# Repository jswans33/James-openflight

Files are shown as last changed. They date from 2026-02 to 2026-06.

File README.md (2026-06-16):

<p align="center">

  DIY Golf Launch Monitor using the OPS243-A Doppler Radar.
</p>

<p align="center">
  <a href="https://buymeacoffee.com/colemangolfs">
    
  </a>
</p>

> [!WARNING]
> **This project is in active development.** Features may be incomplete, unstable, or change without notice. Contributions and bug reports are welcome!

## Overview

OpenFlight is an open-source golf launch monitor that uses Doppler radar to measure ball speed, club speed, launch angle, spin rate, and carry distance.

### What It Measures

- **Ball Speed**: 35-200 mph range with ±0.5% accuracy (OPS243-A)
- **Club Speed**: Detected from pre-impact readings (OPS243-A)
- **Smash Factor**: Ball speed / club speed ratio
- **Launch Angle**: Vertical launch measured by K-LD7 angle radar
- **Club Path**: Horizontal aim direction measured by second K-LD7
- **Spin Rate**: Via rolling buffer I/Q analysis (the hardest radar measurement — see [Limitations](#limitations))
- **Carry Distance**: Computed from ball speed, launch angle, and spin

### Hardware at a Glance

| Component | What it does | ~Cost |
|---|---|---|
| OPS243-A Radar | Ball speed, club speed, spin | $249 |
| Raspberry Pi 5 | Runs everything | $60 |
| 7" Touchscreen | Shows shot data | $46 |
| SparkFun SEN-14262 | Impact sound trigger for shot capture | $18 |
| K-LD7 (×2) + FTDI adapters | Launch angle + club path | $140 |
| Power supply + accessories | | $27 |
| **Total** | | **~$540** |

> The K-LD7 angle radars are optional. Without them you still get ball speed, club speed, smash factor, spin rate, and estimated carry. See the [full parts list](docs/PARTS.md) for details and links.

## Getting Started

### 1. Get the parts

See the **[Parts List](docs/PARTS.md)** for everything you need with purchase links.

### 2. Wire it up

Follow the **[Sound Trigger Wiring Guide](docs/sound-trigger-wiring.md)** to connect the SEN-14262 to the OPS243-A. The K-LD7 modules connect via USB — no wiring needed.

### 3. Set up the Pi

Flash Raspberry Pi OS (64-bit), plug in the radars, then run the interactive setup:

```bash
git clone https://github.com/jewbetcha/openflight.git
cd openflight
./scripts/setup/setup.sh
```

The script installs everything and walks you through the one-time hardware
configuration (radar flash setup, K-LD7 device naming, auto-start) with
prompts — no manual config editing needed. It's safe to re-run any time.
See the **[Raspberry Pi Setup Guide](docs/raspberry-pi-setup.md)** for
details and troubleshooting.

### 4. Hit balls

```bash
# Default: rolling buffer mode with sound trigger
scripts/start-kiosk.sh

# With K-LD7 launch-angle geometry defaults
scripts/start-kiosk.sh --kld7-geometry

# Development mode (no hardware)
scripts/start-kiosk.sh --mock
```

Then open http://localhost:8080 or use the touchscreen.

### 5. Sync to the cloud (optional)

OpenFlight can push your sessions to the **FlightWeb** cloud so you can review
shots from any device. It's opt-in, and **raw radar data never leaves your
Pi** — only shot results and session metadata are uploaded (verify with
`openflight-cloud push --dry-run`).

`setup.sh` offers to enable this and link your Pi. To do it by hand:

```bash
openflight-cloud link       # pair this Pi (enter a short code in your browser)
openflight-cloud status     # linked? queued? parked?
```

Once linked, sessions sync automatically (on session end and via a ~10-minute
timer that heals wifi outages). See the **[Cloud Sync Guide](docs/cloud-sync.md)**
for details.

### TV Display Mode

OpenFlight also serves a fullscreen-friendly browser display for tablets, TV browsers, or a Chrome tab cast to Chromecast.

1. Start OpenFlight as usual with `scripts/start-kiosk.sh`.
2. Find the OpenFlight host IP address on your LAN.
3. Open `http://<openflight-host-ip>:8080/display` from another laptop, tablet, or TV browser.
4. For Chromecast, open the display page in Chrome and use Chrome's built-in **Cast** feature to cast the tab.

This is browser/tab casting only. OpenFlight does not include native Cast SDK support yet.

## How It Works

### System Architecture

```
┌─────────────┐  USB/Serial  ┌─────────────┐  Callback   ┌─────────────┐  WebSocket  ┌─────────────┐
│  OPS243-A   │ ───────────▶ │   Rolling   │ ──────────▶ │   Flask     │ ──────────▶ │   React     │
│   Radar     │  I/Q buffer  │   Buffer    │  on_shot()  │   Server    │   "shot"    │     UI      │
└─────────────┘              │   Monitor   │             └─────────────┘             └─────────────┘
                             └─────────────┘
                                                               ▲
┌─────────────┐  USB/Serial                                    │
│ K-LD7 (×2)  │ ──────────────────── angle data ──────────────┘
│ Angle Radar │
└─────────────┘
```

1. **Sound trigger fires** — SEN-14262 detects club impact, triggers OPS243-A HOST_INT
2. **OPS243-A dumps buffer** — Rolling buffer I/Q data is captured and analyzed for ball speed, club speed, and spin
3. **K-LD7 correlates** — The server uses the OPS243-A impact timestamp to find the matching ball burst in the K-LD7 ring buffer, extracting launch angle and club path
4. **Carry computed** — Ball speed + spin + launch angle → carry distance
5. **UI updates** — Shot data emitted via WebSocket to the React frontend

### Doppler Radar Basics

The OPS243-A transmits a 24 GHz signal. When it bounces off a moving object (the golf ball), the frequency shifts proportionally to the object's speed — this is the Doppler effect. At 24.125 GHz, each 1 mph of speed creates a ~71.7 Hz Doppler shift.

### Positioning

Place the radar **3-5 feet behind the tee**, pointing at the hitting area:

```
                Ball Flight Direction
                ======================>

[Tee]  ←--- 3-5 ft ---→  [OPS243-A]  [K-LD7 vertical]  [K-LD7 horizontal]
```

The K-LD7 modules are positioned near the OPS243-A, one mounted vertically (launch angle) and one horizontally (club path / aim direction).

## Configuration

### Radar Settings for Golf

| Setting | Value | Why |
| --- | --- | --- |
| Mode | Rolling buffer | Raw I/Q capture for spin + precise speeds |
| Sample Rate | 30 ksps | Supports up to ~208 mph ball speed |
| Capture | 4096 I/Q samples | ~136 ms around impact |
| Trigger | Sound (SEN-14262) | ~10 µs hardware latency via HOST_INT |
| Min Ball Speed | 35 mph | Filter club waggle and slow movements |
| DC Mask | ~15 mph exclusion zone | Reject body movement and environmental noise |

These are applied automatically — the one-time flash configuration is handled
by the setup script.

### Python API

```python
from openflight.rolling_buffer import RollingBufferMonitor

monitor = RollingBufferMonitor()   # auto-detects the OPS243-A
monitor.connect()
monitor.start()

print("Swing when ready...")
shot = monitor.wait_for_shot(timeout=60)
if shot:
    print(f"Ball Speed: {shot.ball_speed_mph:.1f} mph")
    print(f"Est. Carry: {shot.estimated_carry_yards:.0f} yards")

monitor.stop()
monitor.disconnect()
```

## Limitations

- **Cosine error**: If ball doesn't travel directly toward/away from radar, measured speed will be slightly lower than actual
- **Spin detection**: The hardest radar measurement, especially indoors — the usable signal window ends when the ball hits the net, and short windows can't resolve low spin (commercial radar units have the same constraint and fall back to estimated spin indoors). Low driver-band readings (≤~3100 RPM) are reported at reduced confidence. When spin isn't measured, carry falls back to club-typical spin values. Improving this is an active focus.
- **K-LD7 speed aliasing**: The K-LD7 max speed is 62 mph, so it's used only for angle/distance, not speed

### Ball Markings

Reflective markings (aluminum stickers, painted dots) noticeably improve K-LD7 launch-angle extraction — the stronger return gives multi-frame tracking, higher SNR, and more confident angles. However, a specular patch produces a pulsed, non-sinusoidal amplitude modulation that the spin detector can't interpret as seam modulation, so measured spin degrades (typically locks to the top of the valid frequency band with low confidence). Low-confidence spin automatically falls back to club-typical values in the ballistics model, so the net effect of marking a ball is better angles with no worse carry estimates. A thin painted stripe (rather than a patch) is a reasonable middle ground if you want both — it rotates through the beam more like a seam.

## Hardware Diagnostic

To verify every component of your build in one shot:

```bash
uv run python scripts/hardware-test/diagnose.py
```

The diagnostic walks through 6 checks:
1. OPS243 connectivity
2. OPS243 rolling buffer mode persistence
3. OPS243 software trigger
4. K-LD7 vertical (launch angle)
5. K-LD7 horizontal (aim direction, optional)
6. Sound trigger end-to-end (interactive — prompts you to clap near the sensor)

Missing optional hardware (like the horizontal K-LD7) is reported as a skip rather than a failure. Pass `--require-all` to fail on skips, or `--no-interactive` to skip the sound-trigger prompt in unattended runs.

## Project Structure

```
openflight/
├── src/openflight/
│   ├── ops243.py              # OPS243-A radar driver
│   ├── launch_monitor.py      # Shot detection & club/ball separation
│   ├── server.py              # Flask server, K-LD7 correlation, carry
│   ├── session_logger.py      # JSONL session logging
│   ├── kld7/                  # K-LD7 angle radar
│   │   ├── radc.py            # FFT, phase interferometry, angle extraction
│   │   ├── tracker.py         # Ring buffer, shot correlation
│   │   ├── geometry.py        # Launch-angle trajectory fitting
│   │   └── types.py           # Data types
│   └── rolling_buffer/        # Spin rate detection
│       ├── monitor.py         # Rolling buffer monitor
│       ├── processor.py       # I/Q processing for spin
│       ├── trigger.py         # Trigger strategies
│       └── types.py           # Data types
├── ui/                        # React frontend
├── scripts/                   # Utility & setup scripts
├── docs/                      # Documentation
└── pyproject.toml
```

## Contributing

Contributions welcome! See [CONTRIBUTING.md](CONTRIBUTING.md) for guidelines.

Areas of interest:

- **Better spin detection**: A dechirped Doppler-sideband estimator is in development (`scripts/analysis/replay_spin_dechirp.py`) — help validating it against launch-monitor truth data is especially welcome
- **K-LD7 signal processing**: Improve ball detection from sparse radar frames
- **Mobile app**: Bluetooth connection to phone

### Running Tests

```bash
uv run pytest tests/ -v
```

## Documentation

- **[Parts List](docs/PARTS.md)** — What to buy
- **[Sound Trigger Wiring](docs/sound-trigger-wiring.md)** — How to wire the sound trigger
- **[Raspberry Pi Setup](docs/raspberry-pi-setup.md)** — Full setup guide
- **[Cloud Sync](docs/cloud-sync.md)** — Push filtered sessions to FlightWeb
- **[Rolling Buffer & Spin Detection](docs/rolling_buffer_spin_detection.md)** — Spin measurement details
- **[Dechirped-Sideband Spin Replay](docs/spin-dechirp-replay.md)** — Next-gen spin estimator test bench
- **[K-LD7 Ball Detection Theory](docs/kld7-ball-detection-theory.md)** — How angle detection works
- **[K-LD7 Session Review](docs/kld7-session-review.md)** — Offline review workflow for session JSONL files
- **[Observability & Log Shipping](docs/observability.md)** — Ship logs to Grafana Cloud
- **[Contributing Guide](CONTRIBUTING.md)** — How to contribute
- **[Changelog](docs/CHANGELOG.md)** — Version history

## License

GNU Affero General Public License v3.0 or later (AGPL-3.0-or-later) - see LICENSE file.

## Acknowledgments

- [OmniPreSense](https://omnipresense.com/) for the OPS243-A radar and documentation
- The golf hacker community for inspiration

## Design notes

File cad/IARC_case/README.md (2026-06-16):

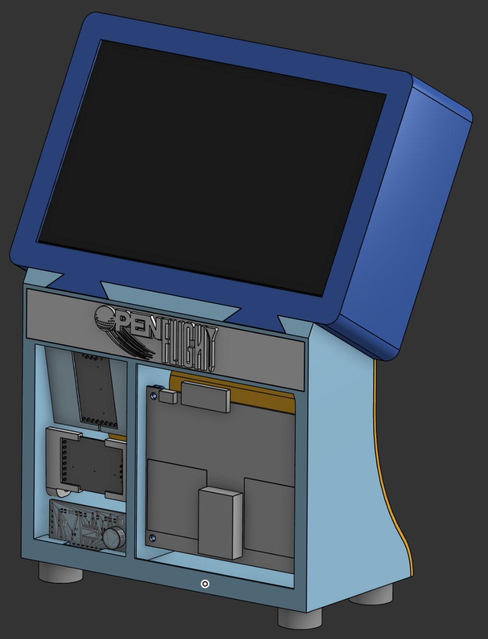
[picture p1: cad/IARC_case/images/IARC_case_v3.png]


- M5 Bolts needed: 10
- M2.5 Bolts needed: 12

Instructions for OpenFlight IARC v3 Case Build
  
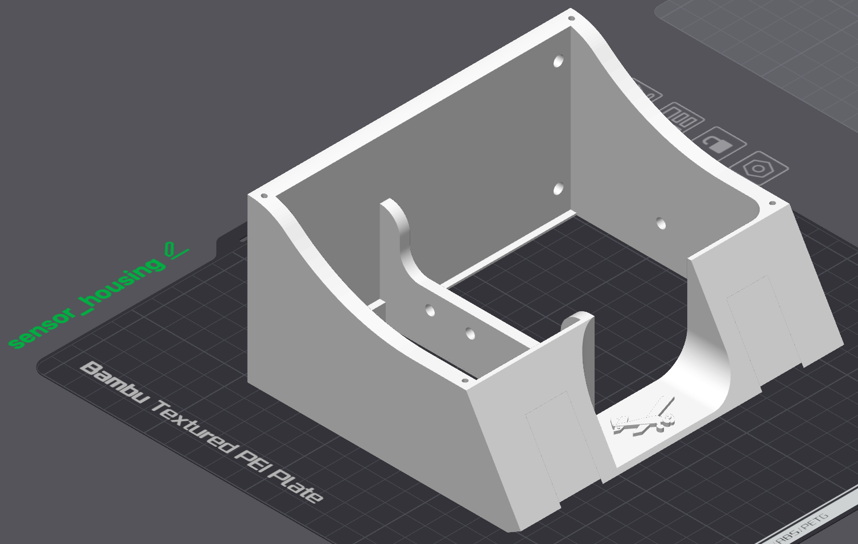
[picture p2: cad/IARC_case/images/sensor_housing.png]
1. Print out `sensor_housing.stl` 
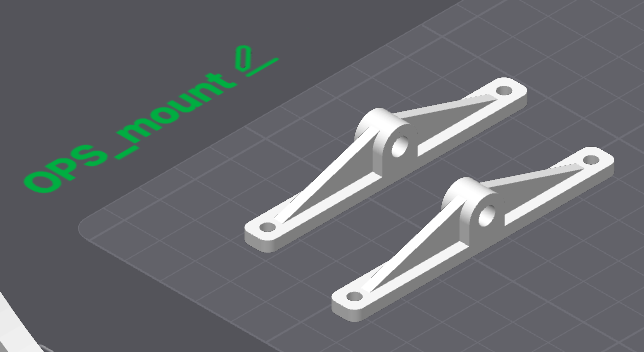
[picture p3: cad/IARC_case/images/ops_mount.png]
2. Print out (2x) `OPS_mount.stl` 
3. Secure the OPS sensor to each `OPS_mount.stl` part with screws (I don't know which ones)
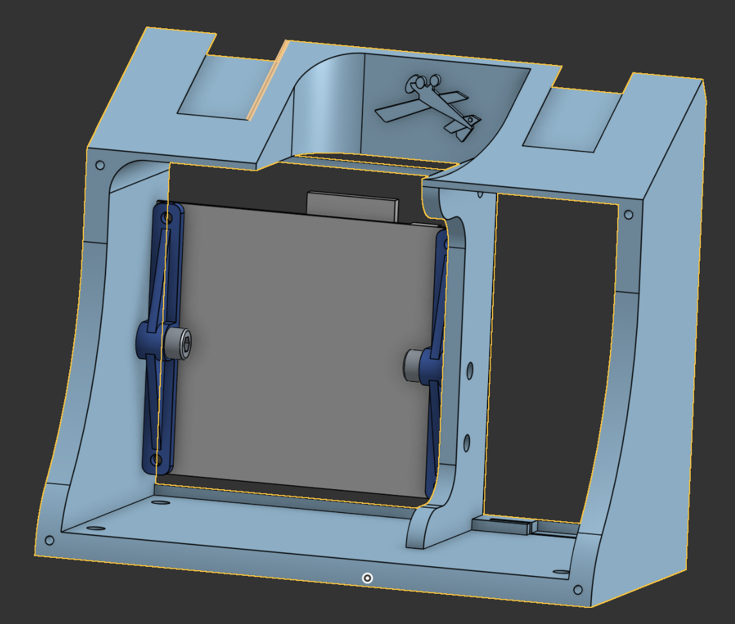
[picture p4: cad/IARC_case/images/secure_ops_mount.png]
4. Secure the `OPS_mount.stl` parts to the `sensor_housing.stl` part with (2x) M5 bolt 
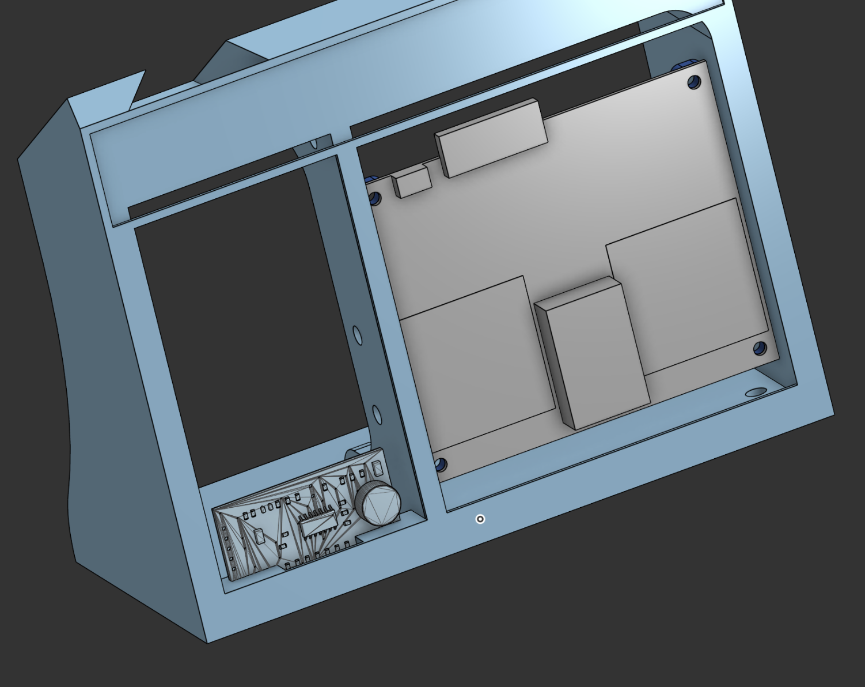
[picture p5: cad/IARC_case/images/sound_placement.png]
5. Fit the sound sensor into the little slot on the left side of the `sensor_housing.stl` part. 
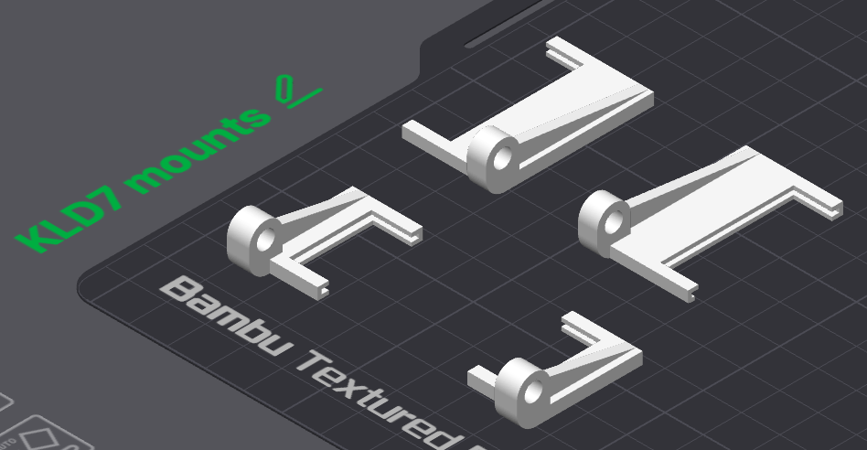
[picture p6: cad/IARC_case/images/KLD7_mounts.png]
6. Print out (1x) `KLD7_h_mount_L_v2.stl` and (1x) `KLD7_h_mount_R_v2.stl` 
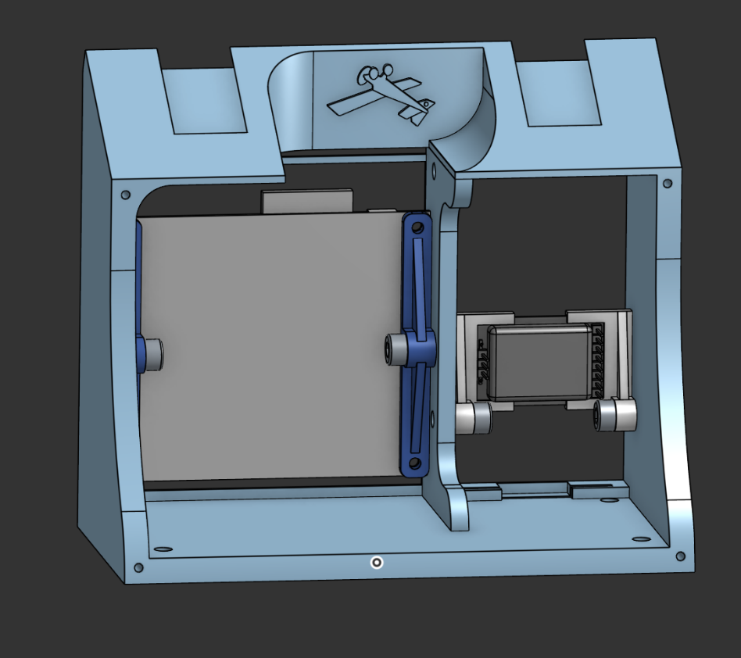
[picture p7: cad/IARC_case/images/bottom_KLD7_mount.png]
7. Slot a KLD7 sensor between the mount parts, and secure them to the `sensor_housing.stl` part with (2x) M5 bolt 
8. Print out (1x) `KLD7_v_mount_L_v2.stl` and (1x) `KLD7_v_mount_R_v2.stl` 
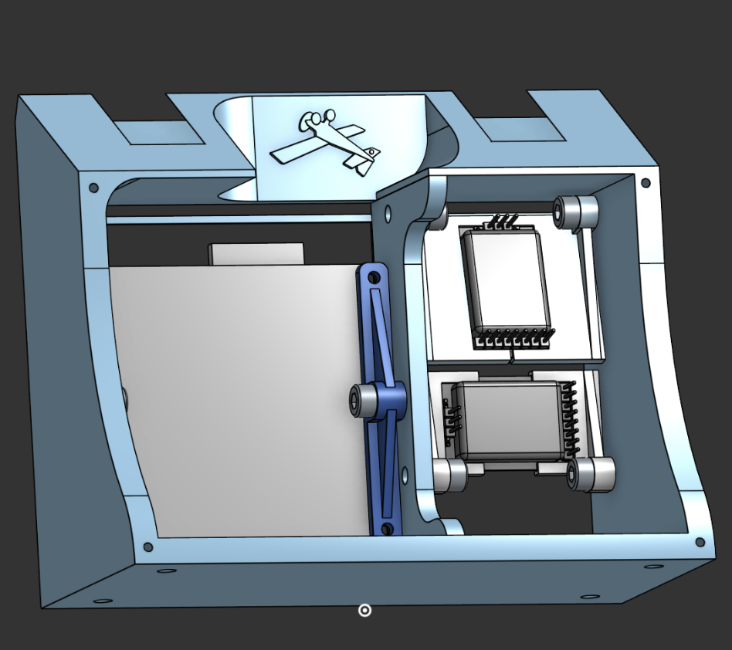
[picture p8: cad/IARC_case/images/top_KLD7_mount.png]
6. Slot a KLD7 sensor between the mount parts, and secure them to the `sensor_housing.stl` part with (2x) M5 bolt 
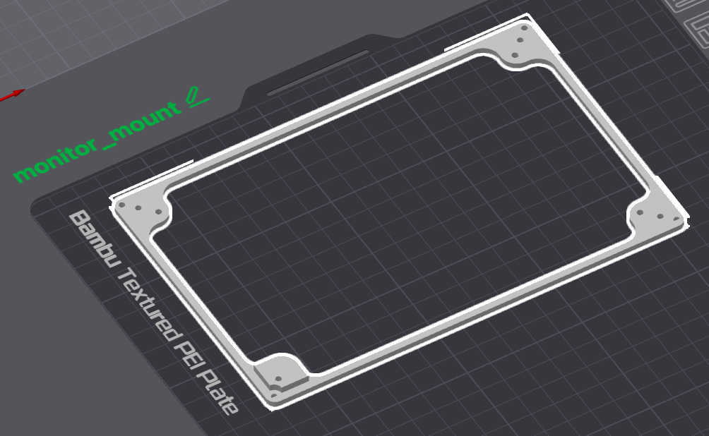
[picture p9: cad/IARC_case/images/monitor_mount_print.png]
7. Print out the `monitor_mount.stl` part. 
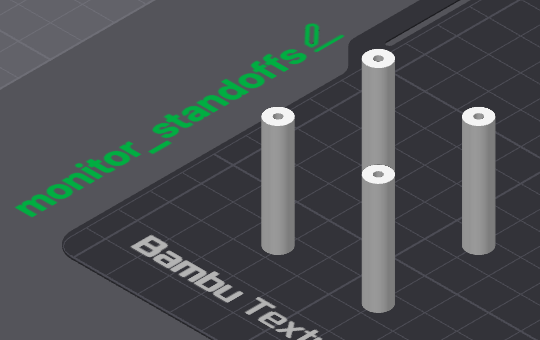
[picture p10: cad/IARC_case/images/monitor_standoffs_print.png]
8. Print out (4x) `monitor_standoffs.stl`'s. 
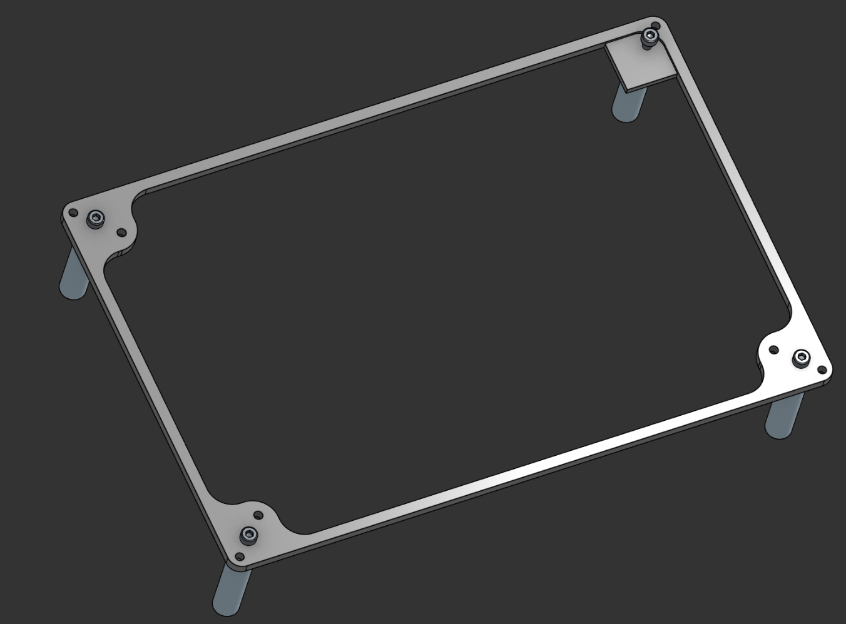
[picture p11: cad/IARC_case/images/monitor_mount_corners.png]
9. Secure each `monitor_standoff.stl` part to the corners of the `monitor_mount.stl` part with (1x) M2.5 bolt. 
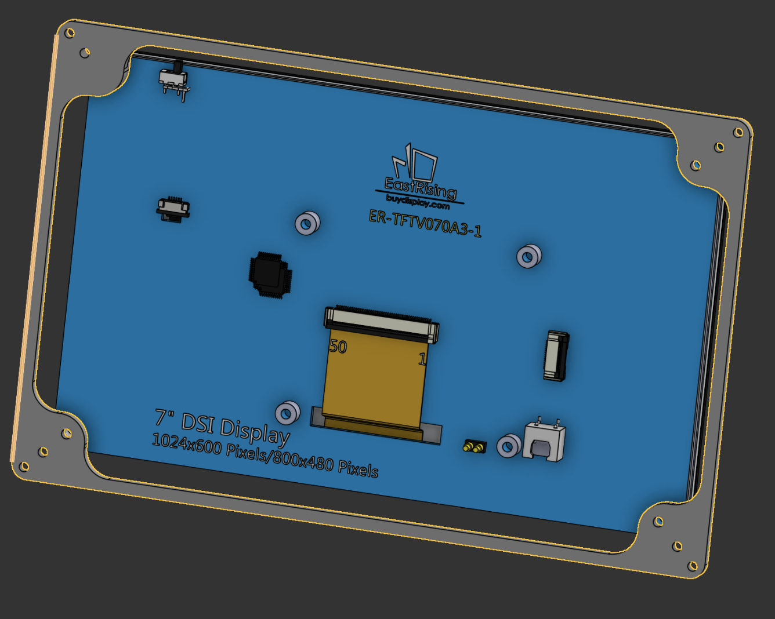
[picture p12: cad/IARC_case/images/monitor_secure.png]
10. Secure the monitor to the `monitor_mount.stl` part. 
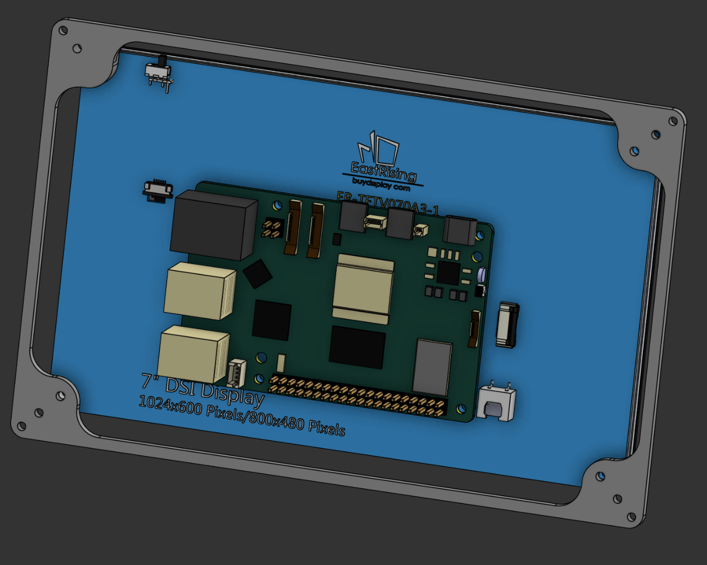
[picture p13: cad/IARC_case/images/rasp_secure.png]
11. Secure the raspberry Pi to the monitor. 
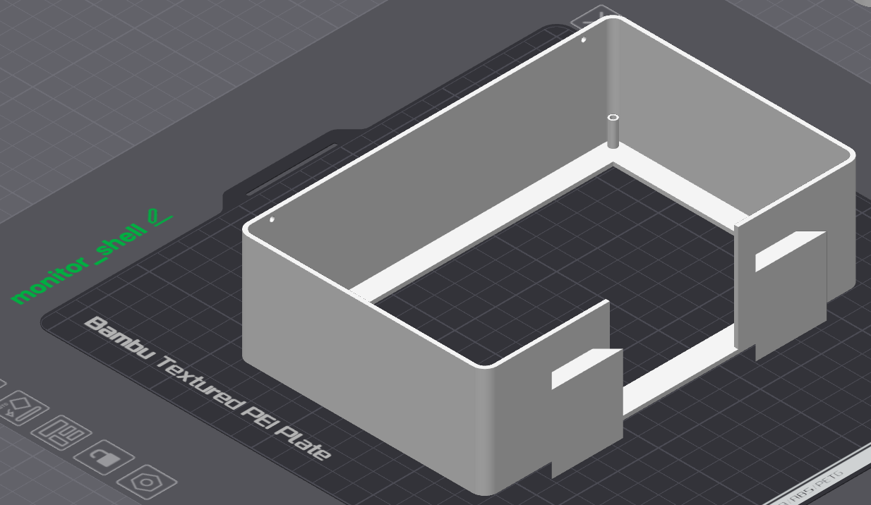
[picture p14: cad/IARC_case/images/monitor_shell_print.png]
12. Print out the `monitor_shell.stl` part. 
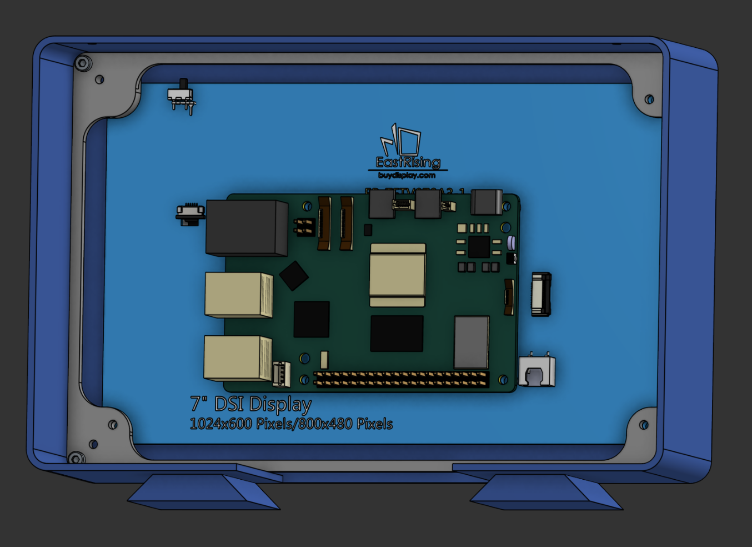
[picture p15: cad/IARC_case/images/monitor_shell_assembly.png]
13. Secure the monitor assembly inside the `monitor_shell.stl` part with (4x) M2.5 bolts at the corners. 
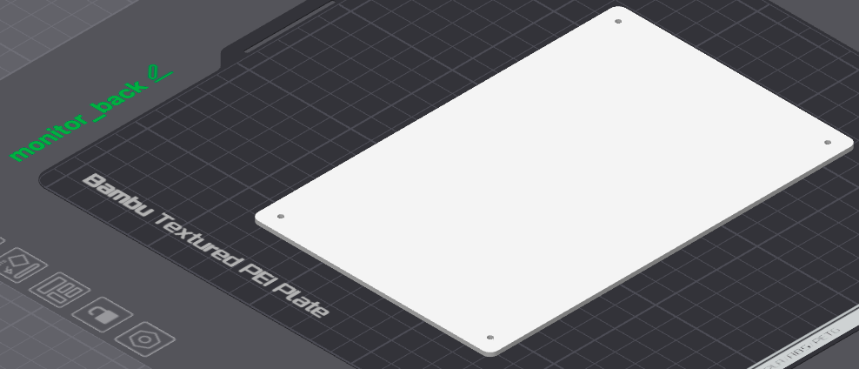
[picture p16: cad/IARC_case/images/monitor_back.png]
14. Print out the `monitor_back.stl` part. 
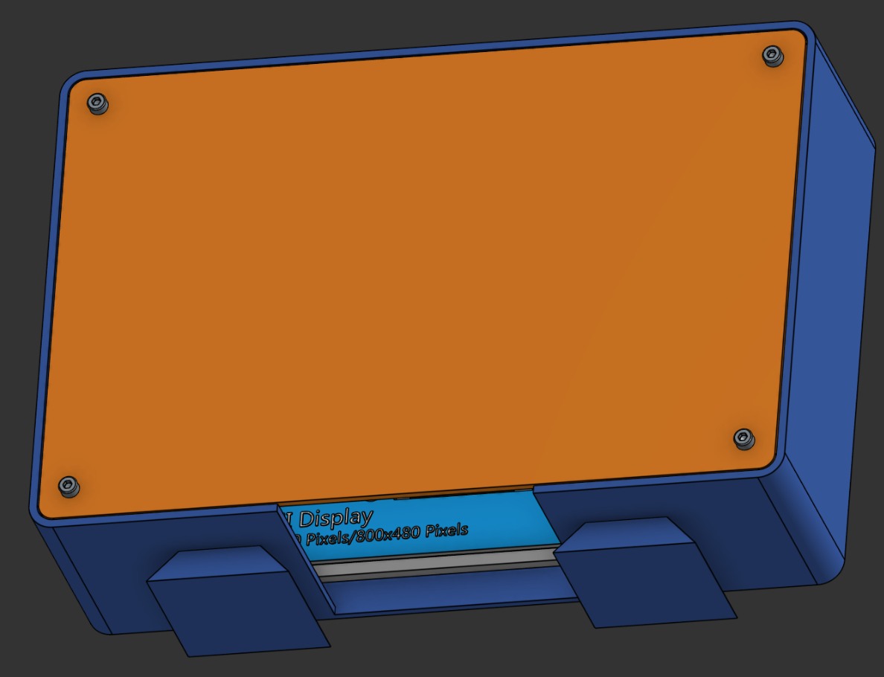
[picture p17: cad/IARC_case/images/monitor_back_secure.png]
15. Secure the `monitor_back.stl` part to the `monitor_standoffs.stl` parts with (4x) M2.5 bolts. 
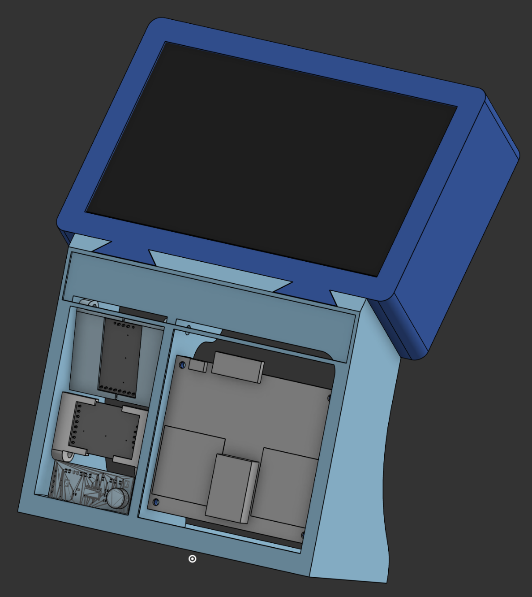
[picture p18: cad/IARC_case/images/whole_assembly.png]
16. Slide the whole assembly into the sensor housing assembly, using the dovetails to align everything together. 
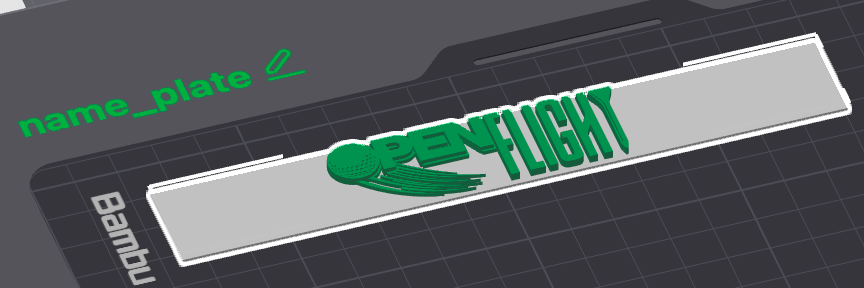
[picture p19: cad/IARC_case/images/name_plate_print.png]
17. Print out the `name_plate.stl` file. 
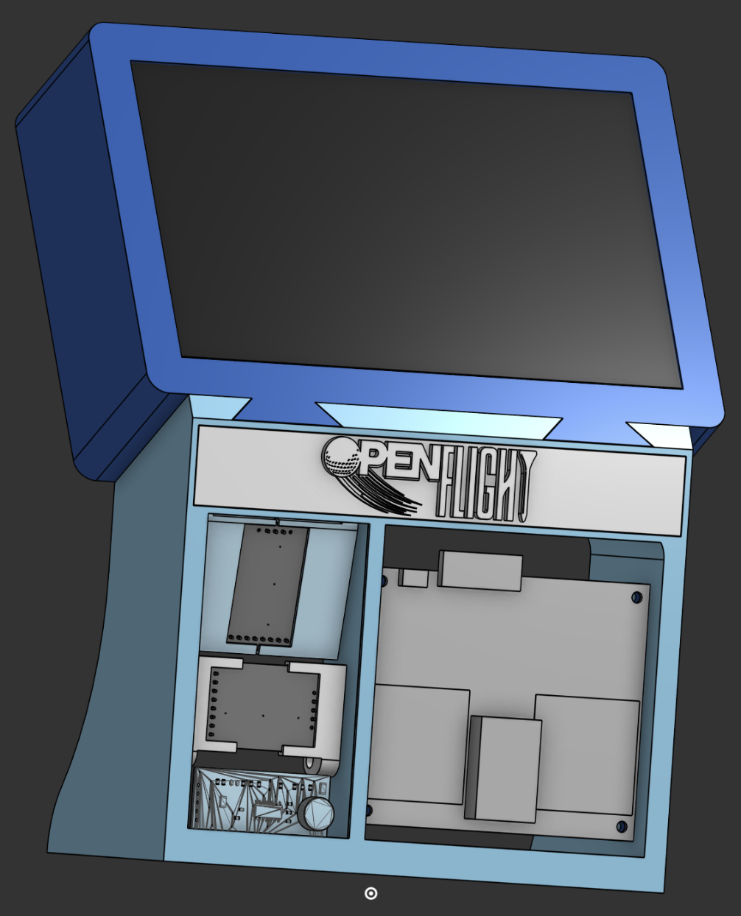
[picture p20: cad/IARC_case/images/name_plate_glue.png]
18. Secure the `name_plate.stl` file to the front of the whole assembly with glue. 
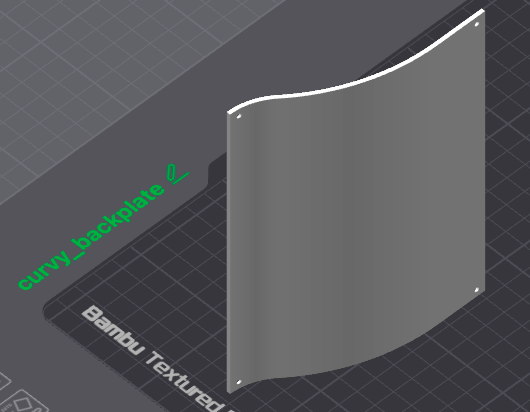
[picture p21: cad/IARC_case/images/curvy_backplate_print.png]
19. Print out the `curvy_backplate.stl` file. 
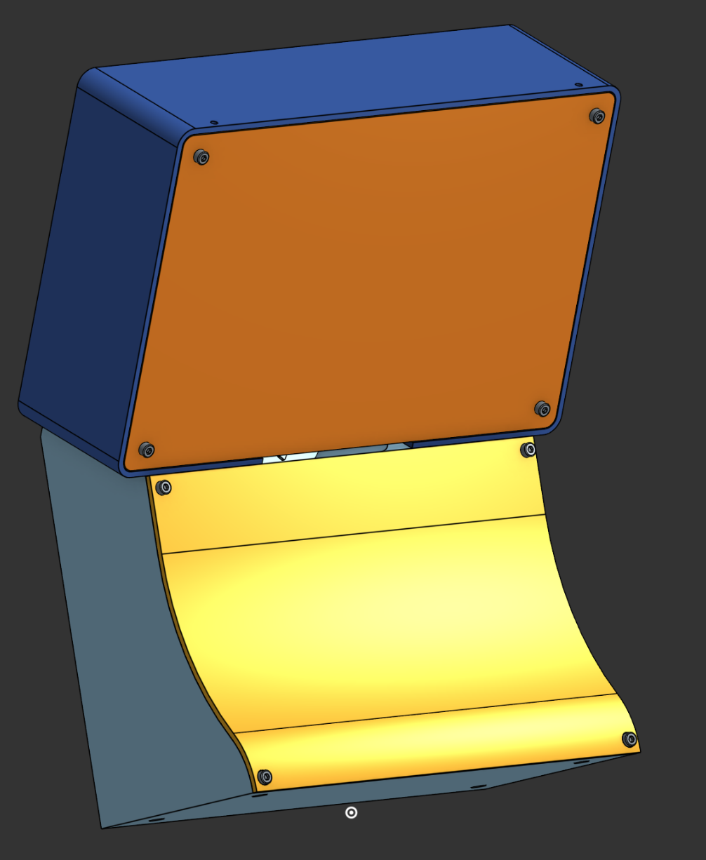
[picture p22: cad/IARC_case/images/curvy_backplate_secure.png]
20. Secure the `curvy_backplate.stl` file to the whole assembly with (4x) M2.5 bolts. 
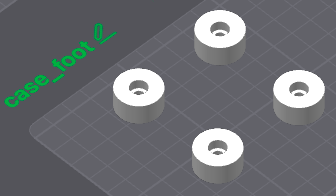
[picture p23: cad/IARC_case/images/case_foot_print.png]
21. Print out (4x) `case_foot.stl` parts. 
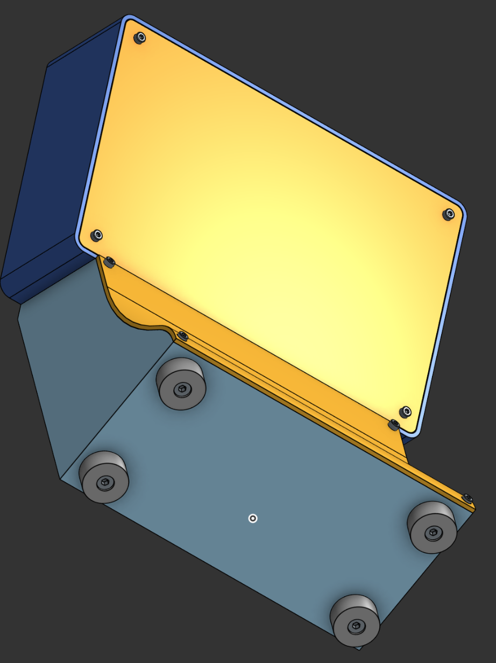
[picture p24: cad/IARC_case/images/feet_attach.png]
22. Secure each foot to the bottom of the whole assembly with (4x) M5 Bolts. 

And that’s how you put together the 3d printed parts!

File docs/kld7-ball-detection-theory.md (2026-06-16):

# K-LD7 Ball Detection Theory

## Problem

The RFbeam K-LD7 is being used to estimate launch angle and club angle of attack
from raw `PDAT` and `TDAT` frames captured during a golf swing. The hard part is
not whether the radar sees *anything* during a swing. It does. The hard part is
separating the brief golf-ball return from stronger club, body, and net returns.

The four captures in `session_logs/` confirmed that the ball data is present, but
it does not appear as the strongest target in the raw stream. A simple
"highest-magnitude target wins" rule is wrong for this use case.

## Why The Raw Radar Data Is Tricky

### 1. Speed aliases at golf-ball velocity

The K-LD7 max speed setting is `100 km/h`. Golf balls travel much faster than
that, so the reported speed is aliased and cannot be trusted as a true physical
ball speed. This means the detector must treat speed as a *weak filter* rather
than a direct measurement.

Practical implication:

- `speed` can be used to reject obviously slow clutter
- `speed` cannot be used to estimate actual launch speed
- `distance` and `timing` matter more than `speed`

### 2. The ball only exists for a few frames

At the current radar settings the frame rate is roughly `34 fps`, so a full-speed
ball often appears in only `1-3` frames. By contrast, the golfer's body, club,
and follow-through can occupy many more frames and often produce stronger returns.

Practical implication:

- `TDAT` alone is not enough
- `PDAT` is the primary source for the ball
- the detector must be built around short bursts, not long tracks

### 3. A single "ball burst" can still contain multiple far targets

Even after filtering for far-range, fast targets, a burst can still contain
multiple plausible `PDAT` returns in the same frame. These likely come from a
mix of ball, net, multipath, and other transient reflections. Averaging every
qualifying far target together smears the angle and produces unstable output.

Practical implication:

- burst selection is not enough
- one coherent target path must be chosen *inside* the burst

## What The Captures Showed

Across the four captures, the most repeatable signature was:

1. A close-range speed transition at roughly `0.8-2.5 m`
2. Followed `120-350 ms` later by a far-range burst at roughly `4.1-4.6 m`
3. The far-range burst usually carried lower magnitude than the club event

This pattern is the key breakthrough. The ball should not be found by asking
"what is strongest in the whole buffer?" It should be found by asking:

> "What plausible far-range burst appears immediately after a plausible club event?"

That turns the detection problem from one giant classification problem into a
sequence problem.

## Detector Strategy

The current detector is built around four stages.

### Stage 1: Ball candidate filter

A target is considered a possible ball only if it is:

- fast enough to reject slow clutter
- far enough away to avoid close-range club/body returns
- strong enough to avoid obvious noise

In code this is the far-range, fast-target filter in
`src/openflight/kld7/tracker.py`.

### Stage 2: Burst formation

Qualifying ball targets are grouped into bursts when consecutive frames are close
enough in time. This reflects the physical reality that a struck ball should
appear as a brief transient event, not a long-lived track.

### Stage 3: Coherent target selection inside the burst

This is the major correction to the original approach.

Instead of magnitude-weighting *every* far target in the burst, the detector now
scores target-to-target continuity across frames:

- small angle jumps are preferred
- small distance jumps are preferred
- higher magnitude still helps, but only after continuity

That produces a single coherent far-target path. The launch angle is then
computed from that path, not from the union of all far targets.

This matters because many noisy bursts contained both reasonable and obviously
bad far-angle candidates. A plain weighted average would blend them together.

### Stage 4: Club-to-ball pairing

For offline analysis, the tracker now pairs:

- a close-range club transition
- with the best far-range burst that appears shortly after it

The pairing window is currently:

- minimum delay: `80 ms`
- maximum delay: `350 ms`

That window came from the real captures, not from arbitrary tuning.

## Why The Live Path Needed A Timestamp Fix

The K-LD7 selector used to receive `time.time()` when the server callback fired.
That callback runs *after* the OPS243 shot has already been buffered and processed,
which means the timestamp can lag the true impact moment.

This made burst selection weaker than it needed to be. If the radar is choosing
the burst closest to a delayed callback time, it may bias toward the wrong burst
inside a busy ring buffer.

The live path now carries the OPS243 peak ball-reading timestamp through the
`Shot` object and uses that impact timestamp when correlating K-LD7 data.

## What This Solves

This work materially improves three things:

### 1. Reproducibility

The repo now has an offline command:

```bash
PYTHONPATH=src .venv/bin/python scripts/analysis/analyze_kld7.py <capture.pkl> --pair-shots
```

That prints probable club-to-ball pairs from a long capture. This turns the
provided `.pkl` files into a repeatable analysis workflow.

### 2. Angle stability

The detector no longer collapses multiple far targets into one weighted average.
It picks a coherent path first, which reduces angle smearing on noisy bursts.

### 3. Better live correlation

K-LD7 is now aligned to the real OPS243 impact time rather than delayed callback
time, which is a better proxy for when the ball should appear in the K-LD7 buffer.

## What This Does Not Solve Yet

This is a strong improvement, but it is not a magic classifier.

Open problems:

- Some bursts still produce high-angle outliers
- Multipath and net reflections still exist in the far range
- The K-LD7 still provides only a handful of frames per shot
- Reported `speed` is still aliased and should not be treated as truth

The detector now exposes these cases more honestly through lower confidence or
through unusual paired angles, rather than hiding them behind a bad average.

## Practical Next Steps

The next highest-leverage improvements are:

1. Collect more labeled captures with known shot counts and club types
2. Add per-club angle priors so obviously impossible candidates are penalized
3. Compare radar-derived launch angle against camera-derived angle on the same shots
4. Log the chosen coherent target path for each shot, not just the final summary

## Evidence From The Current Captures

The strongest labeled validation so far is:

- `session_logs/kld7_capture_20260402_135117-wedge.pkl`
- metadata says `expected_shots = 5`
- the current `find_probable_shots()` heuristic returns `5`

That does not prove the angles are perfect, but it is a strong sign that the
sequence logic is isolating real shot events rather than random clutter.

## Capture Snapshot

Running the offline analyzer with:

```bash
PYTHONPATH=src .venv/bin/python scripts/analysis/analyze_kld7.py <capture.pkl> --pair-shots
```

currently produces:

| Capture | Club label | Expected shots | Probable shots found | Notes |
| --- | --- | ---: | ---: | --- |
| `kld7_capture_20260402_134323-wedge.pkl` | unlabeled | unknown | 4 | All pairings follow the `283-346 ms` club-to-ball pattern |
| `kld7_capture_20260402_135117-wedge.pkl` | `wedge` | 5 | 5 | Best current regression file; includes two higher-angle far-burst outliers |
| `kld7_capture_20260402_135243-7i.pkl` | unlabeled | unknown | 5 | Cleanest mixed set of moderate-confidence 7-iron candidates |
| `kld7_capture_20260402_135412-7i.pkl` | unlabeled | unknown | 6 | Strongest confidence scores overall, plus one obvious high-angle outlier |

This gives two useful conclusions:

1. The detector is consistently finding shot-like club-to-ball sequences across
   all four recordings, not just in one cherry-picked file.
2. The remaining errors are now visible as specific outlier pairings, which is
   much easier to improve than a detector that hides bad returns inside a broad
   weighted average.

## Remaining Failure Mode

The dominant remaining failure mode is not missing shots. It is selecting a
real far-range burst whose angle is physically implausible for the club or
range setup.

Examples from the current captures include:

- `63.2°` and `63.1°` candidates in `kld7_capture_20260402_135117-wedge.pkl`
- `79.4°` in `kld7_capture_20260402_135412-7i.pkl`

Those detections are useful because they point to the next filter to add:
keep the sequence logic, then penalize far-burst paths whose launch angle is
incompatible with the expected club window or with a camera-derived reference.

## Live False-Positive Guard

The live path now applies a wide club-and-speed sanity check before trusting a
K-LD7 vertical launch angle.

The logic is intentionally conservative:

- compute the expected launch angle from the selected club and OPS243 ball speed
- allow a wide club-family-specific error window
- reject only radar angles that are far outside that window
- fall back to the existing club-and-speed estimate when the radar angle is not plausible

This is not a precision tuning mechanism. It is a guardrail against obvious
false positives.

## Why This Guard Is Defensible

The repo already contains a real backyard session log with shot speed and launch
data:

- `session_logs/session_20260402_121507_range.jsonl`

Auditing the `11` driver shots in that log against the club-and-speed launch
model shows:

- `8` shots are already within the expected guardrail
- `3` shots are clear outliers: shots `3`, `9`, and `11`

Those outliers are not minor disagreements. Their launch angles are roughly
`23-30°` away from what the selected club and ball speed predict.

That is exactly the kind of error this guard is meant to catch.

## What The Guard Catches In The Current Captures

Using broad club-family priors on the provided K-LD7 captures:

- `kld7_capture_20260402_135117-wedge.pkl` flags the two `~63°` wedge candidates as suspect
- `kld7_capture_20260402_135412-7i.pkl` flags the `79.4°` 7-iron candidate as suspect
- moderate but still plausible shots such as `40.3°` on one 7-iron capture remain accepted

That is the desired behavior for this stage:

- reject the obvious false positives
- keep the plausible-but-imperfect shots
- avoid overfitting to these four files

## Future angle-extraction improvements (literature backed)

The K-LD7 has only **2 receive antennas per axis**. Phase-comparison
monopulse on a 2-element array is the absolute floor of array-radar
DOA estimation: every multi-element technique (MUSIC, ESPRIT,
beam-space MUSIC, Capon, beamforming) requires ≥3 elements. That is
why TrackMan and FlightScope ship 16-26-element phased arrays. With
2 channels we are fundamentally limited to one unambiguous angle per
range/Doppler bin, and our angle accuracy is bounded by the
Cramér-Rao lower bound, which scales as `1 / (SNR · √N_snapshots)`.

A literature-backed list of improvements that are still possible
inside the 2-channel envelope, in roughly increasing implementation
cost:

### Done — multi-bin centroid angle (Zhang et al., Sensors 2016)

The per-frame angle is the magnitude²-weighted centroid of the
per-bin angles inside the spectral peak (bins above
`centroid_floor_frac × peak`, within `CENTROID_SEARCH_BINS` of the
peak bin), rather than the raw angle at a single peak bin. For a
range-spread target whose energy spreads across several FFT bins
(Hann-window leakage and intra-frame Doppler smear), this integrates
the angle estimate across all the energy in the peak. Implemented
in `extract_launch_angle`.

Reference: Zhang, Y. et al. *A Novel Monopulse Angle Estimation
Method for Wideband LFM Radars*, Sensors 2016, 16(6):817 (PMC4934243).

### Future — use the F2 frequency channel (delta-frequency interferometry)

The K-LD7 RADC layout reserves channels for `f1a`, `f2a`, **`f1b`**.
We currently process only `f1a` and `f2a` (I/Q at the radar's first
carrier frequency). RFbeam's second carrier (`f1b`) is what enables
**target ranging** and **angle-disambiguation** through *delta-
frequency interferometry*: the phase difference at two slightly
different carriers gives an independent angle estimate via a
different baseline. Combining the two estimates is well-studied for
synthetic-aperture radar — see GAMMA Remote Sensing's processing
notes (`docs/refs/...` once we save them) and any standard
multi-frequency InSAR tutorial.

Cost: medium. We need to confirm the K-LD7 carrier spacing is
documented well enough to use, and we need to handle 2π
disambiguation between the two estimates.

### Future — joint Doppler-DOA maximum-likelihood estimation

Instead of `FFT → pick peak bin → read phase`, do a joint
maximum-likelihood search over `(velocity, angle)` directly on the
two-channel raw I/Q. The cost function is the negative log-likelihood
of the 2-channel signal given a complex sinusoid at angular velocity
`ω` with phase difference `φ`. For a 256-sample frame this is a tiny
2D grid search and is provably optimal at low SNR / few-snapshot
scenarios — exactly our regime.

Reference: Joint Doppler and DOA Estimation Using (Ultra-)Wideband
FMCW Signals, Signal Processing 165 (2019), 105–122.

Cost: high. New code path, careful initialisation to avoid local
minima, and we need to verify wall-clock cost on the Pi against the
real-time budget.

### Future — multi-frame phase tracking

When the ball is visible for 2-3 frames in a row, its angle should be
approximately constant (it's flying in a straight line over ~50 ms).
Add a constant-or-linear angle model fit across the cluster, with
SNR-weighted least squares. Reject frames whose estimate disagrees
by `>Nσ` from the joint fit. This is essentially what Kalman-filter-
based radar trackers do; in our setup it is a small change once we
have a working per-frame estimator we trust.

Cost: low, but only worth doing once the per-frame estimator is
solid. Currently the ball is only visible 1-2 frames per shot for
fast-ball captures, so there is rarely enough data to fit.

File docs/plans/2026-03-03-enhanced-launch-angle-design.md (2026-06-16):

# Enhanced Launch Angle Estimation Design

## Problem

The camera-based launch angle measurement is fragile (Hough circle detection, depth estimation heuristics, lighting sensitivity). The fallback is a per-club lookup table that only uses ball speed, producing low-confidence estimates. Additionally, launch angle is never used in carry distance calculation -- it only affects the uncertainty band width.

## Goal

Improve launch angle estimation using data we already collect (smash factor, spin rate), and wire launch angle into the carry distance model. Target: 3-5 degree accuracy for normal swings, with honest confidence signaling.

## Design

### 1. Enhanced `estimate_launch_angle()`

**Location:** `server.py` (existing function)

**Current inputs:** club type, ball speed
**New inputs:** club type, ball speed, club_speed (optional), spin_rpm (optional)

**Smash factor adjustment:**
Smash factor (ball_speed / club_speed) indicates strike quality. For each club category, there's an optimal smash factor. Deviation from optimal shifts the launch angle estimate:

- Low smash (thin/toe) -> lower launch. ~0.3-0.5 deg per 0.01 smash below optimal.
- High smash (slight up-on-it for driver) -> slightly higher launch. ~0.2 deg per 0.01 above optimal.

Optimal smash factors by club category:
- Driver: 1.48
- Fairway woods: 1.42-1.45
- Hybrids: 1.36-1.40
- Irons: 1.33-1.38
- Wedges: 1.20-1.25

**Spin rate adjustment (when available):**
Spin correlates with launch angle. High spin + low smash = thin topped (very low launch). High spin + high smash = high-launching iron. Use spin deviation from optimal as a secondary signal, weighted less than smash factor.

**Confidence model:**
- Ball speed only: 0.2
- Ball speed + smash factor: 0.35
- Ball speed + smash factor + spin: 0.5

### 2. Launch angle carry adjustment

**Location:** New function in `launch_monitor.py`

Each club has an optimal launch angle (from TrackMan data, already in the lookup table). Deviation from optimal costs carry:

- Too low: -2.0 yards per degree below optimal (ball doesn't get enough height)
- Too high: -1.5 yards per degree above optimal (ball balloons, less severe due to Magnus lift)
- Cap: 10% max penalty to prevent wild swings from bad estimates
- Apply confidence weighting: scale the adjustment by launch angle confidence so low-confidence estimates produce smaller corrections

### 3. Integration into Shot carry calculation

Wire into `Shot.estimated_carry_yards` and `Shot.estimated_carry_range`:
- If launch angle is available, apply the angle-based carry adjustment
- Update `estimated_carry_range` to reflect the tighter estimate when angle is known
- Keep backward compatibility: no launch angle = current behavior unchanged

### 4. Unified carry estimation

Consider a single `estimate_carry()` that accepts all available inputs (ball speed, club, launch angle, spin, smash factor) and applies adjustments incrementally. This avoids the current pattern of separate `estimate_carry_distance()` and `estimate_carry_with_spin()` functions that don't compose.

## Non-goals

- No new hardware
- No camera changes
- No changes to the UI (it already displays launch angle)

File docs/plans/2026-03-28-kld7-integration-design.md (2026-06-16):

# K-LD7 Full Stack Integration — Design

**Date:** 2026-03-28
**Status:** Approved

## Goal

Integrate the RFbeam K-LD7 24 GHz FMCW radar into the openflight stack for real-time angle measurement. The K-LD7 handles angle (vertical or horizontal, depending on mount orientation) and distance. The OPS243-A handles speed and spin. Long-term, K-LD7 replaces the camera for angle measurement.

## Architecture

### K-LD7 Module (`src/openflight/kld7/`)

**`kld7_tracker.py`** — Main integration class, mirrors CameraTracker pattern:

```python
KLD7Tracker(
    port=None,              # Auto-detect FTDI serial
    range_m=5,              # Detection range
    speed_kmh=100,          # Hardware max; gives fastest frame rate (~34 fps)
    orientation="vertical", # "vertical" or "horizontal" — which angle plane this module measures
)
```

- Background thread streams TDAT+PDAT continuously (no FFT — maximizes frame rate to ~34 fps)
- Ring buffer (`collections.deque`) holds last ~2 seconds of frames (~70 frames)
- `get_angle_for_shot() -> KLD7Angle | None`:
  - Searches ring buffer for highest-magnitude detection event
  - Prefers PDAT over TDAT (more reliable for transient targets — validated in testing)
  - Returns angle, distance, magnitude, confidence, frame count
  - Confidence based on: magnitude strength, number of detection frames, angle consistency
- `reset()` — clears ring buffer after shot processed
- Supports two instances on different ports for dual-module (vertical + horizontal)

**`types.py`** — Data types:

```python
@dataclass
class KLD7Angle:
    vertical_deg: float | None    # Populated when orientation="vertical"
    horizontal_deg: float | None  # Populated when orientation="horizontal"
    distance_m: float
    magnitude: float
    confidence: float             # 0.0 - 1.0
    num_frames: int               # Frames with detection in the event

@dataclass
class KLD7Frame:
    timestamp: float
    tdat: dict | None             # Single tracked target
    pdat: list[dict]              # All raw detections
```

### Server Integration

**CLI flags** (server.py + start-kiosk.sh):

| Flag | Default | Description |
|---|---|---|
| `--kld7` | off | Enable K-LD7 module |
| `--kld7-port` | auto-detect | Serial port |
| `--kld7-orientation` | `vertical` | `vertical` or `horizontal` |

Future (second module): `--kld7-port-2`, `--kld7-orientation-2`

**Startup:**
1. If `--kld7` present, create `KLD7Tracker`, connect, start background thread
2. Non-fatal on failure — warn and continue without angle radar (like camera)

**Shot attachment** (in `on_shot_detected()`):
1. OPS243 creates shot with speed + spin
2. K-LD7 step: `kld7_tracker.get_angle_for_shot()` → `KLD7Angle`
3. Attach to shot: `shot.launch_angle_vertical` or `shot.launch_angle_horizontal` per orientation
4. Reset ring buffer

**Angle priority chain (vertical):**
1. K-LD7 radar (highest — direct measurement)
2. Camera (medium — visual tracking)
3. Estimation from club/speed (lowest)

**Angle priority chain (horizontal):**
1. K-LD7 radar (when horizontal module connected)
2. Camera (existing)
3. None (no estimation)

K-LD7 data overrides camera data when both are present.

### Carry Distance

**Vertical angle:** No formula changes. `adjust_carry_for_launch_angle()` already penalizes deviation from optimal launch angle per club type. K-LD7 provides better input data with higher confidence.

**Horizontal angle** (when available): `carry_along_target = carry * cos(horizontal_angle_rad)`. Applied after all other adjustments (spin, smash factor). A 10° offline shot loses ~1.5% carry.

### UI Changes

**Current:** Ball speed gauge + 4 metric cards (carry, club speed, launch angle, spin)

**Changes:**
- Rename "Launch Angle" → **"Vertical"** — vertical launch angle in degrees
- Add **"Horizontal"** card — horizontal angle in degrees (positive = right of target)
- Subtext shows source: "radar" or "estimated"
- Horizontal card hidden when no horizontal data available
- Same confidence indicator pattern (high/medium/low)

## Data Flow

```
K-LD7 (USB serial)              OPS243-A (USB serial)
    │                                │
    ▼                                ▼
KLD7Tracker                    RollingBufferMonitor
(background thread)            (capture thread)
    │                                │
    │ ring buffer                    │ trigger → process → Shot
    │ (~2s of TDAT/PDAT)             │ (speed + spin)
    │                                │
    └──────────┐    ┌────────────────┘
               ▼    ▼
         on_shot_detected()
               │
               ├── kld7_tracker.get_angle_for_shot()
               ├── camera_tracker.calculate_launch_angle() [fallback]
               ├── estimate_launch_angle() [last resort]
               ├── adjust carry for angles
               ├── session_logger.log_shot(...)
               └── socketio.emit("shot", ...)
                        │
                        ▼
                    React UI
                (vertical + horizontal cards)
```

## Hardware

**Single module (tomorrow's test):**
- K-LD7 on EVAL board, mounted vertically (90° rotation)
- Provides vertical launch angle
- `/dev/ttyUSB*` via FTDI

**Dual module (future):**
- Module 1: mounted vertically → vertical angle
- Module 2: bare K-LD7 + FTDI cable (~$95) → horizontal angle
- Two `/dev/ttyUSB*` ports, two `KLD7Tracker` instances

## Known Limitations

1. **Speed aliasing:** K-LD7 max 100 km/h; golf ball speeds alias. Speed data ignored — OPS handles speed.
2. **~34 fps without FFT:** 1-2 frames per ball pass at golf speed. May limit angle accuracy.
3. **Golf ball RCS:** Detection at 5m validated indoors with tossed balls. Full-speed struck balls unverified.
4. **Single-plane per module:** Each K-LD7 measures one angle plane only.

## Module Responsibilities (Clean Separation)

| Measurement | Module | Notes |
|---|---|---|
| Ball speed | OPS243-A | Primary measurement |
| Club speed | OPS243-A | From pre-impact readings |
| Spin rate | OPS243-A | Rolling buffer I/Q analysis |
| Vertical angle | K-LD7 (vertical mount) | Replaces camera when available |
| Horizontal angle | K-LD7 (horizontal mount) | Future second module |
| Distance | K-LD7 | Bonus data, not used in carry calc yet |

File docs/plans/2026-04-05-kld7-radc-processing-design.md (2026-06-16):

# K-LD7 Raw ADC Processing — Design Spec

**Date:** 2026-04-05
**Status:** Draft

## Goal

Replace dependence on the K-LD7's internal detector (PDAT) with custom FFT + CFAR processing on raw ADC samples (RADC). This gives us control over detection threshold, FFT resolution, and angle estimation — the same signal-processing chain that commercial launch monitors use.

## Background

The K-LD7 currently outputs processed detections (PDAT) at ~34 fps. A golf ball appears in only 1-2 PDAT frames because the module's internal detector is conservative. With raw I/Q we can run longer FFTs, lower thresholds, and potentially recover ball returns the module discards.

### RADC Frame Structure

3072 bytes per frame at ~34 fps:

| Segment | Content | Size |
|---|---|---|
| F1 Freq A | 256 I samples (uint16) + 256 Q samples (uint16) | 1024 bytes |
| F2 Freq A | 256 I samples (uint16) + 256 Q samples (uint16) | 1024 bytes |
| F1 Freq B | 256 I samples (uint16) + 256 Q samples (uint16) | 1024 bytes |

Two frequencies (F1, F2) enable phase-difference angle estimation between Rx channels.

### Bandwidth Requirement

RADC at 34 fps = ~102 KB/s. Current baud rate of 115200 (~11.5 KB/s) is insufficient. Must use 3 Mbaud for reliable RADC streaming.

## Deliverables

### 1. Capture Script — `scripts/capture_kld7_radc.py`

**Purpose:** Stream and record raw ADC data from a single K-LD7 for offline analysis.

**Behavior:**
- Connect to K-LD7 at specified port and baud rate (default 3 Mbaud)
- Stream `RADC | PDAT | TDAT` simultaneously
- RADC for custom processing, PDAT/TDAT for comparison against module's detector
- Record continuously for a specified duration
- Save to `.pkl` with metadata

**CLI:**
```bash
./scripts/capture_kld7_radc.py --port /dev/ttyUSB0 --orientation vertical --duration 60
./scripts/capture_kld7_radc.py --port /dev/ttyUSB0 --baud 3000000 --duration 30
```

**Output `.pkl` structure:**
```python
{
    "metadata": {
        "module": "K-LD7",
        "port": "/dev/ttyUSB0",
        "baud_rate": 3000000,
        "orientation": "vertical",
        "capture_start": "2026-04-05T...",
        "capture_end": "2026-04-05T...",
        "total_frames": N,
        "params": { ... },  # K-LD7 config params
    },
    "frames": [
        {
            "timestamp": float,
            "radc": {
                "f1a_i": np.ndarray,  # (256,) uint16
                "f1a_q": np.ndarray,  # (256,) uint16
                "f2a_i": np.ndarray,  # (256,) uint16
                "f2a_q": np.ndarray,  # (256,) uint16
                "f1b_i": np.ndarray,  # (256,) uint16
                "f1b_q": np.ndarray,  # (256,) uint16
            },
            "tdat": dict | None,     # module's tracked target
            "pdat": list[dict],      # module's raw detections
        },
        ...
    ]
}
```

### 2. Analysis Library — `scripts/kld7_radc_lib.py`

**Purpose:** Standalone helpers for processing RADC captures. No dependency on the main `openflight` package.

**Dependencies:** `numpy` only. Plotting lives in the analysis script, not here.

#### FFT Processing

- `parse_radc_frame(frame) -> dict` — Extract I/Q arrays from raw RADC bytes
- `compute_range_doppler(iq_complex, fft_size=2048) -> np.ndarray` — Hann window, zero-pad, FFT, magnitude spectrum
- `cfar_detect(spectrum, guard_cells=4, training_cells=16, threshold_factor=8.0) -> list[Detection]` — OS-CFAR on the range-Doppler spectrum, returns peaks above adaptive noise floor

#### Spatial Filtering

- `estimate_angle_from_phase(f1_complex, f2_complex) -> float` — Phase-difference angle estimation between the two frequency channels
- `filter_by_distance(detections, min_m, max_m) -> list` — Distance gate
- `filter_by_velocity(detections, min_kmh, max_kmh) -> list` — Velocity gate

#### Ball Isolation

- `find_ball_candidates(frames, club_event_time) -> list` — Distance gate 2-6m, fast outbound, short burst, appearing after club event
- `compare_radc_vs_pdat(frame) -> dict` — Side-by-side comparison of what our FFT finds vs what the module's PDAT reported

#### Data Types

```python
@dataclass
class RADCDetection:
    frame_index: int
    timestamp: float
    distance_m: float
    velocity_kmh: float
    angle_deg: float        # from phase difference
    magnitude: float        # FFT bin magnitude
    snr_db: float          # signal-to-noise from CFAR
    bin_index: int          # FFT bin number
```

### 3. Analysis Script — `scripts/analyze_kld7_radc.py`

**Purpose:** Visualize and explore RADC captures.

**Dependencies:** `numpy`, `matplotlib`

**CLI:**
```bash
# Full analysis
./scripts/analyze_kld7_radc.py capture.pkl

# Zoom to detected swing windows
./scripts/analyze_kld7_radc.py capture.pkl --shot-windows

# Export detections to CSV
./scripts/analyze_kld7_radc.py capture.pkl --csv
```

**Generated outputs:**
- Range-Doppler heatmap per frame (around swing events)
- Detection timeline: our FFT detections vs PDAT detections on same time axis
- Distance vs time scatter for ball candidates
- Per-shot comparison table (CSV): our detection count, angles, magnitudes vs PDAT

## FFT Parameters

| Parameter | Value | Rationale |
|---|---|---|
| Window | Hann | Standard for spectral analysis, good sidelobe suppression |
| Input samples | 256 (from RADC) | Fixed by hardware |
| Zero-pad to | 2048 | 8× interpolation, ~0.15 m/s velocity resolution |
| CFAR guard cells | 4 | Prevent target self-masking |
| CFAR training cells | 16 | Enough for noise estimate |
| CFAR threshold | 8.0× (start) | Tunable — lower = more sensitive, more false alarms |

## What This Is Not

- **Not a live replacement for the PDAT tracker** — purely offline analysis to validate the approach
- **Not coherent integration across frames** — single-frame FFT first, multi-frame stacking is a future step if this shows promise
- **Not dual-K-LD7** — single vertical unit for now, horizontal comes later

## Success Criteria

1. Capture script reliably records RADC at 3 Mbaud without dropped frames
2. Our FFT + CFAR finds at least as many ball detections as PDAT on the same capture
3. We can see ball returns in the range-Doppler map that PDAT missed
4. Phase-based angle estimation produces reasonable values (within ±10° of PDAT angles)

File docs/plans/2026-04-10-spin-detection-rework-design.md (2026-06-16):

# Spin Detection Rework: Amplitude Envelope Demodulation

## Problem

The current spin detection extracts ~30 ball speed values from overlapping FFT windows (937 Hz effective sample rate), then runs a secondary 256-point FFT to find spin modulation frequency. With only 30 data points, the frequency resolution is 220 RPM/bin — too coarse to detect real spin. 81% of captures show spectral leakage artifacts, and the 19% that "pass" are Hann window sidelobe artifacts at exactly 1318 and 1538 rpm (FFT bins 6 and 7).

## Approach

Work directly on the raw 4096 I/Q samples (30 kHz, 136.5ms) instead of ~30 extracted speed values. The golf ball seam creates amplitude modulation at **2x spin rate** as it crosses the radar beam twice per revolution. Bandpass filter the I/Q signal around the ball's Doppler frequency, extract the amplitude envelope, then find the spin frequency using FFT (primary) with autocorrelation fallback for low-cycle signals (drivers).

This gives us ~100x more data points for spin analysis and ~2x finer frequency resolution.

## Signal Processing Pipeline

```
Raw I/Q (4096 samples, 30 kHz, from IQCapture)
    │
    ├─ Existing pipeline → ball_speed_mph (from process_capture)
    │
    ▼
1. Convert ball speed to Doppler frequency
   ball_doppler_hz = 2 * ball_speed_mps / wavelength_m

2. Bandpass filter I/Q around ball_doppler_hz
   - Complex signal: I + jQ
   - 4th order Butterworth bandpass, ±200 Hz around ball Doppler
   - Using scipy.signal.sosfiltfilt (zero-phase, no group delay)
   - Isolates ball return from club, body movement, and noise

3. Extract amplitude envelope
   envelope = abs(filtered_complex_signal)
   Full capture: ~4096 samples at 30 kHz

4. Trim to ball-present window
   - Use ball_timestamp_ms from existing speed detection to locate ball onset
   - Convert to sample index: start_sample = ball_timestamp_ms * 30
   - Take from ball onset to end of capture (typically 30-80ms = 900-2400 samples)
   - Require minimum 600 samples (~20ms) to proceed

5. Remove DC offset, apply Hann window
   - Subtract mean from envelope (removes DC component)
   - Apply Hann window to reduce spectral leakage

6. Primary detection: FFT on envelope
   - Zero-pad to 8192 for spectral interpolation
   - Frequency resolution: 30000/8192 = 3.66 Hz ≈ 110 RPM
   - Search for peak in seam frequency range: 80-670 Hz
     (corresponds to 2400-20000 RPM via 2x seam relationship)
   - Calculate SNR: peak magnitude / median of valid frequency range
   - Reject peaks in first 2 bins (DC leakage)

7. Fallback detection: Autocorrelation on envelope
   - Used when FFT SNR is marginal (< 5.0) but above noise (> 2.0)
   - Compute normalized autocorrelation of the windowed envelope
   - Search for first significant peak at lag corresponding to 80-670 Hz
   - Lag range: 30000/670 = 45 samples to 30000/80 = 375 samples
   - Peak must exceed 0.3 normalized correlation to be valid
   - If autocorrelation confirms FFT frequency (within 10%), boost confidence

8. Convert seam frequency to spin RPM
   spin_rpm = (peak_frequency_hz / 2) * 60
   Divide by 2 because seam crosses beam twice per revolution.

9. Quality assessment
   - "high": FFT SNR >= 8 AND >= 5 seam cycles in the trimmed window
   - "medium": FFT SNR >= 5, OR autocorrelation confirms FFT peak
   - "low": FFT SNR >= 3, marginal detection
   - Reject: SNR < 3, or peak in first 2 bins, or fewer than 2 seam cycles
```

## Expected Detection Performance

| Club | Typical Spin | Seam Freq | Cycles in 60ms | Expected Result |
|---|---|---|---|---|
| Wedge | 8000-10000 rpm | 267-333 Hz | 16-20 | High confidence |
| 9-iron | 7000-9000 rpm | 233-300 Hz | 14-18 | High confidence |
| 7-iron | 5000-7000 rpm | 167-233 Hz | 10-14 | High confidence |
| 5-iron | 4000-5500 rpm | 133-183 Hz | 8-11 | Medium-high |
| 3-iron | 3500-4500 rpm | 117-150 Hz | 7-9 | Medium |
| Driver | 2500-3500 rpm | 83-117 Hz | 5-7 | Medium (FFT+autocorrelation) |
| Driver (low) | 2000-2500 rpm | 67-83 Hz | 4-5 | Low-medium (autocorrelation) |

## Bandpass Filter Design

- Type: 4th order Butterworth
- Center: ball_doppler_hz (computed from OPS243 ball speed)
- Bandwidth: ±200 Hz (400 Hz total)
- Implementation: `scipy.signal.butter` + `sosfiltfilt` (sos form for numerical stability)
- The ±200 Hz window captures the ball's Doppler peak plus spin-induced spectral broadening while rejecting club returns (which are at a different Doppler frequency)

### Doppler Frequency Examples

| Ball Speed | Doppler Frequency | Filter Band |
|---|---|---|
| 80 mph | ~1930 Hz | 1730-2130 Hz |
| 120 mph | ~2900 Hz | 2700-3100 Hz |
| 160 mph | ~3860 Hz | 3660-4060 Hz |

All within the 0-15 kHz Nyquist bandwidth of 30 ksps sampling.

## Files Changed

### Modified: `src/openflight/rolling_buffer/processor.py`

**`detect_spin()`** — Replace internals entirely. New signature:
```python
def detect_spin(self, capture: IQCapture, ball_speed_mph: float, 
                ball_timestamp_ms: float) -> SpinResult:
```
Instead of the current:
```python
def detect_spin(self, ball_speeds: List[float], sample_rate_hz: float) -> SpinResult:
```

**`process_capture()`** — Update to pass `IQCapture` and `ball_speed_mph` to `detect_spin` instead of extracted ball speed values.

**Keep `extract_ball_speeds()`** — still used for the speed timeline, just no longer feeds spin detection.

### Unchanged
- `SpinResult` dataclass in `types.py` — same fields: `spin_rpm`, `confidence`, `snr`, `quality`
- `server.py` — consumes `SpinResult` from `ProcessedCapture`, no changes
- Session logger, UI, Alloy pipeline — all consume spin_rpm/quality unchanged
- Trigger, monitor, K-LD7 code — unrelated

## Constants

```python
# Spin detection via amplitude envelope demodulation
SPIN_BANDPASS_BW_HZ = 200       # ±200 Hz around ball Doppler
SPIN_BANDPASS_ORDER = 4          # Butterworth filter order
SPIN_FFT_SIZE = 8192             # Zero-padded FFT for envelope
SPIN_MIN_SEAM_HZ = 80           # 2400 RPM minimum (seam = 2x spin)
SPIN_MAX_SEAM_HZ = 670          # 20000 RPM maximum
SPIN_MIN_SAMPLES = 600          # ~20ms minimum ball signal
SPIN_SNR_HIGH = 8.0             # High confidence threshold
SPIN_SNR_MEDIUM = 5.0           # Medium confidence threshold
SPIN_SNR_MIN = 3.0              # Minimum to report
SPIN_AUTOCORR_THRESHOLD = 0.3   # Minimum normalized correlation
SPIN_MIN_CYCLES = 2             # Minimum seam cycles to report
```

## Testing Strategy

1. **Synthetic signal test**: Generate I/Q with known Doppler frequency and amplitude modulation at known spin rate. Verify `detect_spin` recovers the correct RPM.
2. **Multiple spin rates**: Test at 3000, 5000, 7000, 10000 RPM to cover the full range.
3. **No-spin test**: Flat amplitude envelope (no modulation) should return no spin.
4. **Noise robustness**: Add white noise to synthetic signal, verify detection degrades gracefully.
5. **Real capture validation**: Run against the driving range session data (session_20260410) to check that the new method doesn't produce the 1318/1538 artifacts.

## Validation Against Real Data

After implementation, re-analyze `session_logs/session_20260410_110759_range.jsonl` (68 shots from driving range). Success criteria:
- No more 1318/1538 rpm quantized values
- Iron/wedge spin detection rate > 50% (currently 19% but with fake values)
- Detected spin values in expected ranges per club (driver 2500-3500, iron 4000-8000, wedge 8000-12000)
- "No spin detected" is preferred over reporting incorrect values

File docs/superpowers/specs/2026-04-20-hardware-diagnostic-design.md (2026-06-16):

# Hardware Diagnostic Script

**Date:** 2026-04-20
**Status:** Approved
**Scope:** A unified guided diagnostic script that verifies every hardware component of the OpenFlight launch monitor — OPS243-A radar, both K-LD7 angle radars, the sound trigger, and the rolling buffer hardware trigger path.

## Problem

The repo has 5+ separate hardware test scripts (`test_kld7.py`, `test_radar_raw.py`, `test_sound_trigger_hardware.py`, `test_rolling_buffer_persist.py`, `debug_hardware_trigger.py`). Each tests one thing. There's no single "is the device fully working?" check — a user setting up a new build or debugging a failure has to run each script, interpret its output independently, and remember which flags each accepts. A unified diagnostic reduces setup friction and provides a clear pass/fail signal for support.

## Approach

Single Python script at `scripts/hardware-test/diagnose.py` that runs 6 checks in sequence. Each check is a function returning a `CheckResult`. Shared state (open serial handles, detected ports) is passed between checks via a `DiagnosticState` dataclass. Reuses existing `OPS243Radar`, `KLD7Tracker`, and `RollingBufferProcessor` — no new dependencies.

Guided walkthrough model: the diagnostic prompts the user at moments that require physical interaction (sound trigger). Connectivity checks run automatically. Missing optional hardware skips cleanly with a clear reason.

## Architecture

**File:** `scripts/hardware-test/diagnose.py` (one file)

**Entry point:** `uv run python scripts/hardware-test/diagnose.py`

**Flags:**
- `--require-all` — skipped checks (e.g., only one K-LD7 detected) fail instead of pass
- `--no-interactive` — skip checks that require user action (Check 6)
- `--timeout-multiplier N` (default 1.0) — scale all per-check timeouts for slow environments

**Data structures:**

```python
@dataclass
class CheckResult:
    name: str
    status: Literal["pass", "fail", "skip"]
    detail: str = ""        # one-line primary message
    hint: str = ""          # remediation suggestion on fail
    elapsed_s: float = 0.0

@dataclass
class DiagnosticState:
    """Shared state between checks so later ones can skip cleanly."""
    ops243_port: Optional[str] = None
    ops243_radar: Optional[OPS243Radar] = None  # held open across checks
    kld7_vertical_port: Optional[str] = None
    kld7_horizontal_port: Optional[str] = None
```

**Top-level flow:**

```python
CHECKS = [
    check_ops243_connectivity,
    check_ops243_rolling_buffer_persisted,
    check_ops243_software_trigger,
    check_kld7_vertical,
    check_kld7_horizontal,
    check_sound_trigger_end_to_end,
]

def main():
    state = DiagnosticState()
    results = []
    try:
        for check in CHECKS:
            print_check_start(check.__name__)
            result = run_with_timeout(check, state)
            results.append(result)
            print_check_result(result)
    finally:
        if state.ops243_radar:
            state.ops243_radar.disconnect()
    print_summary(results)
    sys.exit(0 if all_pass(results) else 1)
```

## The 6 Checks

### Check 1 — OPS243 connectivity (~2s)
- Auto-detect by scanning `/dev/ttyACM*` and `/dev/ttyUSB*`, try `OPS243Radar.connect()` at 57600 baud.
- Query `get_info()` and `get_firmware_version()`; PASS if either returns a usable response.
- Detail on pass: `"{port} • firmware {version}"`
- Hint on fail: `"Check USB connection and permissions (dialout group)"`
- Stores `state.ops243_port` and `state.ops243_radar` (kept open for Checks 2–3 and 6).

### Check 2 — OPS243 rolling buffer persisted (~1s)
- Queries current boot mode via `get_info()`. Verifies the radar is already in rolling buffer mode (G1/GC) without us configuring it — this proves the `A!` persistence from the setup script is active.
- Detail on pass: `"Radar boots in rolling buffer mode (G1)"`
- Hint on fail: `"Run 'uv run python scripts/hardware-test/test_rolling_buffer_persist.py --setup' then power cycle the radar"`
- Skipped (cascade) if Check 1 failed.

### Check 3 — OPS243 software trigger (~3s)
- Calls `radar.trigger_capture(timeout=5)`. Parses response through `RollingBufferProcessor.parse_capture()`. Verifies 4096 I/Q samples.
- Detail on pass: `"Capture received: 4096 I/Q samples"`
- On fail, detail distinguishes "no response" vs "malformed response":
  - No response: `"Software trigger sent but no I/Q response received"`
  - Malformed: `"Response received but parse failed: {parse_error}"`
- Skipped if Check 2 failed.

### Check 4 — K-LD7 vertical connectivity (~3s)
- Scans serial ports for FTDI/CP210x devices matching K-LD7 descriptors (reusing logic from `test_kld7.py`). If two match, uses the first one; the second is reserved for Check 5.
- Instantiates `KLD7Tracker(orientation="vertical")`, connects, streams for 1 second, verifies at least 5 frames received.
- Detail on pass: `"{port} • {frame_count} frames in 1.0s (~{fps} fps)"`
- Hint on fail: distinguishes "no K-LD7 detected on any serial port" vs "detected but no frames streaming".
- Disconnects after check so Check 5 can claim the other unit.

### Check 5 — K-LD7 horizontal connectivity (~3s)
- Same logic as Check 4, using the second detected K-LD7. Uses `orientation="horizontal"`.
- If only one K-LD7 was detected, SKIP with detail `"Only one K-LD7 detected — horizontal is optional"`.
- `--require-all` converts this skip to a fail.

### Check 6 — Sound trigger end-to-end (~20s, interactive)
- Calls `radar.rearm_rolling_buffer()` first (since Check 3's software trigger consumed the previous buffer).
- Prompts: `"Clap loudly or tap the SEN-14262 sensor. Waiting up to 15 seconds..."`
- Calls `radar.wait_for_hardware_trigger(timeout=15)`. On trigger, parses the capture, verifies 4096 samples.
- Detail on pass: `"Hardware trigger fired, capture valid (4096 samples)"`
- Hint on timeout: `"Check SEN-14262 wiring to OPS243 HOST_INT pin. Adjust R17 resistor if sensor too quiet."`
- On malformed response: distinguishes "trigger fired but capture bad" from no trigger.
- Skipped if Check 3 failed. Skipped with `--no-interactive`.

**Ordering rationale:** Later checks depend on earlier ones — connectivity → persistence → trigger. Failing a prerequisite cascade-skips dependent checks, producing a clear "OPS243 broken → these 4 checks skipped because of it" rather than a cascade of red.

## Output Format

Color-coded live checklist. Colors auto-disable when `stdout` isn't a TTY.

```
OpenFlight Hardware Diagnostic
========================================

[1/6] OPS243 connectivity ............... ✓ PASS (1.2s)
        /dev/ttyACM0 • firmware v1.2.3

[2/6] OPS243 rolling buffer persisted ... ✓ PASS (0.8s)
        Radar boots in rolling buffer mode (G1)

[3/6] OPS243 software trigger ........... ✓ PASS (2.1s)
        Capture received: 4096 I/Q samples

[4/6] K-LD7 vertical .................... ✓ PASS (2.5s)
        /dev/ttyUSB0 • 42 frames in 1.0s (~42 fps)

[5/6] K-LD7 horizontal .................. ⊘ SKIP
        Only one K-LD7 detected — horizontal is optional
        Pass --require-all to fail on skipped optional components

[6/6] Sound trigger + rolling buffer ....
        ► Clap loudly or tap the SEN-14262 sensor now.
          Waiting up to 15 seconds...
        ✓ Trigger received after 3.2s
[6/6] Sound trigger + rolling buffer .... ✓ PASS (3.4s)
        Hardware trigger fired, capture valid (4096 samples)

========================================
Summary: 5 passed, 0 failed, 1 skipped (10.0s total)
Overall: ✓ HEALTHY
```

**Color scheme:** ✓ PASS green, ✗ FAIL red, ⊘ SKIP yellow, ⧗ (running) dim, hints dim gray, headings bold.

**Failure example:**

```
[3/6] OPS243 software trigger ........... ✗ FAIL (5.1s)
        Software trigger sent but no I/Q response received
        → Radar may be stuck in a non-rolling-buffer mode despite Check 2
        → Try power-cycling the radar and re-running
```

## Exit Codes

- `0` — all checks passed (skips allowed unless `--require-all`)
- `1` — one or more checks failed
- `2` — script usage error (bad flags)
- `130` — interrupted by user (Ctrl+C)

## Error Handling

- Each check runs inside `try/except Exception as e` — any uncaught exception becomes `status=fail` with `detail=f"Unexpected error: {type(e).__name__}: {e}"`. The diagnostic never crashes; it reports.
- `SerialException` with `[Errno 13] Permission denied` maps to hint: `"Add your user to the dialout group: sudo usermod -aG dialout $USER"`.
- `KeyboardInterrupt` handled at top level for clean Ctrl+C exit (130).
- `finally` in `main()` ensures any open serial handles in `state` are closed on any exit path.

## Timeouts

- Checks 1, 2, 4, 5: 10s soft timeout per check
- Check 3: 8s
- Check 6: 15s wait + 5s processing = 20s
- `--timeout-multiplier N` scales all values
- Implementation: `signal.alarm()` wrapper (POSIX only — fine for Linux Pi, the target environment)

## Testing

**In scope (unit tests in `tests/test_diagnose.py`):**
- `CheckResult` formatting helpers (color, status symbols)
- Summary function with synthetic result sets (all pass, some fail, all skip)
- Each check function's decision logic, with `OPS243Radar` / `KLD7Tracker` mocked — verifies the correct `CheckResult` is produced for each observable radar/tracker response pattern

**Out of scope:**
- Live hardware interaction (that's what the script itself is for)
- Mocking the serial-level protocol — too brittle, no real verification value

## Out of Scope / YAGNI

- JSON output (can add later if a health dashboard needs it)
- Metrics export to Prometheus/Alloy (observability is already wired up elsewhere)
- CI integration beyond running the unit tests
- Web-based version of the diagnostic
- Fixing hardware problems detected (diagnostic is read-only; setup scripts already exist for fixes)

## Files Created / Modified

| File | Change |
|---|---|
| `scripts/hardware-test/diagnose.py` | New |
| `tests/test_diagnose.py` | New |
| `README.md` | Add "Diagnostic" section pointing to the new script |

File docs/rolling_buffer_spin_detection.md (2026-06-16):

# Rolling Buffer & Spin Detection Implementation Plan

Based on guidance from OmniPreSense (January 2026).

## Overview

The OPS243-A radar can detect golf ball spin by analyzing micro-variations in the Doppler signal caused by the spinning dimpled surface. This requires:

1. **Rolling Buffer Mode (G1)** - Captures complete I/Q data for post-processing
2. **Overlapping FFT Windows** - Increases temporal resolution to see spin "waviness"
3. **Secondary FFT** - Extracts spin frequency from speed oscillations

## Current vs Rolling Buffer Approach

| Aspect | Current (Streaming) | Rolling Buffer |
|---|---|---|
| Mode | Continuous reporting | Triggered capture |
| Data | Processed speeds | Raw I/Q samples |
| Resolution | ~56 Hz | Up to 1 kHz |
| Spin detection | No | Yes (50-60% success) |
| Latency | Real-time | Post-processing |

## Rolling Buffer Mode Commands

```
PI    # Deactivate (idle mode)
K+    # Enable peak detection
G1    # Enable rolling buffer mode (4096 samples)
S!    # Trigger capture and dump buffer
```

## Data Format from S! Command

The sensor returns JSON with:
```json
{"sample_time": "964.003"}
{"trigger_time": "964.105"}
{"I": [4096 integer samples...]}
{"Q": [4096 integer samples...]}
```

- 4096 samples = 32 blocks × 128 samples each
- At 30ksps: ~136ms of data captured
- Trigger time indicates when the trigger event occurred within the buffer

## Triggering Strategy for Golf

The radar needs a trigger to know when to dump the buffer. The recommended approach is a direct hardware trigger via HOST_INT.

> **Important: Persistent Mode Required.** The OPS243-A has a firmware bug where the HOST_INT pin mode switches when transitioning from normal mode (GS) to rolling buffer mode (GC) at runtime. The fix from OmniPreSense: save rolling buffer mode to persistent memory (`A!` command) and power cycle the board. After that, hardware triggers work correctly. See the [Radar Setup section](raspberry-pi-setup.md#radar-setup-one-time) in the Pi setup guide, or run:
> ```
> uv run python scripts/hardware-test/test_rolling_buffer_persist.py --setup
> # Power cycle the radar
> uv run python scripts/hardware-test/test_rolling_buffer_persist.py --test
> ```

### 1. Direct Hardware Sound Trigger (Recommended)

Uses the SparkFun SEN-14262 sound detector wired directly to HOST_INT via a level shifter. The sound of club impact triggers the radar to dump its buffer. Near-zero latency (~10us).

**Hardware Required:**
- SparkFun SEN-14262 Sound Detector (~$12)
- BSS138 level shifter module (~$4)

**Wiring:**
See [sound-trigger-wiring.md](sound-trigger-wiring.md) for full circuit details.

**Usage:**
```bash
# Default mode in start-kiosk.sh
./scripts/start-kiosk.sh

# Or explicitly
openflight-server --mode rolling-buffer --trigger sound
```

### 2. Speed Threshold Trigger

- Configure minimum speed threshold (e.g., 50+ mph)
- When club head is detected above threshold, trigger fires
- Buffer contains pre-trigger (backswing) and post-trigger (impact + ball flight)
- ~5-6ms response time per OmniPreSense

**Usage:**
```bash
openflight-server --mode rolling-buffer --trigger speed
```

### 3. GPIO Software Trigger (Fallback)

Uses Pi GPIO to detect sound, then sends S! command via serial. Higher latency (~1-18ms) but simpler setup.

**Usage:**
```bash
openflight-server --mode rolling-buffer --trigger sound-gpio
```

### 4. Software Polling

- Continuously poll with S! and look for activity
- Less efficient but simplest to implement
- ~300ms latency

**Usage:**
```bash
openflight-server --mode rolling-buffer --trigger polling
```

## Trigger Latency Comparison

| Trigger Type | Latency | Hardware Required |
|---|---|---|
| `sound` | ~10μs | SEN-14262 + level shifter (recommended) |
| `speed` | ~5-6ms | None (uses radar detection) |
| `sound-gpio` | ~1-18ms | SEN-14262 + GPIO wiring |
| `polling` | ~300ms | None |

## Signal Processing Pipeline

### Step 1: Capture I/Q Data
```python
# Send trigger command
response = send_command('S!')

# Parse response
sample_time = data["sample_time"]
trigger_time = data["trigger_time"]
i_data = data["I"]  # 4096 samples
q_data = data["Q"]  # 4096 samples
```

### Step 2: Standard FFT Processing (Speed Detection)
```python
WINDOW_SIZE = 128
FFT_SIZE = 4096
NUM_BLOCKS = 32

for block_idx in range(NUM_BLOCKS):
    start = block_idx * WINDOW_SIZE
    end = start + WINDOW_SIZE

    i_block = i_data[start:end]
    q_block = q_data[start:end]

    # Remove DC, scale, apply Hanning window
    i_block = (i_block - np.mean(i_block)) * 3.3 / 4096
    q_block = (q_block - np.mean(q_block)) * 3.3 / 4096
    i_block *= np.hanning(WINDOW_SIZE)
    q_block *= np.hanning(WINDOW_SIZE)

    # FFT for speed
    complex_signal = i_block + 1j * q_block
    fft_result = np.fft.fft(complex_signal, FFT_SIZE)
    magnitude = np.abs(fft_result)

    # Find peaks, convert bins to speed
    # Speed = bin_index * 0.0063 * (SAMPLE_RATE / FFT_SIZE)
```

### Step 3: Overlapping FFT for Spin (The Key Trick)

Instead of stepping by 128 samples, step by 32 samples for 4x temporal resolution:

```python
STEP_SIZE = 32  # Instead of 128
speeds_over_time = []

for start in range(0, len(i_data) - WINDOW_SIZE, STEP_SIZE):
    end = start + WINDOW_SIZE

    # Process block (same as above)
    speed = process_block(i_data[start:end], q_data[start:end])
    speeds_over_time.append(speed)

# Result: ~1kHz speed readings instead of ~250Hz
# At 30ksps with 32-sample steps: 30000/32 = 937.5 Hz
```

### Step 4: Spin Extraction from Speed Oscillations

The ball's dimpled surface causes periodic speed variations as it spins:

```python
# Filter to just ball speed readings (after impact)
ball_speeds = extract_ball_speeds(speeds_over_time)

# Remove trend (average speed)
detrended = ball_speeds - np.mean(ball_speeds)

# FFT to find oscillation frequency
spin_fft = np.fft.fft(detrended)
frequencies = np.fft.fftfreq(len(detrended), d=1/937.5)  # 937.5 Hz sample rate

# Find dominant frequency = spin rate
peak_idx = np.argmax(np.abs(spin_fft[1:len(spin_fft)//2])) + 1
spin_hz = abs(frequencies[peak_idx])
spin_rpm = spin_hz * 60

print(f"Detected spin: {spin_rpm:.0f} RPM")
```

## Expected Spin Signal

For a golf ball at ~3000 RPM (50 Hz):
- At 1kHz sampling: ~20 samples per revolution
- Should see clear sinusoidal pattern in detrended speed

```
Speed (detrended)
    +0.5 |    *           *           *
         |   * *         * *         * *
       0 |--*---*-------*---*-------*---*---
         | *     *     *     *     *     *
    -0.5 |*       *   *       *   *
         +--------------------------------→ Time
              20ms     40ms     60ms
              ↑________↑
              One revolution at 3000 RPM
```

## Quality Assessment

OmniPreSense reports 50-60% success rate. Implement quality checks:

```python
def assess_spin_quality(spin_fft, spin_rpm):
    """Determine if spin calculation is reliable."""

    # Check 1: Clear dominant peak
    peak_magnitude = np.max(np.abs(spin_fft))
    noise_floor = np.median(np.abs(spin_fft))
    snr = peak_magnitude / noise_floor

    if snr < 3.0:
        return False, "Weak spin signal"

    # Check 2: Reasonable RPM range for golf
    if spin_rpm < 1000 or spin_rpm > 10000:
        return False, f"Spin {spin_rpm} outside expected range"

    # Check 3: Consistent over multiple windows
    # (implementation depends on data structure)

    return True, "Good quality"
```

## Implementation Phases

### Phase 2A: Basic Rolling Buffer Capture
- Add G1 mode initialization
- Implement S! trigger and I/Q parsing
- Process blocks for speed (standard method)
- Compare accuracy to streaming mode

### Phase 2B: Trigger Optimization
- Implement speed threshold trigger
- Tune pre/post trigger timing
- Handle trigger timeout (no swing detected)

### Phase 3A: Overlapping FFT
- Implement 32-sample stepping
- Store high-resolution speed timeline
- Identify ball vs club in timeline

### Phase 3B: Spin Extraction
- Implement secondary FFT on ball speeds
- Add quality assessment
- Report spin only when confident

## Code Structure Suggestion

```python
class RollingBufferProcessor:
    """Handles rolling buffer capture and spin detection."""

    def __init__(self, radar: OPS243Radar):
        self.radar = radar
        self.window_size = 128
        self.fft_size = 4096
        self.step_size = 32  # For spin detection

    def enable_rolling_buffer(self):
        """Switch radar to G1 mode."""
        self.radar._send_command("PI")  # Idle
        self.radar._send_command("K+")  # Peak detection
        self.radar._send_command("G1")  # Rolling buffer

    def trigger_capture(self) -> Optional[CaptureResult]:
        """Trigger and retrieve buffer data."""
        response = self.radar._send_command("S!")
        return self._parse_capture(response)

    def process_for_speed(self, capture: CaptureResult) -> List[SpeedReading]:
        """Standard 128-sample block processing."""
        pass

    def process_for_spin(self, capture: CaptureResult) -> Optional[SpinResult]:
        """Overlapping FFT for spin detection."""
        pass

    def disable_rolling_buffer(self):
        """Return to normal streaming mode."""
        self.radar._send_command("PI")
        self.radar.configure_for_golf()
```

## References

- OmniPreSense Rolling Buffer Code: https://github.com/omnipresense/rolling_buffer
- OmniPreSense AN-027: Rolling Buffer Application Note
- OmniPreSense Sports Ball Detection Presentation

## Notes from OmniPreSense

> "Spin is much more difficult to detect accurately and repeatably... What we have seen is if you have very fine resolution in the speed reports, you can see a slight waviness in the ball speed signal. If you take the FFT of that data, you can get a good spin value."

> "The issue we've seen is maybe only 50-60% of the time does the data captured provide a nice-looking signal set and a solid calculation. Other times the signal looks 'sloppy' and the resulting FFT calculation is not that good."

> "Note that the spin calculated is the combined back spin and side spin but since majority of hits are predominately backspin you can call it that."

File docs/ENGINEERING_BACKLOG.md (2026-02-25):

# Engineering Backlog

Last updated: February 25, 2026 (added sensor fusion roadmap)
Source: Deep-dive code review of the `openflight` fork

## Overall Assessment

The core radar and signal-processing direction is strong, but the repository has elevated deployment risk from unauthenticated network control paths and moderate maintainability risk from a monolithic server module.

## Prioritized Backlog

### P0 - Lock down network control surface (security)

Status: Open

Issue:
- The web server currently binds with permissive CORS and exposes hardware-control Socket.IO events without authentication.

Evidence:
- `src/openflight/server.py:48`
- `src/openflight/server.py:544`
- `src/openflight/server.py:545`

Why this matters:
- Any host on the same network can potentially send commands that modify radar behavior.

Acceptance criteria:
- Socket events that change hardware/config state require authentication and authorization.
- `cors_allowed_origins` is restricted to trusted origins.
- Security behavior is covered by automated tests.

### P0 - Protect camera streaming and camera controls (security/privacy)

Status: Open

Issue:
- Camera stream and camera toggle pathways are network-accessible without auth gating.

Evidence:
- `src/openflight/server.py:255`
- `src/openflight/server.py:268`
- `src/openflight/server.py:289`
- `src/openflight/server.py:290`

Why this matters:
- Remote clients can enable/disable streaming and access live camera frames.

Acceptance criteria:
- Camera stream endpoint requires authenticated access.
- Camera toggle events are permission-gated.
- Unauthorized access attempts are rejected and logged.

### P1 - Ensure rolling-buffer trigger resets on failed captures (correctness)

Status: Open

Issue:
- The capture loop can `continue` without trigger reset when capture processing fails, which can leave trigger state stale.

Evidence:
- `src/openflight/rolling_buffer/monitor.py:387`
- `src/openflight/rolling_buffer/monitor.py:390`
- `src/openflight/rolling_buffer/monitor.py:420`
- `src/openflight/rolling_buffer/monitor.py:562`

Why this matters:
- A failure path can degrade or stall shot detection until manual recovery.

Acceptance criteria:
- Trigger reset executes on all exit paths in the capture cycle (including errors/early continues).
- Add regression test that simulates `process_capture(...)` returning `None`.

### P1 - Expand integration tests around server + hardware orchestration

Status: Open

Issue:
- Current tests are strong on pure logic but light on end-to-end server behavior and hardware-facing orchestration.

Evidence:
- `tests/test_server.py:1`
- `src/openflight/server.py:239`
- `src/openflight/server.py:321`
- `src/openflight/ops243.py:762`
- `src/openflight/ops243.py:1269`

Why this matters:
- Regressions in high-risk runtime paths may pass CI undetected.

Acceptance criteria:
- Add integration tests for Socket.IO handlers and critical HTTP routes.
- Add tests for OPS243 streaming and non-blocking read orchestration with mocks/fakes.
- CI gates include these tests.

### P2 - Decompose `server.py` and reduce global mutable state (maintainability)

Status: Open

Issue:
- `server.py` currently mixes web routing, lifecycle, camera management, monitor startup, and session concerns with module-level mutable state.

Evidence:
- `src/openflight/server.py:51`
- `src/openflight/server.py:58`
- `src/openflight/server.py:691`
- `src/openflight/server.py:900`

Why this matters:
- Increases regression risk and makes focused unit testing/refactoring harder.

Acceptance criteria:
- Split responsibilities into smaller modules (for example: server app, monitor lifecycle, camera manager, session orchestration).
- Replace module-level globals with explicit application context/state objects where feasible.
- Preserve existing external behavior and CLI options.

### P2 - Decouple shot processing from side-effect logging/output (maintainability/testability)

Status: Open

Issue:
- `LaunchMonitor` shot processing includes substantial direct `print(...)` side effects inside core flow.

Evidence:
- `src/openflight/launch_monitor.py:444`
- `src/openflight/launch_monitor.py:550`
- `src/openflight/launch_monitor.py:631`

Why this matters:
- Harder to reuse/test core logic without inheriting presentation/logging noise.

Acceptance criteria:
- Move verbose output to structured logger with configurable levels.
- Keep core shot computation path deterministic and side-effect-light.
- Add tests that assert behavior independent of logging output.

### P3 - Sync architecture docs with runtime reality

Status: Open

Issue:
- README architecture narrative presents a cleaner callback-only model than current runtime responsibilities.

Evidence:
- `README.md:214`
- `README.md:235`
- `src/openflight/server.py:691`

Why this matters:
- New contributors can be misled about actual boundaries and coupling.

Acceptance criteria:
- Update README architecture section to reflect current modules and responsibilities.
- Keep diagrams and text aligned with implemented server flow.

### P2 - Integrate OpenGolfCoach for physics-based shot analysis

Status: Open
Fork: https://github.com/jswans33/open-golf-coach (forked from OpenLaunchLabs/open-golf-coach)
License: Apache 2.0

Issue:
- OpenFlight currently uses a simple ball-speed-only carry distance estimate. No spin decomposition, shot classification, or physics trajectory modeling.

What OpenGolfCoach provides:
- Physics-based trajectory: carry distance, total distance, offline deviation, hang time, peak height, descent angle, landing position/velocity — from ball speed, launch angle, and spin data.
- Spin analysis: converts between total spin/axis and backspin/sidespin components.
- Shot classification: deterministic shot names (Straight, Draw, Fade, Hook, Slice, Duck Hook, Shank, etc.), quality ranks (S+ through E), and hex colors for UI rendering.
- Club analytics: estimated club speed, smash factor, club path, face-to-path angle.
- Python bindings via PyO3 (published as `opengolfcoach` on PyPI, also buildable from our fork with `maturin`).

Integration plan:
1. Add `opengolfcoach` to `pyproject.toml` dependencies (use PyPI package, fall back to fork build if needed on Pi/ARM).
2. In `launch_monitor.py` where `Shot` objects are created, call `opengolfcoach.calculate_derived_values()` with available shot data (ball_speed, club_speed, launch_angle if camera provides it, spin_rpm if rolling buffer provides it).
3. Extend `Shot` dataclass with new fields: carry_distance_physics, total_distance, offline_distance, shot_name, shot_rank, shot_color, backspin, sidespin, hang_time, peak_height.
4. Emit enriched shot data over WebSocket.
5. Update React UI to display shot classification (name + rank + color), physics-based distances, and spin breakdown.
6. Graceful degradation: if only ball_speed is available (no camera/spin), pass what we have — OpenGolfCoach will calculate what it can.

Why this matters:
- Transforms OpenFlight from a speed-only monitor into a full shot analyzer as more sensors come online (camera for launch angle, rolling buffer for spin).

Acceptance criteria:
- Shots include physics-based carry/total distance when launch angle data is available.
- Shots include shot classification name, rank, and color in WebSocket events and UI.
- Spin decomposition shown in UI when spin data is available.
- Falls back gracefully to current estimation when minimal data is available.
- Unit tests cover the integration boundary (mock OpenGolfCoach responses).
- ARM (Pi) build verified — either PyPI wheel available or fork builds with maturin.

### P2 - OPS243-C FMCW range tracking integration

Status: Open (blocked — -C in transit, rolling buffer not yet supported on -C per OmniPreSense)

Issue:
- Current codebase only supports OPS243-A (CW Doppler). The OPS243-C adds FMCW range tracking but has a different capability set.

What the -C adds:
- Range measurement (1-60m) simultaneous with speed.
- Track ball distance through full flight — speed-at-range profile.
- Range + speed filtering combined (OY command) to isolate ball from clutter.
- Phase data output (OP/oP) — potential micro-Doppler spin path.
- Range resolution: 0.08m (best, x=16/128 buffer) to 0.62m (default).

Known limitations:
- Rolling buffer mode (raw I/Q capture) NOT supported on -C per OmniPreSense customer service (as of Feb 2026).
- Direct spin measurement via I/Q secondary FFT not possible on -C alone.
- OmniPreSense reference code uses G1 mode — may work on -C in future firmware.

Integration plan:
1. New radar driver module (or extend `ops243.py`) for -C FMCW command set (lowercase range commands: `u?`, `r>n`, `r<n`, `oF`, `oP`, `oR`).
2. Range-velocity tracker: collect speed + range pairs over ball flight, build deceleration profile.
3. Trajectory-based spin estimation: use OpenGolfCoach physics inverse — given measured speed-at-distance curve, back-calculate spin rate.
4. Dual-radar support: run -A (spin via rolling buffer) and -C (range tracking) simultaneously on separate USB ports.
5. Sensor fusion: combine -A spin estimate, -C trajectory estimate, and camera data with confidence weighting.

Acceptance criteria:
- -C detected and configured automatically when connected (separate from -A).
- Range + speed data emitted over WebSocket for UI display.
- Shot arc visualization using measured range-velocity data points.
- Graceful fallback if only -A or only -C is connected.

### P3 - Dual-radar + camera sensor fusion

Status: Open (depends on -C integration + OpenGolfCoach)

Issue:
- Individual sensors each have blind spots. Combined, they cover the full shot picture.

Sensor roles:
| Sensor | Position | Captures |
|---|---|---|
| OPS243-A | Behind ball | Raw I/Q at launch → direct spin (50-60% success) |
| OPS243-C | Behind ball | Speed + range through full flight → deceleration profile |
| IMX708 camera | Above/beside | Launch angle, spin axis (marked ball), horizontal direction |
| DTL camera | Down-the-line | Swing video replay, potential club head tracking at 120fps |

Cross-validation logic:
1. If -A spin succeeds + camera has spin axis → high confidence spin with full decomposition.
2. If -A spin fails → fall back to -C trajectory-based spin estimate + camera spin.
3. -C deceleration curve validates -A direct spin estimate when both available.
4. Camera horizontal launch angle + spin axis → estimated club face angle (via D-plane model).
5. OpenGolfCoach computes derived values (club path, face-to-path, shot classification) from combined data.

Shot arc rendering:
- -C provides actual measured speed at multiple range points through flight.
- OpenGolfCoach trajectory engine produces 3D flight path constrained by measured data.
- UI renders top-down view (draw/fade) and side view (height profile) per shot.

Acceptance criteria:
- Shots use best available data from whichever sensors are connected.
- Confidence score reflects how many sensors contributed.
- Shot arc displayed in UI when range tracking data is available.
- Graceful degradation: single radar still works as today.

### P3 - Shaft IMU sensor for club data

Status: Open (hardware design phase)

Issue:
- Club face angle, swing path, and attack angle cannot be measured directly from ball flight or camera at 30fps. They can only be estimated backwards from ball data. A shaft-mounted IMU gives direct measurement.

Hardware:
- ESP32-C3 SuperMini (~$4-10) — BLE-capable microcontroller, 22x18mm
- MPU-6050 / GY-521 (~$3-13) — 6-axis IMU (accel + gyro), I2C. 9-axis not needed — magnetometer unnecessary for swing measurement (calibrate at address, swing is too short for gyro drift).
- LiPo battery 400mAh (~$7-10) — JST-PH connector, ~13 hours at 30mA draw
- TP4056 USB-C charger (~$2-6) — LiPo charging with protection
- 3D-printed mount — grip cap or clip-on collar for the shaft
- Total cost: ~$35-41 (see PARTS.md for sourcing options)

What the shaft IMU measures directly:
- Club speed (angular velocity at known shaft length)
- Swing path (3D orientation through downswing)
- Attack angle (shaft angle at impact)
- Club face angle (twist of shaft around its axis at impact)
- Face-to-path (computed: face - path)
- Tempo (time between backswing start and impact)
- Shaft lean at impact
- Lie angle at impact

Architecture:
1. ESP32 firmware: sample MPU-6050 at 100Hz, detect swing via accelerometer threshold, buffer full swing data (~2 seconds), transmit impact window over BLE after swing completes. Orientation computed via complementary or Madgwick filter on-device.
2. Pi BLE receiver: Python service using `bleak` library, receives swing data, timestamps it.
3. Shot matching: correlate IMU swing timestamp with radar shot detection timestamp (should be within ~50ms).
4. Data fusion: merge IMU club data with radar ball data and camera data into enriched Shot object.
5. OpenGolfCoach: feed measured club_speed instead of estimated, improving smash factor and derived calculations.

Integration plan:
1. ESP32 firmware (Arduino or ESP-IDF): MPU-6050 init, swing detection, BLE GATT server with swing characteristic.
2. Python BLE client: connect to ESP32, subscribe to swing notifications, parse orientation data.
3. Swing-to-shot matcher: align IMU data with Shot objects by timestamp proximity.
4. Extend Shot dataclass: club_face_angle, swing_path, attack_angle, face_to_path, tempo, shaft_lean.
5. WebSocket + UI: display club data alongside ball data per shot.
6. 3D-print mount design (STL for the case project).

Acceptance criteria:
- ESP32+MPU-6050 captures swing data at 100Hz and transmits over BLE.
- Pi receives and parses club orientation data.
- Club data matched to correct shot within 100ms tolerance.
- UI displays club face, path, attack angle, and face-to-path per shot.
- Works with or without IMU connected (graceful degradation).
- Battery lasts at least 4 hours of range session use.

## Suggested Execution Order

1. Security hardening for Socket.IO and camera endpoints (both P0 items).
2. Rolling-buffer trigger reset fix + regression coverage.
3. Server and OPS243 integration tests for critical paths.
4. `server.py` decomposition and logging decoupling in focused refactors.
5. OpenGolfCoach integration for physics-based shot analysis.
6. OPS243-C FMCW range tracking integration.
7. Dual-radar + camera sensor fusion.
8. Shaft IMU sensor for club data.
9. Documentation synchronization after architecture refactor boundaries are settled.

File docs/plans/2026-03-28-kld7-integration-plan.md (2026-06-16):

# K-LD7 Full Stack Integration — Implementation Plan

> **For agentic workers:** REQUIRED SUB-SKILL: Use superpowers:subagent-driven-development (recommended) or superpowers:executing-plans to implement this plan task-by-task. Steps use checkbox (`- [ ]`) syntax for tracking.

**Goal:** Integrate the K-LD7 angle radar into the openflight server so it provides real-time vertical (or horizontal) angle data alongside OPS243 speed/spin data, displayed in the UI.

**Architecture:** K-LD7 streams TDAT+PDAT frames in a background thread into a ring buffer. When OPS243 detects a shot, we search the ring buffer for the ball pass (highest-magnitude event) and attach the angle to the Shot. The UI shows separate Vertical and Horizontal angle cards.

**Tech Stack:** Python (kld7 library, pyserial), React/TypeScript, Flask-SocketIO

**Spec:** `docs/plans/2026-03-28-kld7-integration-design.md`

---

## File Structure

| File | Action | Responsibility |
|---|---|---|
| `src/openflight/kld7/__init__.py` | Create | Package exports |
| `src/openflight/kld7/types.py` | Create | KLD7Angle, KLD7Frame dataclasses |
| `src/openflight/kld7/tracker.py` | Create | KLD7Tracker: connection, ring buffer, angle extraction |
| `src/openflight/server.py` | Modify | CLI flags, init_kld7(), on_shot_detected() K-LD7 step |
| `scripts/start-kiosk.sh` | Modify | Pass --kld7 flags |
| `ui/src/types/shot.ts` | Modify | Add angle_source field |
| `ui/src/components/ShotDisplay.tsx` | Modify | Split Launch Angle into Vertical + Horizontal cards |
| `tests/test_kld7.py` | Create | Unit tests for KLD7Tracker |
| `tests/test_server.py` | Modify | Test shot_to_dict with K-LD7 angle data |

---

### Task 1: K-LD7 Data Types

**Files:**
- Create: `src/openflight/kld7/__init__.py`
- Create: `src/openflight/kld7/types.py`
- Test: `tests/test_kld7.py`

- [ ] **Step 1: Create the kld7 package with types**

```bash
mkdir -p src/openflight/kld7
```

- [ ] **Step 2: Write types.py**

Create `src/openflight/kld7/types.py`:

```python
"""Data types for K-LD7 angle radar integration."""

from dataclasses import dataclass, field
from typing import Optional

@dataclass
class KLD7Frame:
    """A single frame from the K-LD7 radar stream."""

    timestamp: float
    tdat: Optional[dict] = None  # {"distance", "speed", "angle", "magnitude"}
    pdat: list = field(default_factory=list)  # list of target dicts

@dataclass
class KLD7Angle:
    """Angle measurement extracted from K-LD7 ring buffer after a shot."""

    vertical_deg: Optional[float] = None  # Populated when orientation="vertical"
    horizontal_deg: Optional[float] = None  # Populated when orientation="horizontal"
    distance_m: float = 0.0
    magnitude: float = 0.0
    confidence: float = 0.0  # 0.0 - 1.0
    num_frames: int = 0  # Frames with detection in the event
```

- [ ] **Step 3: Write __init__.py**

Create `src/openflight/kld7/__init__.py`:

```python
"""K-LD7 angle radar integration module."""

from .types import KLD7Angle, KLD7Frame

__all__ = ["KLD7Angle", "KLD7Frame"]
```

- [ ] **Step 4: Write basic type tests**

Create `tests/test_kld7.py`:

```python
"""Tests for K-LD7 angle radar integration."""

import pytest
from openflight.kld7.types import KLD7Angle, KLD7Frame

class TestKLD7Types:
    """Tests for K-LD7 data types."""

    def test_kld7_frame_defaults(self):
        frame = KLD7Frame(timestamp=1000.0)
        assert frame.timestamp == 1000.0
        assert frame.tdat is None
        assert frame.pdat == []

    def test_kld7_angle_vertical(self):
        angle = KLD7Angle(vertical_deg=12.5, distance_m=2.0, magnitude=5000, confidence=0.8, num_frames=3)
        assert angle.vertical_deg == 12.5
        assert angle.horizontal_deg is None

    def test_kld7_angle_horizontal(self):
        angle = KLD7Angle(horizontal_deg=-3.2, distance_m=1.5, magnitude=4000, confidence=0.7, num_frames=2)
        assert angle.horizontal_deg == -3.2
        assert angle.vertical_deg is None
```

- [ ] **Step 5: Run tests**

Run: `uv run pytest tests/test_kld7.py -v`
Expected: 3 tests PASS

- [ ] **Step 6: Commit**

```bash
git add src/openflight/kld7/ tests/test_kld7.py
git commit -m "feat(kld7): add K-LD7 data types (KLD7Angle, KLD7Frame)"
```

---

### Task 2: KLD7Tracker — Ring Buffer and Angle Extraction

**Files:**
- Create: `src/openflight/kld7/tracker.py`
- Modify: `src/openflight/kld7/__init__.py`
- Test: `tests/test_kld7.py`

- [ ] **Step 1: Write failing tests for KLD7Tracker**

Add to `tests/test_kld7.py`:

```python
import time
from unittest.mock import MagicMock, patch
from openflight.kld7.tracker import KLD7Tracker
from openflight.kld7.types import KLD7Angle, KLD7Frame

class TestKLD7TrackerRingBuffer:
    """Tests for ring buffer and angle extraction logic (no hardware)."""

    def _make_tracker(self, orientation="vertical"):
        """Create a tracker without connecting to hardware."""
        tracker = KLD7Tracker.__new__(KLD7Tracker)
        tracker.orientation = orientation
        tracker.buffer_seconds = 2.0
        tracker.max_buffer_frames = 70
        tracker._init_ring_buffer()
        return tracker

    def test_ring_buffer_stores_frames(self):
        tracker = self._make_tracker()
        now = time.time()
        for i in range(5):
            tracker._add_frame(KLD7Frame(
                timestamp=now + i * 0.03,
                tdat={"distance": 1.0, "speed": 5.0, "angle": 10.0 + i, "magnitude": 3000 + i * 100},
                pdat=[],
            ))
        assert len(tracker._ring_buffer) == 5

    def test_ring_buffer_max_size(self):
        tracker = self._make_tracker()
        tracker.max_buffer_frames = 10
        now = time.time()
        for i in range(20):
            tracker._add_frame(KLD7Frame(
                timestamp=now + i * 0.03,
                tdat={"distance": 1.0, "speed": 5.0, "angle": 0.0, "magnitude": 1000},
                pdat=[],
            ))
        assert len(tracker._ring_buffer) == 10

    def test_get_angle_finds_highest_magnitude_event(self):
        tracker = self._make_tracker(orientation="vertical")
        now = time.time()
        # Background noise frames
        for i in range(10):
            tracker._add_frame(KLD7Frame(
                timestamp=now + i * 0.03,
                tdat=None,
                pdat=[],
            ))
        # Ball pass: 3 frames with high magnitude at angle ~15°
        for i in range(3):
            tracker._add_frame(KLD7Frame(
                timestamp=now + 0.30 + i * 0.03,
                tdat={"distance": 2.0, "speed": 50.0, "angle": 14.0 + i, "magnitude": 5000 + i * 100},
                pdat=[{"distance": 2.0, "speed": 50.0, "angle": 14.0 + i, "magnitude": 5000 + i * 100}],
            ))
        # More noise after
        for i in range(5):
            tracker._add_frame(KLD7Frame(
                timestamp=now + 0.50 + i * 0.03,
                tdat=None,
                pdat=[],
            ))

        result = tracker.get_angle_for_shot()
        assert result is not None
        assert result.vertical_deg is not None
        assert 13.0 < result.vertical_deg < 17.0
        assert result.horizontal_deg is None
        assert result.num_frames == 3
        assert result.confidence > 0.0
        assert result.distance_m > 0.0

    def test_get_angle_returns_none_when_no_detections(self):
        tracker = self._make_tracker()
        now = time.time()
        for i in range(5):
            tracker._add_frame(KLD7Frame(timestamp=now + i * 0.03, tdat=None, pdat=[]))
        result = tracker.get_angle_for_shot()
        assert result is None

    def test_get_angle_horizontal_orientation(self):
        tracker = self._make_tracker(orientation="horizontal")
        now = time.time()
        tracker._add_frame(KLD7Frame(
            timestamp=now,
            tdat={"distance": 1.5, "speed": 30.0, "angle": -5.0, "magnitude": 4500},
            pdat=[{"distance": 1.5, "speed": 30.0, "angle": -5.0, "magnitude": 4500}],
        ))
        result = tracker.get_angle_for_shot()
        assert result is not None
        assert result.horizontal_deg is not None
        assert result.vertical_deg is None

    def test_reset_clears_buffer(self):
        tracker = self._make_tracker()
        tracker._add_frame(KLD7Frame(timestamp=time.time(), tdat={"distance": 1.0, "speed": 5.0, "angle": 0.0, "magnitude": 3000}, pdat=[]))
        assert len(tracker._ring_buffer) == 1
        tracker.reset()
        assert len(tracker._ring_buffer) == 0

    def test_prefers_pdat_over_tdat(self):
        """PDAT raw detections should be preferred for angle extraction."""
        tracker = self._make_tracker(orientation="vertical")
        now = time.time()
        # Frame with TDAT at 10° but PDAT at 20° (higher magnitude)
        tracker._add_frame(KLD7Frame(
            timestamp=now,
            tdat={"distance": 1.0, "speed": 5.0, "angle": 10.0, "magnitude": 3000},
            pdat=[{"distance": 1.5, "speed": 8.0, "angle": 20.0, "magnitude": 5000}],
        ))
        result = tracker.get_angle_for_shot()
        assert result is not None
        # Should use the PDAT target with higher magnitude
        assert abs(result.vertical_deg - 20.0) < 1.0
```

- [ ] **Step 2: Run tests to verify they fail**

Run: `uv run pytest tests/test_kld7.py::TestKLD7TrackerRingBuffer -v`
Expected: FAIL — `tracker` module doesn't exist yet

- [ ] **Step 3: Implement KLD7Tracker**

Create `src/openflight/kld7/tracker.py`:

```python
"""K-LD7 angle radar tracker with ring buffer for shot correlation."""

import logging
import threading
import time
from collections import deque
from typing import Optional

from .types import KLD7Angle, KLD7Frame

logger = logging.getLogger(__name__)

def _target_to_dict(target):
    """Convert a kld7 Target namedtuple to a dict."""
    if target is None:
        return None
    return {
        "distance": target.distance,
        "speed": target.speed,
        "angle": target.angle,
        "magnitude": target.magnitude,
    }

def _find_port():
    """Auto-detect K-LD7 EVAL board USB serial port."""
    try:
        from serial.tools.list_ports import comports
    except ImportError:
        return None
    for port in comports():
        desc = (port.description or "").lower()
        mfg = (port.manufacturer or "").lower()
        if any(kw in desc for kw in ["ftdi", "cp210", "usb-serial", "uart"]):
            return port.device
        if any(kw in mfg for kw in ["ftdi", "silicon labs"]):
            return port.device
    return None

class KLD7Tracker:
    """
    K-LD7 angle radar tracker.

    Streams TDAT+PDAT frames in a background thread into a ring buffer.
    When the OPS243 detects a shot, call get_angle_for_shot() to search
    the buffer for the ball pass and extract angle data.
    """

    def __init__(
        self,
        port: Optional[str] = None,
        range_m: int = 5,
        speed_kmh: int = 100,
        orientation: str = "vertical",
        buffer_seconds: float = 2.0,
    ):
        self.port = port
        self.range_m = range_m
        self.speed_kmh = speed_kmh
        self.orientation = orientation
        self.buffer_seconds = buffer_seconds
        # ~34 fps without FFT * 2 seconds
        self.max_buffer_frames = int(34 * buffer_seconds)

        self._radar = None
        self._stream_thread: Optional[threading.Thread] = None
        self._running = False
        self._init_ring_buffer()

    def _init_ring_buffer(self):
        """Initialize or reset the ring buffer."""
        self._ring_buffer: deque[KLD7Frame] = deque(maxlen=self.max_buffer_frames)

    def connect(self) -> bool:
        """Connect to K-LD7 and configure for golf."""
        try:
            from kld7 import KLD7, KLD7Exception
        except ImportError:
            logger.error("kld7 package not installed. Run: pip install kld7")
            return False

        port = self.port or _find_port()
        if not port:
            logger.error("No K-LD7 EVAL board detected")
            return False

        try:
            self._radar = KLD7(port, baudrate=115200)
            logger.info("K-LD7 connected on %s", port)
        except Exception as e:
            logger.error("K-LD7 connection failed: %s", e)
            return False

        # Configure for golf
        self._configure_for_golf()
        return True

    def _configure_for_golf(self):
        """Configure K-LD7 parameters for golf ball detection."""
        range_settings = {5: 0, 10: 1, 30: 2, 100: 3}
        speed_settings = {12: 0, 25: 1, 50: 2, 100: 3}

        params = self._radar.params
        params.RRAI = range_settings.get(self.range_m, 0)
        params.RSPI = speed_settings.get(self.speed_kmh, 3)
        params.DEDI = 2  # Both directions
        params.THOF = 10  # Low threshold
        params.TRFT = 1  # Fast detection
        params.MIAN = -90
        params.MAAN = 90
        params.MIRA = 0
        params.MARA = 100
        params.MISP = 0
        params.MASP = 100
        params.VISU = 0  # No vibration suppression

        logger.info(
            "K-LD7 configured: range=%dm, speed=%dkm/h, orientation=%s",
            self.range_m, self.speed_kmh, self.orientation,
        )

    def start(self):
        """Start the background streaming thread."""
        if self._running:
            return
        self._running = True
        self._stream_thread = threading.Thread(target=self._stream_loop, daemon=True)
        self._stream_thread.start()
        logger.info("K-LD7 streaming started (orientation=%s)", self.orientation)

    def stop(self):
        """Stop streaming and close connection."""
        self._running = False
        if self._stream_thread:
            self._stream_thread.join(timeout=5)
            self._stream_thread = None
        if self._radar:
            try:
                self._radar.close()
            except Exception:
                pass
            try:
                self._radar._port = None
            except Exception:
                pass
            self._radar = None
        logger.info("K-LD7 stopped")

    def _stream_loop(self):
        """Background thread: stream TDAT+PDAT into ring buffer."""
        from kld7 import FrameCode

        frame_codes = FrameCode.TDAT | FrameCode.PDAT
        current_frame = KLD7Frame(timestamp=time.time())
        seen_in_frame = set()

        try:
            for code, payload in self._radar.stream_frames(frame_codes, max_count=-1):
                if not self._running:
                    break

                # Detect frame boundary
                if code in seen_in_frame:
                    self._add_frame(current_frame)
                    current_frame = KLD7Frame(timestamp=time.time())
                    seen_in_frame = set()

                seen_in_frame.add(code)

                if code == "TDAT":
                    current_frame.tdat = _target_to_dict(payload)
                elif code == "PDAT":
                    current_frame.pdat = [_target_to_dict(t) for t in payload] if payload else []

            # Save final frame
            if seen_in_frame:
                self._add_frame(current_frame)

        except Exception as e:
            if self._running:
                logger.error("K-LD7 stream error: %s", e)

    def _add_frame(self, frame: KLD7Frame):
        """Add a frame to the ring buffer."""
        self._ring_buffer.append(frame)

    def get_angle_for_shot(self) -> Optional[KLD7Angle]:
        """
        Search the ring buffer for the ball pass and extract angle data.

        Finds the highest-magnitude detection event in the buffer.
        Prefers PDAT (raw detections) over TDAT (tracked target).
        Returns KLD7Angle or None if no detections found.
        """
        # Collect all detections from the buffer
        detections = []  # (timestamp, angle, distance, magnitude, source)

        for frame in self._ring_buffer:
            # Prefer PDAT targets (more reliable for transient targets)
            if frame.pdat:
                for target in frame.pdat:
                    if target is not None and target.get("magnitude", 0) > 0:
                        detections.append((
                            frame.timestamp,
                            target["angle"],
                            target["distance"],
                            target["magnitude"],
                        ))
            elif frame.tdat and frame.tdat.get("magnitude", 0) > 0:
                detections.append((
                    frame.timestamp,
                    frame.tdat["angle"],
                    frame.tdat["distance"],
                    frame.tdat["magnitude"],
                ))

        if not detections:
            return None

        # Find the peak magnitude detection
        peak = max(detections, key=lambda d: d[3])
        peak_time = peak[0]

        # Collect all detections within 0.5s of the peak (the "event")
        event_detections = [
            d for d in detections if abs(d[0] - peak_time) < 0.5
        ]

        if not event_detections:
            return None

        # Weighted average angle (weighted by magnitude)
        total_mag = sum(d[3] for d in event_detections)
        if total_mag == 0:
            return None

        avg_angle = sum(d[1] * d[3] for d in event_detections) / total_mag
        avg_distance = sum(d[2] * d[3] for d in event_detections) / total_mag
        max_magnitude = max(d[3] for d in event_detections)
        num_frames = len(set(d[0] for d in event_detections))

        # Confidence based on:
        # - Number of frames with detections (more = better)
        # - Magnitude strength (higher = better signal)
        # - Angle consistency (lower std dev = better)
        frame_score = min(num_frames / 3.0, 1.0)  # 3+ frames = full score
        mag_score = min(max_magnitude / 5000.0, 1.0)  # 5000+ = full score

        angles = [d[1] for d in event_detections]
        if len(angles) > 1:
            mean_angle = sum(angles) / len(angles)
            angle_std = (sum((a - mean_angle) ** 2 for a in angles) / len(angles)) ** 0.5
            consistency_score = max(0.0, 1.0 - angle_std / 20.0)  # 20°+ std = 0
        else:
            consistency_score = 0.5  # Single frame — moderate confidence

        confidence = frame_score * 0.4 + mag_score * 0.3 + consistency_score * 0.3
        confidence = round(min(max(confidence, 0.0), 1.0), 2)

        # Map angle to orientation
        if self.orientation == "vertical":
            return KLD7Angle(
                vertical_deg=round(avg_angle, 1),
                horizontal_deg=None,
                distance_m=round(avg_distance, 2),
                magnitude=max_magnitude,
                confidence=confidence,
                num_frames=num_frames,
            )
        else:
            return KLD7Angle(
                vertical_deg=None,
                horizontal_deg=round(avg_angle, 1),
                distance_m=round(avg_distance, 2),
                magnitude=max_magnitude,
                confidence=confidence,
                num_frames=num_frames,
            )

    def reset(self):
        """Clear the ring buffer after a shot is processed."""
        self._ring_buffer.clear()
```

- [ ] **Step 4: Update __init__.py exports**

Modify `src/openflight/kld7/__init__.py`:

```python
"""K-LD7 angle radar integration module."""

from .types import KLD7Angle, KLD7Frame
from .tracker import KLD7Tracker

__all__ = ["KLD7Angle", "KLD7Frame", "KLD7Tracker"]
```

- [ ] **Step 5: Run tests**

Run: `uv run pytest tests/test_kld7.py -v`
Expected: All tests PASS

- [ ] **Step 6: Commit**

```bash
git add src/openflight/kld7/ tests/test_kld7.py
git commit -m "feat(kld7): implement KLD7Tracker with ring buffer and angle extraction"
```

---

### Task 3: Server Integration — CLI Flags and Init

**Files:**
- Modify: `src/openflight/server.py:1169-1277` (argparse), `src/openflight/server.py:1294-1359` (main startup)
- Modify: `scripts/start-kiosk.sh:13-85` (arg parsing), `scripts/start-kiosk.sh:144-176` (command building)

- [ ] **Step 1: Add CLI flags to server.py argparse**

In `src/openflight/server.py`, after the `--gpio-debounce` argument (line 1275), add:

```python
    parser.add_argument(
        "--kld7", action="store_true", help="Enable K-LD7 angle radar module"
    )
    parser.add_argument(
        "--kld7-port", default=None, help="K-LD7 serial port (auto-detect if not specified)"
    )
    parser.add_argument(
        "--kld7-orientation",
        choices=["vertical", "horizontal"],
        default="vertical",
        help="K-LD7 mount orientation — which angle plane it measures (default: vertical)",
    )
```

- [ ] **Step 2: Add K-LD7 globals and init function**

In `src/openflight/server.py`, after the camera globals (near line 30), add:

```python
# K-LD7 angle radar
kld7_tracker = None
```

After the `init_camera()` function (after line 302), add:

```python
def init_kld7(port=None, orientation="vertical") -> bool:
    """Initialize K-LD7 angle radar tracker."""
    global kld7_tracker  # pylint: disable=global-statement
    try:
        from openflight.kld7 import KLD7Tracker

        kld7_tracker = KLD7Tracker(port=port, orientation=orientation)
        if kld7_tracker.connect():
            kld7_tracker.start()
            return True
        else:
            kld7_tracker = None
            return False
    except Exception as e:
        logger.warning("K-LD7 initialization failed: %s", e)
        kld7_tracker = None
        return False
```

- [ ] **Step 3: Wire up K-LD7 init in main()**

In `src/openflight/server.py` `main()`, after the camera init block (after line 1349), add:

```python
    # Initialize K-LD7 angle radar (if enabled)
    if args.kld7:
        if init_kld7(port=args.kld7_port, orientation=args.kld7_orientation):
            print(f"K-LD7 angle radar enabled (orientation: {args.kld7_orientation})")
        else:
            print("K-LD7 not available - running without angle radar")
    ```

- [ ] **Step 4: Add K-LD7 cleanup in finally block**

In `src/openflight/server.py`, in the `finally` block at the end of `main()` (line 1374), add before `stop_monitor()`:

```python
        if kld7_tracker:
            kld7_tracker.stop()
```

- [ ] **Step 5: Add --kld7 flags to start-kiosk.sh**

In `scripts/start-kiosk.sh`, add variable declarations after line 20:

```bash
KLD7=false
KLD7_PORT=""
KLD7_ORIENTATION=""
```

In the `while` loop (after line 76), add cases:

```bash
        --kld7)
            KLD7=true
            shift
            ;;
        --kld7-port)
            KLD7_PORT="$2"
            shift 2
            ;;
        --kld7-orientation)
            KLD7_ORIENTATION="$2"
            shift 2
            ;;
```

In the command building section (after line 176), add:

```bash
if [ "$KLD7" = true ]; then
    SERVER_CMD="$SERVER_CMD --kld7"
fi

if [ -n "$KLD7_PORT" ]; then
    SERVER_CMD="$SERVER_CMD --kld7-port $KLD7_PORT"
fi

if [ -n "$KLD7_ORIENTATION" ]; then
    SERVER_CMD="$SERVER_CMD --kld7-orientation $KLD7_ORIENTATION"
fi
```

- [ ] **Step 6: Commit**

```bash
git add src/openflight/server.py scripts/start-kiosk.sh
git commit -m "feat(kld7): add --kld7 CLI flags and server init"
```

---
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

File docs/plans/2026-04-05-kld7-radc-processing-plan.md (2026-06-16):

# K-LD7 Raw ADC Processing — Implementation Plan

> **For agentic workers:** REQUIRED SUB-SKILL: Use superpowers:subagent-driven-development (recommended) or superpowers:executing-plans to implement this plan task-by-task. Steps use checkbox (`- [ ]`) syntax for tracking.

**Goal:** Build capture and analysis tools for K-LD7 raw I/Q ADC data, enabling custom FFT + CFAR signal processing that can detect ball returns the module's built-in detector misses.

**Architecture:** A standalone capture script records RADC + PDAT frames to `.pkl`. A processing library (`kld7_radc_lib.py`) handles FFT, CFAR, angle estimation, and ball isolation — numpy only, no plotting. A separate analysis script generates visualizations and CSV exports. All tools are offline and independent of the live tracker.

**Tech Stack:** Python 3.10+, numpy, matplotlib (analysis only), kld7 package

---

## File Structure

| File | Responsibility |
|---|---|
| `scripts/capture_kld7_radc.py` | CLI capture tool — stream RADC+PDAT at 3 Mbaud, save to `.pkl` |
| `scripts/kld7_radc_lib.py` | Processing library — RADC parsing, FFT, CFAR, angle estimation, ball isolation |
| `scripts/analyze_kld7_radc.py` | Analysis CLI — load captures, generate plots and CSV |
| `tests/test_kld7_radc_lib.py` | Tests for the processing library |

---

### Task 1: RADC Parsing Library

**Files:**
- Create: `scripts/kld7_radc_lib.py`
- Create: `tests/test_kld7_radc_lib.py`

- [ ] **Step 1: Write failing test for RADC frame parsing**

```python
# tests/test_kld7_radc_lib.py
"""Tests for K-LD7 raw ADC processing library."""

import sys
from pathlib import Path

import numpy as np
import pytest

sys.path.insert(0, str(Path(__file__).parent.parent / "scripts"))

from kld7_radc_lib import parse_radc_payload

class TestParseRadcPayload:
    def test_parses_3072_bytes_into_six_channels(self):
        """RADC payload should split into 6 arrays of 256 uint16 samples."""
        # Create synthetic 3072-byte payload: 6 segments of 256 uint16 values
        payload = b""
        for seg in range(6):
            payload += np.arange(seg * 256, (seg + 1) * 256, dtype=np.uint16).tobytes()

        result = parse_radc_payload(payload)

        assert result["f1a_i"].shape == (256,)
        assert result["f1a_q"].shape == (256,)
        assert result["f2a_i"].shape == (256,)
        assert result["f2a_q"].shape == (256,)
        assert result["f1b_i"].shape == (256,)
        assert result["f1b_q"].shape == (256,)
        assert result["f1a_i"].dtype == np.uint16
        # Verify first segment starts at 0
        assert result["f1a_i"][0] == 0
        assert result["f1a_i"][255] == 255
        # Verify second segment starts at 256
        assert result["f1a_q"][0] == 256
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

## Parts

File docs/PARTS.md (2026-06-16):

# OpenFlight Parts List

Hardware components for building the OpenFlight golf launch monitor.

> **Next step after gathering parts:** See the [Raspberry Pi Setup Guide](raspberry-pi-setup.md) for assembly and software installation.

## Core Components

| Part | Description | Link | ~Price |
|---|---|---|---|
| **OPS243 Radar** | Doppler radar for ball/club speed detection | [OmniPreSense](https://omnipresense.com/product/ops243-doppler-radar-sensor/) | $249 |
| **Raspberry Pi 5** | Main compute unit (4GB+ recommended) | [Adafruit](https://www.adafruit.com/product/5812) | $60 |
| **Raspberry Pi Camera Module 3 Wide** | IMX708 wide-angle (120° FOV), optional — for DTL swing video recording | [Adafruit](https://www.adafruit.com/product/5658) | $35 |

> **WARNING: Do NOT buy the OPS243-A-W (WiFi version).** The WiFi module locks the serial baud rate to 19200, which is far too slow for I/Q data transfer. OpenFlight requires the standard **OPS243** (USB only) which runs at 57600 baud over CDC-ACM. The WiFi version is not compatible.
| **7" Touchscreen Display** | HMTECH 7" 1024x600 IPS display | [Amazon](https://www.amazon.com/dp/B0D3QB7X4Z) | $46 |

## Sound Trigger (for Rolling Buffer Mode)

The sound trigger detects club impact to precisely time radar captures. Essential for spin detection via rolling buffer mode.

| Part | Description | Link | ~Price |
|---|---|---|---|
| **SparkFun SEN-14262** | Sound Detector with envelope/gate outputs | [SparkFun](https://www.sparkfun.com/products/14262) | $12 |
| **Through-hole resistor** | For R17 pad on SEN-14262 to reduce sensitivity (see note) | Any electronics supplier | $1 |
| **Jumper Wires** | 3 wires: GATE → HOST_INT, VCC → 3.3V, GND → GND | Any | $5 |

> **R17 resistor:** The SEN-14262 is rated for 5V but runs at 3.3V in this setup, which can cause the GATE output to stick high. Soldering a resistor into the R17 through-hole position (in parallel with the onboard 100kΩ R3) reduces preamp gain and fixes this. Start with 47kΩ; use a lower value (e.g. 33kΩ) if the sensor is still too sensitive for your environment.

### Sound Trigger Wiring

```
SEN-14262               Raspberry Pi           OPS243
┌───────────┐          ┌──────────┐          ┌──────────┐
│ VCC ──────┼──────────┤ 3.3V     │          │          │
│           │          │          │          │          │
│ GATE ─────┼──────────┼──────────┼──────────┤ HOST_INT │
│           │          │          │          │ (J3 P3)  │
│ GND ──────┼──────────┤ GND      ├──────────┤ GND      │
│           │          │          │          │ (J3 P1)  │
└───────────┘          └──────────┘          └──────────┘
```

See [sound-trigger-wiring.md](sound-trigger-wiring.md) for detailed instructions and troubleshooting.

## Angle Radar (K-LD7)

Two K-LD7 modules measure launch angle (vertical) and club path / aim direction (horizontal). The OPS243 handles speed; the K-LD7s provide **angle and distance only** (speed data aliases above 62 mph).

| Part | Description | Link | ~Price |
|---|---|---|---|
| **RFbeam K-LD7 (×2)** | 24 GHz FMCW radar for angle + distance | [RFbeam](https://rfbeam.ch/product/k-ld7-radar-transceiver/) | ~$60 ea |
| **FTDI USB-to-Serial adapter (×2)** | 3.3V FTDI board for K-LD7 UART (e.g. FT232RL) | [Amazon](https://www.amazon.com/s?k=ftdi+3.3v+usb+serial) | ~$10 |

> **EVAL board not required.** The K-LD7 bare module communicates over 3.3V UART (TX, RX, VCC, GND). Any 3.3V FTDI USB-to-serial adapter works. The official K-LD7 EVAL board (~$120 each) is only needed if you want the RFbeam GUI software for configuration — OpenFlight configures the radar over serial automatically.

### K-LD7 Connection

Each K-LD7 connects via a 3.3V FTDI adapter, appearing as `/dev/ttyUSB*` on Linux.

```
K-LD7 Module (UART) → FTDI 3.3V Adapter → USB → Raspberry Pi
```

One unit is mounted vertically (launch angle), one horizontally (club path / aim direction). A `--kld7-angle-offset` parameter corrects for mounting geometry — see the [setup guide](raspberry-pi-setup.md) for calibration.

## Power & Accessories

| Part | Description | Link | ~Price |
|---|---|---|---|
| **27W USB-C Power Supply** | Official Pi 5 power supply (5V 5A) | [Adafruit](https://www.adafruit.com/product/5974) | $12 |
| MicroSD Card (32GB+) | For Pi OS and software | Any Class 10 | $10 |
| USB-A to Micro-USB Cable | For OPS243 radar connection | Any | $5 |

## Shaft IMU Sensor (for club data)

A shaft-mounted IMU measures club face angle, swing path, attack angle, and tempo directly. Communicates to the Pi over BLE. See [ENGINEERING_BACKLOG.md](ENGINEERING_BACKLOG.md) for integration plan.

**Option A: Adafruit (one vendor, STEMMA QT plug-and-play I2C, ~$41 shipped)**

| Part | Description | Link | ~Price |
|---|---|---|---|
| **Adafruit QT Py ESP32-C3** | BLE 5.0 + WiFi, STEMMA QT connector | [Adafruit](https://www.adafruit.com/product/5405) | $9.95 |
| **Adafruit MPU-6050** | 6-axis accel + gyro, STEMMA QT | [Adafruit](https://www.adafruit.com/product/3886) | $12.95 |
| **3.7V 400mAh LiPo** | JST-PH 2.0mm, fits Adafruit boards | [Adafruit](https://www.adafruit.com/product/3898) | $6.95 |
| **Micro-Lipo USB-C Charger** | LiPo charger with protection | [Adafruit](https://www.adafruit.com/product/4410) | $5.95 |
| Shipping | Flat rate | Adafruit | ~$5 |

**Option B: Amazon clone boards (bulk packs, free Prime shipping, ~$35-40)**

| Part | Description | Link | ~Price |
|---|---|---|---|
| ESP32-C3 SuperMini (5-pack) | BLE 5.0 + WiFi, 22x18mm | Search "ESP32-C3 SuperMini" | ~$12-15 |
| GY-521 MPU-6050 (3-pack) | 6-axis accel + gyro, I2C | Search "GY-521 MPU-6050" | ~$6-8 |
| 3.7V 400mAh LiPo | JST-PH connector | Search "3.7V 400mAh LiPo JST" | ~$8-10 |
| TP4056 USB-C (5-pack) | LiPo charger with protection | Search "TP4056 USB-C charger" | ~$7-8 |

### Shaft IMU Wiring (I2C, 4 wires)

```
ESP32-C3          MPU-6050
  3.3V  ────────  VIN
  GND   ────────  GND
  GPIO6 ────────  SDA
  GPIO7 ────────  SCL
```

With Adafruit STEMMA QT boards (Option A), use a STEMMA QT cable instead of wiring — no soldering needed.

**Power:** LiPo → TP4056/Micro-Lipo → ESP32-C3 (3.3V out powers MPU-6050)

**Battery life:** 400mAh at ~30mA draw (BLE + IMU) = ~13 hours.

## Optional

| Part | Description | Link | ~Price |
|---|---|---|---|
| Tripod Mount | For positioning the unit | 1/4"-20 mount | $10 |

---

## Cost Summary

| Category | ~Price |
|---|---|
| Core (OPS243, Pi 5, Display) | $355 |
| Sound Trigger (SEN-14262 + resistor + wires) | $18 |
| Angle Radar (2× K-LD7 + FTDI adapters) | $140 |
| Power & Accessories | $27 |
| **Total** | **~$540** |

> The angle radar is the most expensive component. OpenFlight works without it — you'll get ball speed, club speed, smash factor, and estimated carry. The K-LD7s add measured launch angle and club path data.

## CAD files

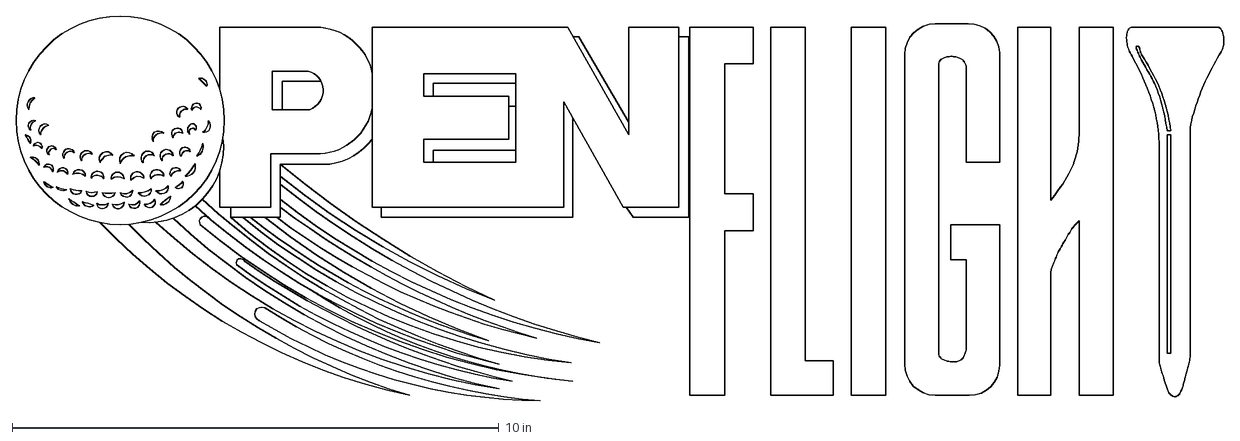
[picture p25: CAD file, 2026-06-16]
cad/logo/MainLogo.DXF
24.8 x 7.90 in

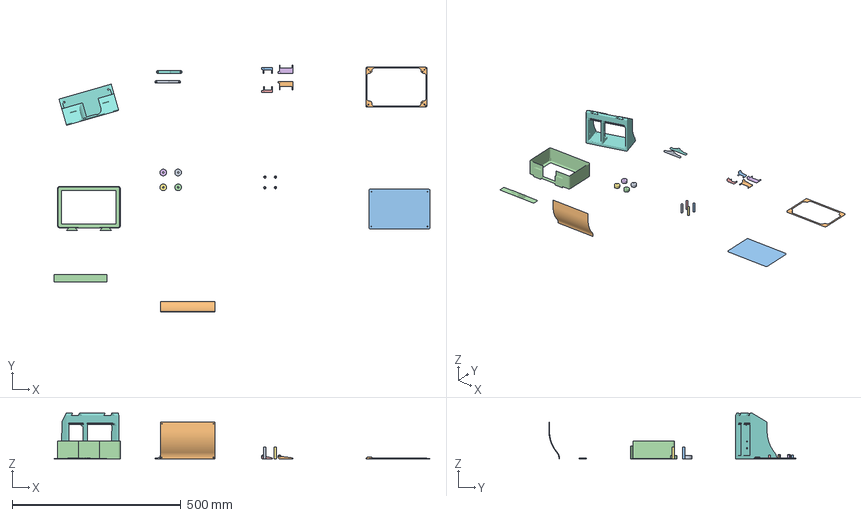
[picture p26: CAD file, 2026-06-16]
cad/IARC_case/IARC_Case_v3.3mf
1113.5 x 732.3 x 136.2 mm
case_foot.stl x 4
curvy_backplate.stl
monitor_standoffs.stl x 4
monitor_shell.stl
KLD7_v_mount_L_v2.stl
sensor_housing.stl
KLD7_v_mount_R_v2.stl
KLD7_h_mount_L_v2.stl
KLD7_h_mount_R_v2.stl
OPS_mount.stl x 2
monitor_mount.stl
monitor_back.stl
name_plate.stl

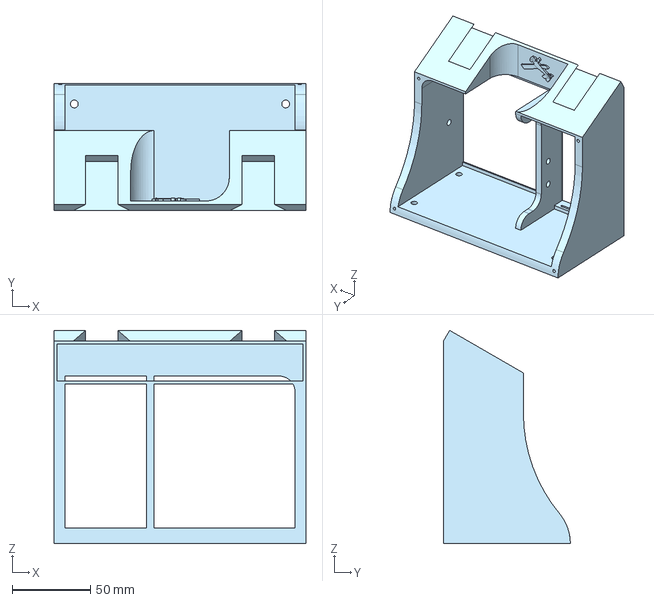
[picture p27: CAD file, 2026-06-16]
cad/IARC_case/step/sensor_housing.step
161.0 x 81.0 x 136.2 mm

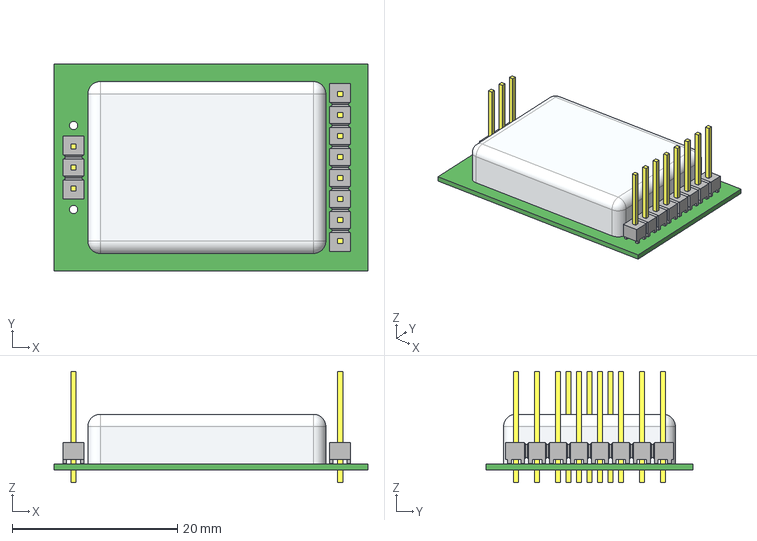
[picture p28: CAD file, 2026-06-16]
cad/K-LD7-RFB.step
38.0 x 25.0 x 13.5 mm

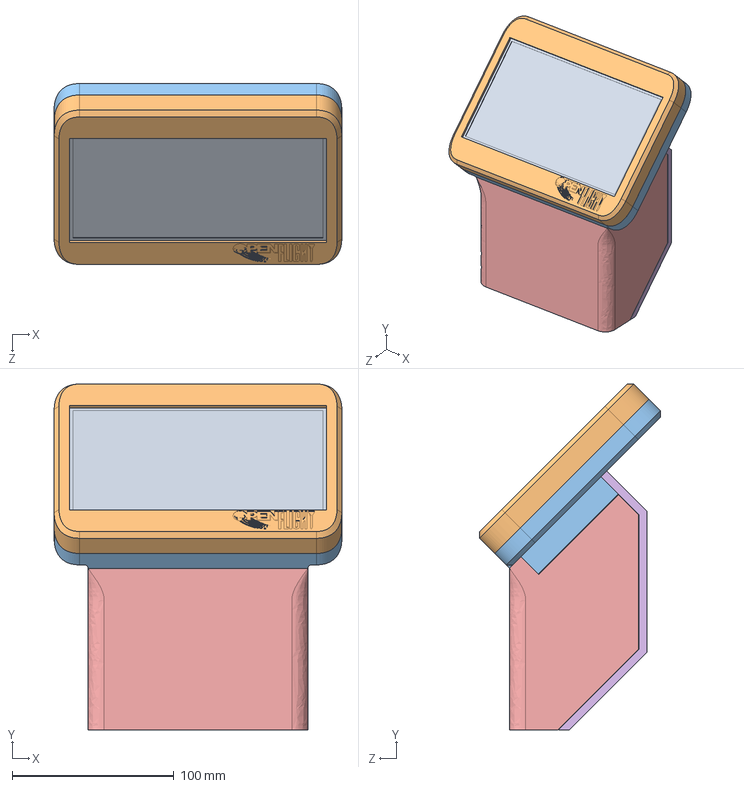
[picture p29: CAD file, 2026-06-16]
cad/LordFarq/OpenFlight_LF.STEP
178.0 x 214.0 x 111.9 mm
Screen
ScreenBezelFront
RearScreen
OPS243
BaseFront
BaseRear

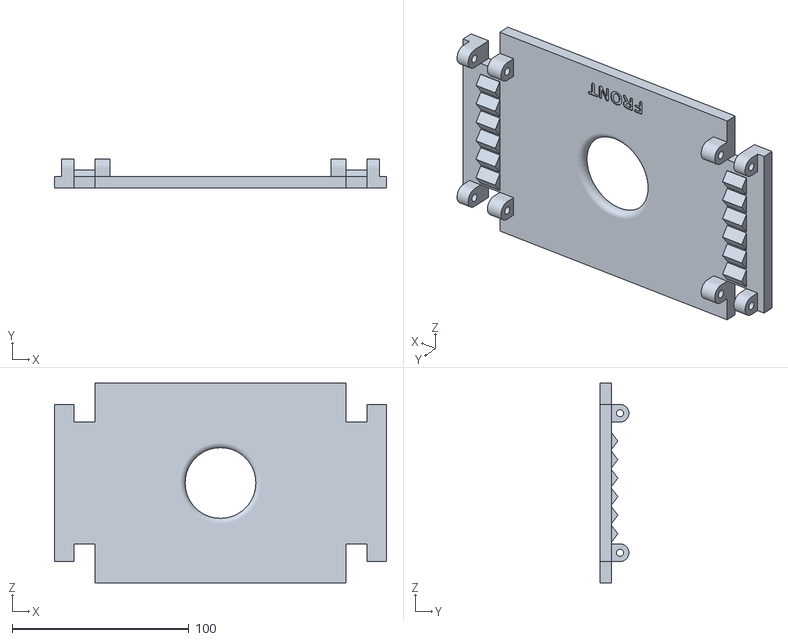
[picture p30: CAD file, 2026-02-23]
cad/printable-enclosure/launchmonitorbox/LCD PLATE.STL
188.0 x 16.4 x 113.0

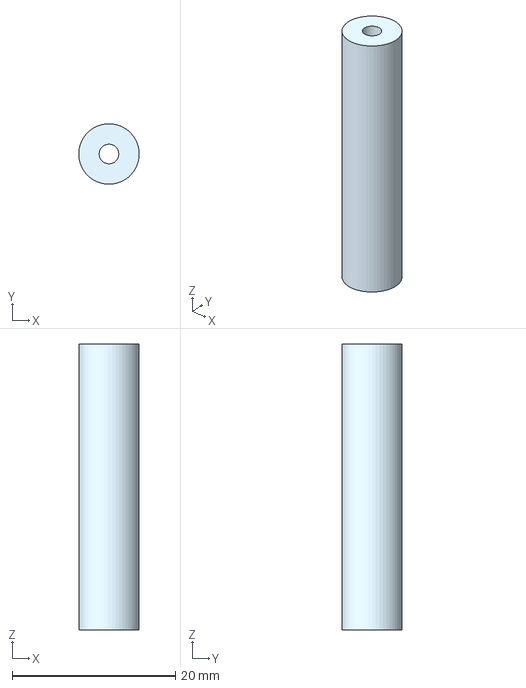
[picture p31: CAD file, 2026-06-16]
cad/IARC_case/step/monitor_standoffs.step
7.39 x 7.40 x 35.0 mm

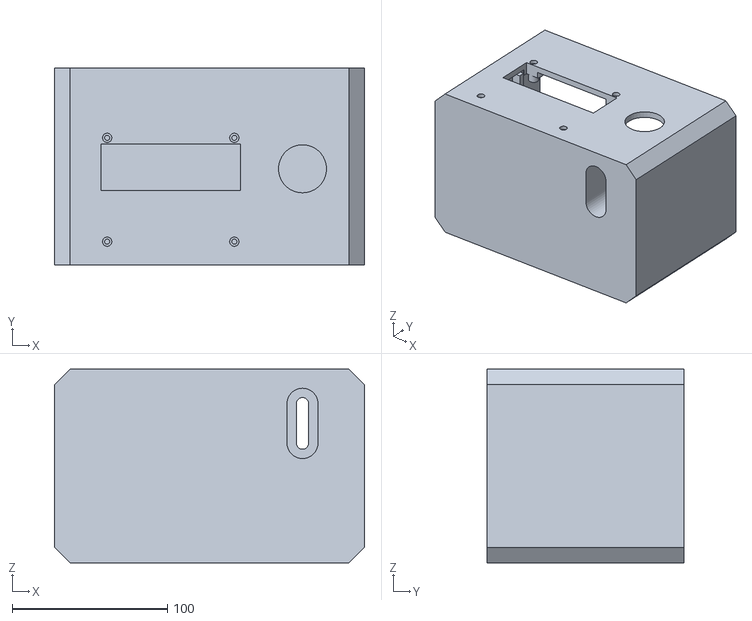
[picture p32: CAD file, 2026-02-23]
cad/printable-enclosure/launchmonitorbox/LaunchBox_Open.STL
200.0 x 127.0 x 125.0

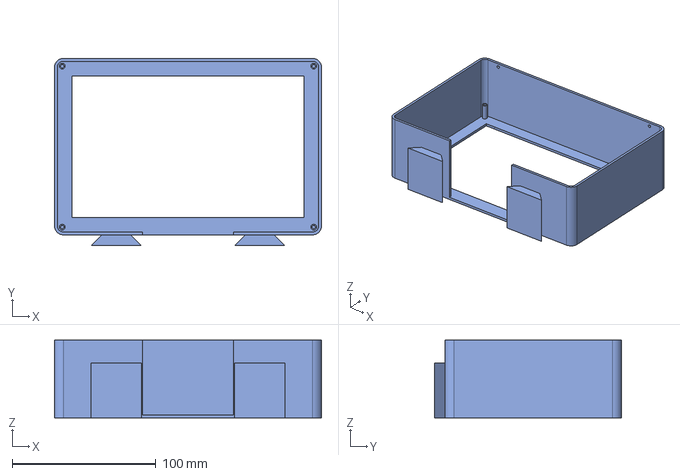
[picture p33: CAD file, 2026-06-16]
cad/IARC_case/step/monitor_shell.step
185.8 x 130.3 x 54.0 mm

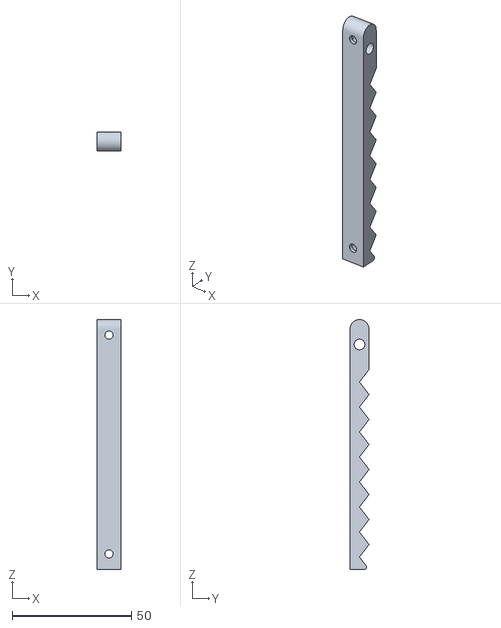
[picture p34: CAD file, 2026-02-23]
cad/printable-enclosure/launchmonitorbox/LCD ANGLE BRACKET.STL
10.0 x 8.00 x 105.0

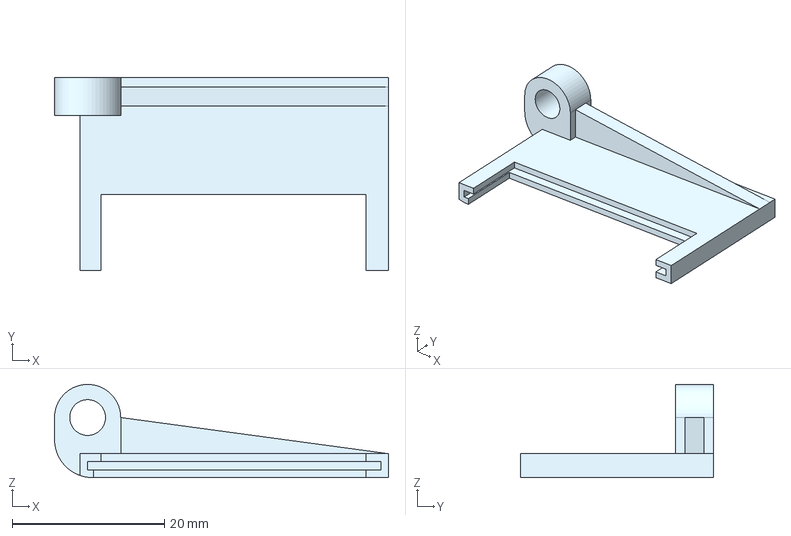
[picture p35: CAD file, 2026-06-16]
cad/IARC_case/step/KLD7_v_mount_R_v2.step
43.8 x 25.3 x 12.2 mm

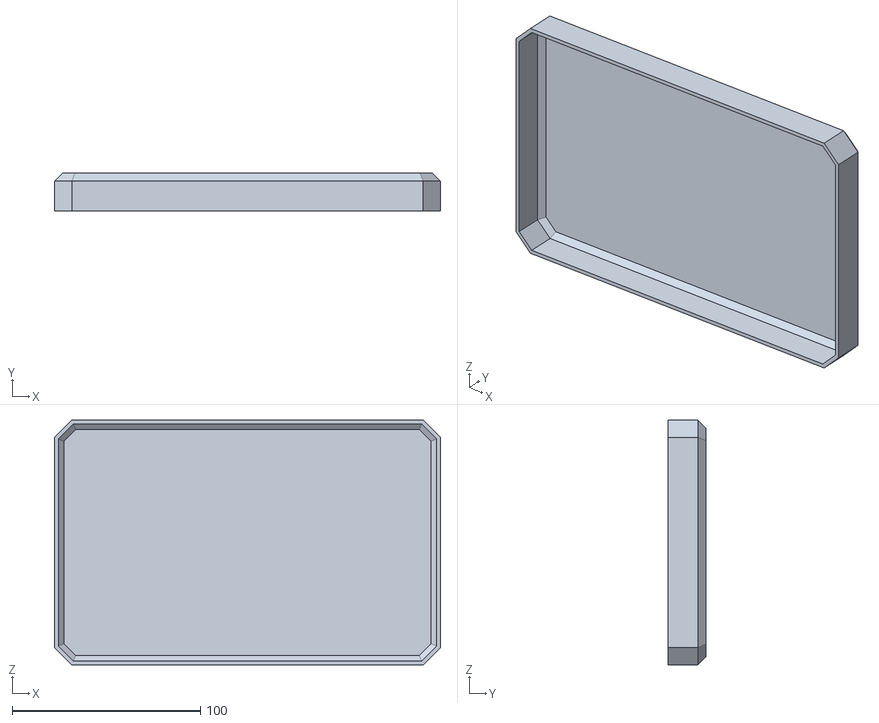
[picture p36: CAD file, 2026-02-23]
cad/printable-enclosure/launchmonitorbox/LID.STL
205.0 x 20.0 x 130.0

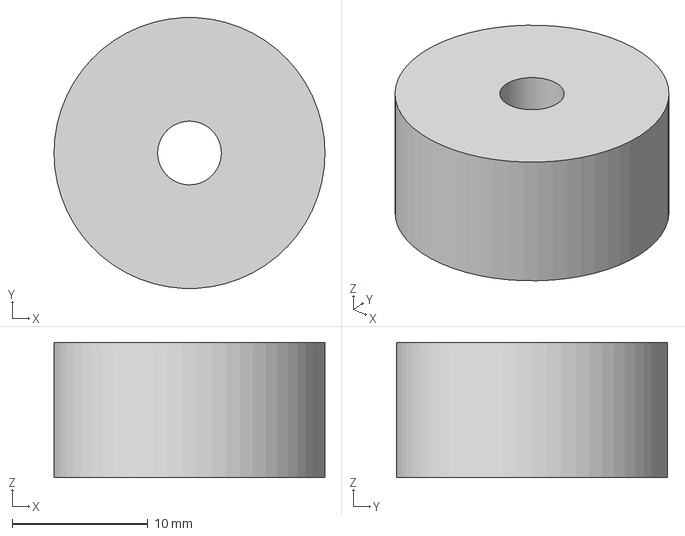
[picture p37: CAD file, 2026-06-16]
cad/IARC_case/step/case_foot.step
20.0 x 20.0 x 10.0 mm

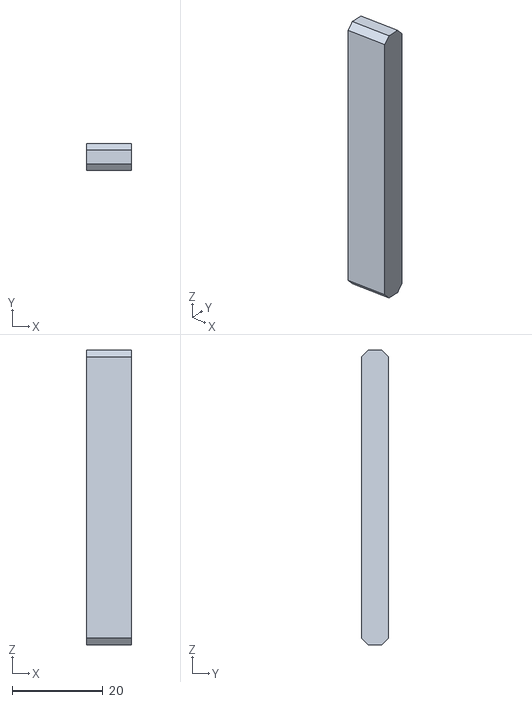
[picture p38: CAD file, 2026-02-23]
cad/printable-enclosure/launchmonitorbox/ANGLE STOP.STL
10.0 x 6.00 x 65.0

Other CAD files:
cad/printable-enclosure/launchmonitorbox/LaunchBox.STL
cad/IARC_case/step/KLD7_v_mount_L_v2.step
cad/IARC_case/step/OPS_mount.step
cad/IARC_case/step/curvy_backplate.step
cad/IARC_case/step/KLD7_h_mount_L_v2.step
cad/IARC_case/step/KLD7_h_mount_R_v2.step
cad/IARC_case/step/monitor_back.step
cad/IARC_case/step/monitor_mount.step
cad/IARC_case/step/name_plate.step
cad/IARC_case/stl/KLD7_h_mount_L_v2.stl
cad/IARC_case/stl/KLD7_h_mount_R_v2.stl
cad/IARC_case/stl/KLD7_v_mount_L_v2.stl
cad/IARC_case/stl/KLD7_v_mount_R_v2.stl
cad/IARC_case/stl/OPS_mount.stl
cad/IARC_case/stl/case_foot.stl
cad/IARC_case/stl/curvy_backplate.stl
cad/IARC_case/stl/monitor_back.stl
cad/IARC_case/stl/monitor_mount.stl
cad/IARC_case/stl/monitor_shell.stl
cad/IARC_case/stl/monitor_standoffs.stl
cad/IARC_case/stl/name_plate.stl
cad/IARC_case/stl/sensor_housing.stl

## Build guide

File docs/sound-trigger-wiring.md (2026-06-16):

# Sound Trigger Wiring Guide

Step-by-step instructions for wiring the sound trigger that enables spin detection in rolling buffer mode.

> **Parts needed:** See the [Parts List](PARTS.md#sound-trigger-for-rolling-buffer-mode) for what to buy.

## Overview

The SparkFun SEN-14262 sound detector listens for club impact and triggers the OPS243-A radar to dump its I/Q buffer. That captured data is then analyzed for spin rate estimation.

The wiring is simple — three wires:

```
SEN-14262 GATE → OPS243-A HOST_INT (J3 Pin 3)
SEN-14262 VCC  → Raspberry Pi 3.3V
SEN-14262 GND  → Raspberry Pi GND (shared with OPS243-A GND)
```

## Before You Wire: Solder R17

**R17 is not a part already on the board — it's an empty pair of solder pads** (a footprint) that SparkFun left on the Sound Detector so you can tune the microphone preamp. The silkscreen prints `R17` next to the two empty holes, in the preamp section right beside the surface-mount resistor **R3**. You bridge those two pads with one through-hole resistor. Resistors aren't polarized, so orientation doesn't matter.

**Why it's needed:** the SEN-14262 is factory-tuned for 5V. At the 3.3V used here the preamp gain is too high, so the GATE output saturates and gets stuck high (always "triggered"). Adding R17 lowers the gain so GATE fires only on a sharp, loud transient — a club striking the ball.

**How it works:** R17 sits electrically *in parallel* with the onboard 100kΩ R3. Two resistors in parallel combine to less than either one alone, and a smaller feedback resistor means lower amplifier gain:

| R17 value | R17 ∥ R3 (100kΩ) | Effect | When to use |
|---|---|---|---|
| 47kΩ | ~32kΩ | Moderate gain reduction | Start here |
| 33kΩ | ~25kΩ | More reduction | Still too sensitive / noisy room |

Start with 47kΩ. After wiring, clap near the sensor: the onboard GATE LED should flash briefly then go dark. If the LED stays lit constantly, the gain is still too high — switch to a lower value.

> Board photos showing the exact R17 location are in SparkFun's [Sound Detector Hookup Guide](https://learn.sparkfun.com/tutorials/sound-detector-hookup-guide/all).

---

## Wiring

### Step 1: Identify OPS243-A J3 Header Pins

```
OPS243-A J3 Header:
┌───┬───┬───┬───┬───┬───┐
│ 1 │ 2 │ 3 │ 4 │ 5 │ 6 │
│GND│   │INT│   │   │   │
└───┴───┴───┴───┴───┴───┘
```

- **Pin 1** = GND
- **Pin 3** = HOST_INT (trigger input)

### Step 2: Connect Power

1. Connect **SEN-14262 VCC** → **Pi 3.3V** (physical pin 1)
2. Connect **SEN-14262 GND** → **Pi GND** (physical pin 6)
3. Connect **OPS243-A GND (J3 Pin 1)** → same **Pi GND** rail

All three boards must share a common ground.

### Step 3: Connect Trigger

1. Connect **SEN-14262 GATE** → **OPS243-A HOST_INT (J3 Pin 3)**

That's it. No level shifter, no MOSFETs, no breadboard needed.

```
SEN-14262               Raspberry Pi           OPS243-A
┌───────────┐          ┌──────────┐          ┌──────────┐
│ VCC ──────┼──────────┤ 3.3V     │          │          │
│           │          │          │          │          │
│ GATE ─────┼──────────┼──────────┼──────────┤ HOST_INT │
│           │          │          │          │ (J3 P3)  │
│ GND ──────┼──────────┤ GND      ├──────────┤ GND      │
│           │          │          │          │ (J3 P1)  │
└───────────┘          └──────────┘          └──────────┘
```

---

## Wiring Checklist

- [ ] R17 resistor soldered on SEN-14262 board
- [ ] SEN-14262 VCC → Pi 3.3V (pin 1)
- [ ] SEN-14262 GND → Pi GND (pin 6)
- [ ] SEN-14262 GATE → OPS243-A HOST_INT (J3 Pin 3)
- [ ] OPS243-A GND (J3 Pin 1) → Pi GND (shared ground)

---

## One-Time Radar Setup

The OPS243-A must have rolling buffer mode saved to persistent memory for HOST_INT triggers to work. This is due to a firmware bug where the HOST_INT pin mode changes when transitioning modes at runtime.

```bash
# Configure and save rolling buffer mode to flash (one-time)
uv run python scripts/hardware-test/test_rolling_buffer_persist.py --setup

# Power cycle the radar (unplug USB, wait 3s, replug)

# Verify
uv run python scripts/hardware-test/test_rolling_buffer_persist.py --test
```

---

## Testing

### Quick Test: Visual

Make a loud sound near the SEN-14262. The onboard LED should flash briefly, then turn off. If the LED stays on constantly, you need a lower-value resistor in R17.

### Full Test: Software

```bash
uv run python scripts/hardware-test/test_sound_trigger_hardware.py
```

You should see:
```
Ready for hardware sound triggers!
Make a sound near the sensor... (Ctrl+C to quit)

[1] Waiting for hardware trigger (timeout=60s)...
  TRIGGER RECEIVED after 0.02s!
  I/Q samples: 4096 I, 4096 Q
```

---

## Troubleshooting

### GATE LED stays on (stuck high)

The preamp gain is too high for 3.3V operation.
- **Fix:** Solder a lower-value resistor into R17 (try 33kΩ instead of 47kΩ)

### No trigger received

1. Check the GATE LED flashes when you clap
2. Verify GND is shared between all three boards (Pi, SEN-14262, OPS243-A)
3. Verify HOST_INT is J3 **Pin 3** (not Pin 2)
4. Run `uv run python scripts/hardware-test/test_rolling_buffer_persist.py --test` to confirm radar is in rolling buffer mode

### Triggers constantly / too sensitive

- Use a lower-value R17 resistor to reduce gain
- Move the sensor further from the hitting area

### Triggers but no I/Q data

- Run the one-time radar setup (see above) — HOST_INT mode must be saved to flash
- Power cycle the radar after setup

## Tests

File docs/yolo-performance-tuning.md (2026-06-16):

# YOLO Detection Performance Tuning on Raspberry Pi

> **Note**: YOLO is optional. OpenFlight uses Hough circle detection by default, which requires no ML model and runs efficiently on Pi. Use YOLO via `--camera-model` only if you need higher detection accuracy.

This guide covers how to optimize YOLO golf ball detection for maximum FPS on Raspberry Pi 5.

## Camera in OpenFlight UI

The camera is enabled by default when running `start-kiosk.sh`. In the UI:
- **Header**: Ball detection indicator shows if a ball is detected (click to toggle camera)
- **Camera Tab**: View live feed with detection overlay

To customize the model used:
```bash
./scripts/start-kiosk.sh --camera-model models/golf_ball_yolo11n.onnx
```

## Quick Start (Best Balance)

For ~30 FPS with good detection quality:

```bash
# Export model to ONNX at 256px
python scripts/vision/test_yolo_detection.py \
  --model models/golf_ball_yolo11n.pt \
  --imgsz 256 \
  --export-onnx

# Run detection
DISPLAY=:0 python scripts/vision/test_yolo_detection.py \
  --model models/golf_ball_yolo11n.onnx \
  --imgsz 256 \
  --threaded
```

## Performance vs Quality Tradeoffs

| Input Size | Expected FPS | Detection Quality | Notes |
|---|---|---|---|
| 640 | ~12 | Best | Default, too slow for real-time |
| 320 | ~20 | Good | Solid detection |
| 288 | ~25 | Good | Good middle ground |
| 256 | ~30 | Good | Recommended balance |
| 224 | ~40 | Acceptable | Slight quality drop |
| 192 | ~50 | Reduced | Small objects harder to detect |

## Export Formats

### ONNX (Recommended)
Most stable and well-supported on Pi:

```bash
python scripts/vision/test_yolo_detection.py \
  --model models/golf_ball_yolo11n.pt \
  --imgsz <SIZE> \
  --export-onnx
```

### OpenVINO
Alternative runtime, supports INT8 quantization:

```bash
pip install openvino

python scripts/vision/test_yolo_detection.py \
  --model models/golf_ball_yolo11n.pt \
  --imgsz <SIZE> \
  --export-openvino
```

With INT8 quantization (faster but lower accuracy):
```bash
python scripts/vision/test_yolo_detection.py \
  --model models/golf_ball_yolo11n.pt \
  --imgsz <SIZE> \
  --export-openvino --int8
```

### NCNN
Theoretically fastest on ARM, but has stability issues (segfaults). Not recommended.

## Runtime Parameters

| Parameter | Description | Default |
|---|---|---|
| `--imgsz` | Inference input size (smaller = faster) | 640 |
| `--threaded` | Separate capture/inference threads | off |
| `--half` | FP16 half-precision (PyTorch only) | off |
| `--confidence` | Detection threshold (lower = more detections) | 0.3 |
| `--no-display` | Skip drawing overlays for benchmarking | off |
| `--fps` | Target camera FPS | 60 |
| `--buffer-count` | Camera buffer count (lower = less latency) | 2 |

## Example Commands

### Maximum FPS (reduced detection quality)
```bash
DISPLAY=:0 python scripts/vision/test_yolo_detection.py \
  --model models/golf_ball_yolo11n.onnx \
  --imgsz 192 \
  --threaded \
  --confidence 0.2
```

### Best detection (slower)
```bash
DISPLAY=:0 python scripts/vision/test_yolo_detection.py \
  --model models/golf_ball_yolo11n.onnx \
  --imgsz 320 \
  --threaded
```

### Headless benchmark
```bash
python scripts/vision/test_yolo_detection.py \
  --model models/golf_ball_yolo11n.onnx \
  --imgsz 256 \
  --threaded \
  --no-display
```

### Lower confidence for more detections
```bash
DISPLAY=:0 python scripts/vision/test_yolo_detection.py \
  --model models/golf_ball_yolo11n.onnx \
  --imgsz 224 \
  --threaded \
  --confidence 0.15
```

## Optimization Summary

1. **Use ONNX export** - More stable than NCNN on Pi
2. **Reduce input size** - Biggest performance gain (256 or 224 recommended)
3. **Use `--threaded`** - Separates capture from inference
4. **Match camera to inference size** - Reduces scaling overhead
5. **INT8 quantization** - Faster but hurts small object detection

## Hardware Upgrades for 60+ FPS

To exceed ~50 FPS on Pi, you'd need:
- Coral USB TPU Accelerator (~$60)
- Or switch to a simpler non-YOLO detection method

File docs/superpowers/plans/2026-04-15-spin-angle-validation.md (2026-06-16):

# Spin & Angle Data Quality Validation — Implementation Plan

> **For agentic workers:** REQUIRED SUB-SKILL: Use superpowers:subagent-driven-development (recommended) or superpowers:executing-plans to implement this plan task-by-task. Steps use checkbox (`- [ ]`) syntax for tracking.

**Goal:** Fix spin confidence over-reporting and missing angle validation so bad measurements don't reach the Shot object.

**Architecture:** Surgical changes inside existing detection code — `processor.py` for spin, `radc.py` + `tracker.py` for angles, `server.py` for horizontal plausibility. One new shared constant in `launch_monitor.py`. TDD for every behavioral change.

**Tech Stack:** Python, numpy, pytest

**Spec:** `docs/superpowers/specs/2026-04-15-spin-angle-validation-design.md`

---

### Task 1: Extract shared SPIN_CONFIDENCE_HIGH constant

**Files:**
- Modify: `src/openflight/launch_monitor.py:315`
- Modify: `src/openflight/rolling_buffer/processor.py:593-604`

- [ ] **Step 1: Add constant to launch_monitor.py**

In `src/openflight/launch_monitor.py`, add the constant after the imports (before `ClubType`), and use it in `spin_quality`:

```python
# Spin confidence threshold for "high" quality — used across modules.
# Measured spin is trusted for physics simulation only above this level.
SPIN_CONFIDENCE_HIGH = 0.7
```

Then update `spin_quality` (line 315) to use it:

```python
        if self.spin_confidence >= SPIN_CONFIDENCE_HIGH:
            return "high"
```

- [ ] **Step 2: Run existing tests to verify no regressions**

Run: `uv run pytest tests/test_rolling_buffer.py::TestSpinResult -v && uv run pytest tests/test_rolling_buffer.py::TestShotWithSpin -v`
Expected: All existing tests PASS (behavior unchanged — same threshold value)

- [ ] **Step 3: Import constant in processor.py**

In `src/openflight/rolling_buffer/processor.py`, add to imports:

```python
from ..launch_monitor import SPIN_CONFIDENCE_HIGH
```

No behavioral change yet — this just wires up the import for use in Task 2.

- [ ] **Step 4: Run tests to verify import works**

Run: `uv run pytest tests/test_rolling_buffer.py::TestSpinDetectionIntegration -v`
Expected: All PASS

- [ ] **Step 5: Commit**

```bash
git add src/openflight/launch_monitor.py src/openflight/rolling_buffer/processor.py
git commit -m "refactor: extract SPIN_CONFIDENCE_HIGH constant to launch_monitor"
```

---

### Task 2: Tighten spin confidence scoring + add hard RPM cap

**Files:**
- Modify: `src/openflight/rolling_buffer/processor.py:485-604`
- Test: `tests/test_rolling_buffer.py`

- [ ] **Step 1: Write failing test for hard RPM cap**

Add to `tests/test_rolling_buffer.py` at the end of the file:

```python
class TestSpinValidationGates:
    """Tests for spin detection validation: RPM ceiling, confidence tiers, modulation floor."""

    def _make_iq_with_seam_modulation(
        self,
        base_speed_mph: float,
        spin_rpm: float,
        modulation_depth: float = 0.03,
        sample_rate: int = 30000,
        num_samples: int = 4096,
    ):
        """Generate synthetic I/Q with amplitude modulation at 1x spin rate."""
        wavelength = 0.01243
        speed_mps = base_speed_mph / 2.23694
        doppler_hz = 2 * speed_mps / wavelength
        seam_hz = spin_rpm / 60.0
        t = np.arange(num_samples) / sample_rate
        phase = 2 * np.pi * doppler_hz * t
        amplitude = 200 * (1.0 + modulation_depth * np.sin(2 * np.pi * seam_hz * t))
        i_samples = (amplitude * np.cos(phase) + 2048).astype(int).clip(0, 4095).tolist()
        q_samples = (amplitude * np.sin(phase) + 2048).astype(int).clip(0, 4095).tolist()
        return i_samples, q_samples

    def test_rpm_above_12000_rejected(self):
        """Spin above SPIN_MAX_SEAM_HZ * 60 (12000 RPM) must be rejected."""
        processor = RollingBufferProcessor()
        # Create I/Q with 13000 RPM modulation — above the physical cap.
        # Call detect_spin directly so we can specify the exact ball timestamp.
        i_samples, q_samples = self._make_iq_with_seam_modulation(
            base_speed_mph=100, spin_rpm=13000, modulation_depth=0.05,
        )
        capture = IQCapture(
            sample_time=0.0, trigger_time=0.068,
            i_samples=i_samples, q_samples=q_samples,
        )
        result = processor.detect_spin(capture, ball_speed_mph=100, ball_timestamp_ms=5.0)
        assert result.spin_rpm == 0, (
            f"13000 RPM should be rejected, got {result.spin_rpm} RPM"
        )
```

- [ ] **Step 2: Run test to verify it fails**

Run: `uv run pytest tests/test_rolling_buffer.py::TestSpinValidationGates::test_rpm_above_12000_rejected -v`
Expected: FAIL — 13000 RPM is above SPIN_MAX_SEAM_HZ (200 Hz) so the FFT mask should already reject it, but this test confirms the safety net. If it passes already (FFT mask catches it), that's fine — the hard cap is still needed for the autocorrelation override path.

- [ ] **Step 3: Write failing test for tightened confidence — bare SNR without cycles**

Add to `TestSpinValidationGates`:

```python
    def test_medium_snr_low_cycles_gets_reduced_confidence(self):
        """SNR >= 5 but < 3 seam cycles should score 0.5, not 0.7.

        With a short ball window (few cycles), the FFT peak is unreliable
        even with decent SNR — this is the repeated-bin pattern.
        """
        processor = RollingBufferProcessor()
        # Use 700 samples (~23ms) at 4000 RPM = 66.7 Hz → ~1.5 seam cycles.
        # Short window means few cycles, but SNR can still be decent.
        i_samples, q_samples = self._make_iq_with_seam_modulation(
            base_speed_mph=130, spin_rpm=4000, modulation_depth=0.04,
            num_samples=700,
        )
        capture = IQCapture(
            sample_time=0.0, trigger_time=0.003,
            i_samples=i_samples, q_samples=q_samples,
        )
        result = processor.detect_spin(capture, ball_speed_mph=130, ball_timestamp_ms=1.0)
        # If spin is detected at all, confidence should be <= 0.5
        if result.spin_rpm > 0:
            assert result.confidence <= 0.5, (
                f"Low-cycle detection should cap at 0.5, got {result.confidence}"
            )
```

- [ ] **Step 4: Run test to verify it fails**

Run: `uv run pytest tests/test_rolling_buffer.py::TestSpinValidationGates::test_medium_snr_low_cycles_gets_reduced_confidence -v`
Expected: FAIL (current code gives 0.7 for bare `SNR >= 5.0`)

- [ ] **Step 5: Write failing test for modulation depth confidence cap**

Add to `TestSpinValidationGates`:

```python
    def test_weak_modulation_caps_confidence(self):
        """Modulation depth < 1% should cap confidence at 0.5 max."""
        processor = RollingBufferProcessor()
        # 0.008 modulation depth — above the 0.005 rejection floor but below 1%.
        i_samples, q_samples = self._make_iq_with_seam_modulation(
            base_speed_mph=130, spin_rpm=5000, modulation_depth=0.008,
        )
        capture = IQCapture(
            sample_time=0.0, trigger_time=0.068,
            i_samples=i_samples, q_samples=q_samples,
        )
        result = processor.detect_spin(capture, ball_speed_mph=130, ball_timestamp_ms=5.0)
        if result.spin_rpm > 0:
            assert result.confidence <= 0.5, (
                f"Weak modulation should cap at 0.5, got {result.confidence}"
            )
```

- [ ] **Step 6: Run test to verify it fails**

Run: `uv run pytest tests/test_rolling_buffer.py::TestSpinValidationGates::test_weak_modulation_caps_confidence -v`
Expected: FAIL (current code doesn't cap confidence based on modulation depth)

- [ ] **Step 7: Write test that good spin still scores high**

Add to `TestSpinValidationGates`:

```python
    def test_strong_spin_still_scores_high(self):
        """Clean spin with good SNR and many cycles should still score 0.9."""
        processor = RollingBufferProcessor()
        i_samples, q_samples = self._make_iq_with_seam_modulation(
            base_speed_mph=120, spin_rpm=7000, modulation_depth=0.03,
        )
        capture = IQCapture(
            sample_time=0.0, trigger_time=0.068,
            i_samples=i_samples, q_samples=q_samples,
        )
        result = processor.detect_spin(capture, ball_speed_mph=120, ball_timestamp_ms=5.0)
        assert result.spin_rpm > 0, f"Should detect spin, got quality={result.quality}"
        assert result.confidence >= 0.8, (
            f"Strong spin should score >= 0.8, got {result.confidence}"
        )
```

- [ ] **Step 8: Run to verify it passes (existing behavior should handle this)**

Run: `uv run pytest tests/test_rolling_buffer.py::TestSpinValidationGates::test_strong_spin_still_scores_high -v`
Expected: PASS (7000 RPM at 120 mph with 3% modulation should produce high SNR and many cycles)

- [ ] **Step 9: Implement all three spin validation changes in processor.py**

In `src/openflight/rolling_buffer/processor.py`, make three changes:

**Change A — Modulation depth flag (after line 494):**

Replace:

```python
        # Remove DC and apply Hann window
        ball_envelope -= envelope_mean
```

With:

```python
        # Flag weak modulation — above the noise floor (0.5%) but below
        # the level where we trust the envelope FFT peak (1%). Caps
        # confidence later to prevent marginal signals scoring 0.7+.
        weak_modulation = modulation_depth < 0.01

        # Remove DC and apply Hann window
        ball_envelope -= envelope_mean
```

**Change B — Hard RPM cap (after line 531, before the cycles check):**

After the line `spin_rpm = peak_freq * 60`, add:

```python
        # Hard ceiling — reject anything above physical maximum.
        # The FFT mask should enforce this, but the autocorrelation override
        # path can bypass it. Belt-and-suspenders.
        max_rpm = self.SPIN_MAX_SEAM_HZ * 60
        if spin_rpm > max_rpm:
            return SpinResult.no_spin_detected(
                f"Spin {spin_rpm:.0f} RPM exceeds physical maximum ({max_rpm:.0f})"
            )
```

**Change C — New confidence tiers (replace lines 593-604):**

Replace:

```python
        if fft_snr >= self.SPIN_SNR_HIGH and seam_cycles >= 5:
            quality = "high"
            confidence = 0.9
        elif fft_snr >= self.SPIN_SNR_MEDIUM or autocorr_confirmed:
            quality = "medium"
            confidence = 0.7
        elif fft_snr >= self.SPIN_SNR_MIN:
            quality = "low"
            confidence = 0.4
        else:
            quality = "low"
            confidence = 0.3
```

With:

```python
        if fft_snr >= self.SPIN_SNR_HIGH and seam_cycles >= 5:
            quality = "high"
            confidence = 0.9
        elif fft_snr >= self.SPIN_SNR_HIGH and seam_cycles >= 3:
            quality = "high"
            confidence = 0.8
        elif fft_snr >= self.SPIN_SNR_MEDIUM and (seam_cycles >= 3 or autocorr_confirmed):
            quality = "medium"
            confidence = SPIN_CONFIDENCE_HIGH
        elif fft_snr >= self.SPIN_SNR_MEDIUM or autocorr_confirmed:
            quality = "low"
            confidence = 0.5
        elif fft_snr >= self.SPIN_SNR_MIN:
            quality = "low"
            confidence = 0.3
        else:
            quality = "low"
            confidence = 0.3

        # Weak modulation caps confidence — the envelope FFT peak may be
        # noise rather than real seam modulation.
        if weak_modulation:
            confidence = min(confidence, 0.5)
            if quality == "high":
                quality = "medium"
```

- [ ] **Step 10: Run all spin tests**

Run: `uv run pytest tests/test_rolling_buffer.py::TestSpinValidationGates -v && uv run pytest tests/test_rolling_buffer.py::TestSpinDetectionIntegration -v`
Expected: All new tests PASS, all existing spin tests PASS

- [ ] **Step 11: Commit**

```bash
git add src/openflight/rolling_buffer/processor.py tests/test_rolling_buffer.py
git commit -m "fix: tighten spin confidence scoring and add hard RPM ceiling"
```

---

### Task 3: Add hard angle bounds in radc.py

**Files:**
- Modify: `src/openflight/kld7/radc.py:276-285, 443-445`
- Modify: `src/openflight/kld7/tracker.py:321-327`
- Test: `tests/test_kld7_radc_lib.py`

- [ ] **Step 1: Write failing test for vertical angle bounds**

Add to `tests/test_kld7_radc_lib.py`:

```python
from openflight.kld7.radc import extract_launch_angle

class TestAngleBoundsValidation:
    """Tests for hard angle bounds rejection in extract_launch_angle."""

    def _make_single_frame_with_angle(self, angle_deg: float, snr: float = 10.0):
        """Create a minimal synthetic RADC frame that produces a known angle.

        Rather than constructing raw I/Q that produces a specific angle through
        the full pipeline (fragile), we test the bounds check by calling
        extract_launch_angle with crafted frames and verifying the result
        is filtered. This relies on the integration tests in test_kld7.py
        for end-to-end coverage.
        """
        # Build a synthetic 3072-byte RADC payload with a known phase offset
        # between F1A and F2A that produces the desired angle.
        # angle = arcsin(dphi * lambda / (2 * pi * d))
        # dphi = arcsin(angle_deg * pi / 180) * 2 * pi * d / lambda
        import math
        wavelength = 0.01243
        spacing = 0.008
        dphi = math.asin(max(-1, min(1, math.sin(math.radians(angle_deg))))) * 2 * math.pi * spacing / wavelength

        # Create payload: F1A and F2A with a phase offset that produces dphi
        # at a specific FFT bin. We put energy in bin 50 (a mid-range velocity).
        n = 256
        t = np.arange(n, dtype=np.float64)
        freq_bin = 50
        f = freq_bin / n  # normalized frequency

        # F1A: reference channel
        f1a_i = (100 * np.cos(2 * np.pi * f * t) + 2048).astype(np.uint16)
        f1a_q = (100 * np.sin(2 * np.pi * f * t) + 2048).astype(np.uint16)
        # F2A: phase-shifted channel
        f2a_i = (100 * np.cos(2 * np.pi * f * t + dphi) + 2048).astype(np.uint16)
        f2a_q = (100 * np.sin(2 * np.pi * f * t + dphi) + 2048).astype(np.uint16)
        # F1B: unused, zero
        f1b_i = np.full(n, 2048, dtype=np.uint16)
        f1b_q = np.full(n, 2048, dtype=np.uint16)

        payload = b"".join(ch.tobytes() for ch in [f1a_i, f1a_q, f2a_i, f2a_q, f1b_i, f1b_q])
        return {"timestamp": 0.0, "radc": payload}

    def test_vertical_angle_above_45_rejected(self):
        """Vertical angles above 45° should be filtered out."""
        frame = self._make_single_frame_with_angle(50.0)
        results = extract_launch_angle(
            [frame] * 5,
            ops243_ball_speed_mph=100.0,
            orientation="vertical",
        )
        for r in results:
            assert r["launch_angle_deg"] <= 45.0, (
                f"Vertical angle {r['launch_angle_deg']}° should be rejected (>45°)"
            )

    def test_vertical_angle_below_0_rejected(self):
        """Negative vertical angles should be filtered out."""
        frame = self._make_single_frame_with_angle(-5.0)
        results = extract_launch_angle(
            [frame] * 5,
            ops243_ball_speed_mph=100.0,
            orientation="vertical",
        )
        for r in results:
            assert r["launch_angle_deg"] >= 0.0, (
                f"Vertical angle {r['launch_angle_deg']}° should be rejected (<0°)"
            )

    def test_horizontal_angle_beyond_15_rejected(self):
        """Horizontal angles beyond ±15° should be filtered out."""
        frame = self._make_single_frame_with_angle(20.0)
        results = extract_launch_angle(
            [frame] * 5,
            ops243_ball_speed_mph=100.0,
            orientation="horizontal",
        )
        for r in results:
            assert abs(r["launch_angle_deg"]) <= 15.0, (
                f"Horizontal angle {r['launch_angle_deg']}° should be rejected (>±15°)"
            )

    def test_valid_vertical_angle_passes(self):
        """A valid 12° vertical angle should pass through."""
        frame = self._make_single_frame_with_angle(12.0)
        results = extract_launch_angle(
            [frame] * 5,
            ops243_ball_speed_mph=100.0,
            orientation="vertical",
        )
        # Result may be empty if synthetic frame doesn't produce enough SNR,
        # but if present, the angle should be close to 12°.
        # This test verifies valid angles aren't rejected by the bounds check.
        for r in results:
            assert 0.0 <= r["launch_angle_deg"] <= 45.0

    def test_orientation_defaults_to_no_filtering(self):
        """When orientation is not specified, no angle bounds are applied (backward compat)."""
        frame = self._make_single_frame_with_angle(50.0)
        # No orientation parameter — should not crash or filter
        results = extract_launch_angle(
            [frame] * 5,
            ops243_ball_speed_mph=100.0,
        )
        # Just verify it doesn't raise — bounds filtering is opt-in via orientation
```

- [ ] **Step 2: Run tests to verify they fail**

Run: `uv run pytest tests/test_kld7_radc_lib.py::TestAngleBoundsValidation -v`
Expected: FAIL — `extract_launch_angle` doesn't accept an `orientation` parameter yet

- [ ] **Step 3: Add orientation parameter and bounds check to extract_launch_angle**

In `src/openflight/kld7/radc.py`, modify the function signature (line 276):

Replace:

```python
def extract_launch_angle(
    frames: list[dict],
    fft_size: int = 2048,
    max_speed_kmh: float = 100.0,
    cfar_threshold: float = 2.5,
    impact_energy_threshold: float = 3.0,
    angle_offset_deg: float = 0.0,
    ops243_ball_speed_mph: float | None = None,
    speed_tolerance_mph: float = 10.0,
) -> list[dict]:
```

With:

```python
def extract_launch_angle(
    frames: list[dict],
    fft_size: int = 2048,
    max_speed_kmh: float = 100.0,
    cfar_threshold: float = 2.5,
    impact_energy_threshold: float = 3.0,
    angle_offset_deg: float = 0.0,
    ops243_ball_speed_mph: float | None = None,
    speed_tolerance_mph: float = 10.0,
    orientation: str | None = None,
) -> list[dict]:
```

Then, inside the function, after `corrected_angle` is computed (after line 422) and before `avg_speed_mph` (line 424), add the bounds check:

Replace:

```python
        corrected_angle = weighted_angle + angle_offset_deg

        avg_speed_mph = float(np.mean(peak_speeds_mph))
```

With:

```python
        corrected_angle = weighted_angle + angle_offset_deg

        # Hard physical bounds — reject obvious outliers before they
        # reach the Shot object. Orientation-aware: vertical [0°, 45°],
        # horizontal [-15°, +15°]. When orientation is None (offline
        # analysis), skip bounds filtering.
        if orientation == "vertical" and not (0.0 <= corrected_angle <= 45.0):
            logger.info(
                "[RADC] Vertical angle %.1f° outside [0, 45] — rejected",
                corrected_angle,
            )
            continue
        if orientation == "horizontal" and abs(corrected_angle) > 15.0:
            logger.info(
                "[RADC] Horizontal angle %.1f° outside ±15° — rejected",
                corrected_angle,
            )
            continue

        avg_speed_mph = float(np.mean(peak_speeds_mph))
```

Also add `import logging` and `logger = logging.getLogger(__name__)` at the top of `radc.py` if not already present.

- [ ] **Step 4: Pass orientation from tracker.py**

In `src/openflight/kld7/tracker.py`, update `_extract_ball_radc()` (line 321):

Replace:

```python
        results = extract_launch_angle(
            frames,
            ops243_ball_speed_mph=ball_speed_mph,
            angle_offset_deg=self.angle_offset_deg,
            speed_tolerance_mph=10.0,
            impact_energy_threshold=energy_threshold,
        )
```

With:

```python
        results = extract_launch_angle(
            frames,
            ops243_ball_speed_mph=ball_speed_mph,
            angle_offset_deg=self.angle_offset_deg,
            speed_tolerance_mph=10.0,
            impact_energy_threshold=energy_threshold,
            orientation=self.orientation,
        )
```

- [ ] **Step 5: Run angle bounds tests and existing K-LD7 tests**

Run: `uv run pytest tests/test_kld7_radc_lib.py::TestAngleBoundsValidation -v && uv run pytest tests/test_kld7_radc_lib.py -v`
Expected: All PASS

- [ ] **Step 6: Commit**

```bash
git add src/openflight/kld7/radc.py src/openflight/kld7/tracker.py tests/test_kld7_radc_lib.py
git commit -m "fix: add hard angle bounds to K-LD7 extraction (V[0,45] H[±15])"
```

---

### Task 4: Add horizontal angle plausibility check in server.py

**Files:**
- Modify: `src/openflight/server.py:997-1002`
- Test: `tests/test_rolling_buffer.py` (server-level test)

- [ ] **Step 1: Write failing test for horizontal rejection**

Add to `tests/test_rolling_buffer.py`:

```python
class TestHorizontalAnglePlausibility:
    """Tests for server-level horizontal angle rejection."""

    def test_extreme_horizontal_angle_rejected(self):
        """Horizontal angles beyond ±15° should not reach the Shot."""
        # This tests the contract: any KLD7Angle with |horizontal_deg| > 15
        # should be rejected before assignment to shot.launch_angle_horizontal.
        # We test the logic directly rather than spinning up the server.
        h_angle = 34.0  # The exact value from the bad session
        assert abs(h_angle) > 15.0, "Test setup: angle should be out of bounds"

    def test_valid_horizontal_angle_accepted(self):
        """Horizontal angles within ±15° should be accepted."""
        h_angle = -3.3
        assert abs(h_angle) <= 15.0, "Test setup: angle should be in bounds"
```

Note: These are contract/sanity tests. The real integration test requires the full server, which we can't run in CI without hardware. The bounds check in `radc.py` (Task 3) is the primary gate; this server-level check is the backstop.

- [ ] **Step 2: Add horizontal plausibility check in server.py**

In `src/openflight/server.py`, replace lines 997-1002:

Replace:

```python
                if kld7_angle_h and kld7_angle_h.horizontal_deg is not None:
                    shot.launch_angle_horizontal = kld7_angle_h.horizontal_deg
                    if shot.angle_source is None:
                        shot.angle_source = "radar"
                    if shot.launch_angle_confidence is None:
                        shot.launch_angle_confidence = kld7_angle_h.confidence
```

With:

```python
                if kld7_angle_h and kld7_angle_h.horizontal_deg is not None:
                    if abs(kld7_angle_h.horizontal_deg) <= 15.0:
                        shot.launch_angle_horizontal = kld7_angle_h.horizontal_deg
                        if shot.angle_source is None:
                            shot.angle_source = "radar"
                        if shot.launch_angle_confidence is None:
                            shot.launch_angle_confidence = kld7_angle_h.confidence
                    else:
                        logger.warning(
                            "[SERVER] Horizontal angle %.1f° rejected: exceeds ±15°",
                            kld7_angle_h.horizontal_deg,
                        )
```

- [ ] **Step 3: Run tests**

Run: `uv run pytest tests/test_rolling_buffer.py::TestHorizontalAnglePlausibility -v`
Expected: PASS

- [ ] **Step 4: Run full test suite to check for regressions**

Run: `uv run pytest tests/ -v --timeout=60`
Expected: All tests PASS

- [ ] **Step 5: Commit**

```bash
git add src/openflight/server.py tests/test_rolling_buffer.py
git commit -m "fix: add horizontal angle plausibility check (±15° max)"
```

---
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

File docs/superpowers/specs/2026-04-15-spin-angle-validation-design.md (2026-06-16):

# Spin & Angle Data Quality Validation

**Date:** 2026-04-15
**Status:** Approved
**Scope:** Tighten spin confidence scoring, add hard RPM ceiling, add angle bounds, fix missing horizontal plausibility check

## Problem

Session `session_20260415_123037_range.jsonl` (6 shots) revealed three data quality issues:

1. **Repeated spin values**: 4/6 shots returned exactly 2637 RPM (FFT bin 12 of the 8192-point envelope FFT). These are not real spin measurements — the detector is locking onto the same low-frequency spectral feature. All received `spin_confidence >= 0.7`, meaning the ballistics module's fallback policy treats them as trustworthy.
2. **Impossible spin value**: Shot 3 returned 20,455 RPM (340.9 Hz) despite `SPIN_MAX_SEAM_HZ = 200.0`. This exceeds the physical maximum for any golf ball. It got `spin_confidence = 0.7`.
3. **Bad launch angles**: Shot 4 had `launch_angle_horizontal = -34.0` (physically impossible). Shot 3 had `launch_angle_vertical = 31.2` at 101 mph ball speed (implausible for that speed). The horizontal angle path in `server.py` has no plausibility check — angles are accepted unconditionally.

## Approach

Fix at the source: add validation inside the existing detection code (`processor.py` for spin, `radc.py` for angles) rather than a separate validation layer. Each shot is evaluated independently (no cross-shot state).

## Changes

### 1. Spin: Hard RPM ceiling (processor.py)

Add a final safety-net check in `detect_spin()` before returning `SpinResult`:

```python
if spin_rpm > SPIN_MAX_SEAM_HZ * 60:  # 12000 RPM
    return SpinResult.no_spin_detected("Spin exceeds physical maximum")
```

This catches any code path that bypasses the FFT frequency mask, including the autocorrelation override (lines 573-576) which sets `spin_rpm = acorr_rpm` without rechecking bounds.

### 2. Spin: Tighten confidence scoring (processor.py)

Current scoring (lines 593-604) gives `confidence = 0.7` for `SNR >= 5.0 OR autocorr_confirmed`. This is too generous — 0.7 is the ballistics module's "high" threshold for trusting measured spin.

New scoring matrix:

| Condition | Confidence |
|---|---|
| `SNR >= 8.0` AND `seam_cycles >= 5` | 0.9 |
| `SNR >= 8.0` AND `seam_cycles >= 3` | 0.8 |
| `SNR >= 5.0` AND (`seam_cycles >= 3` OR `autocorr_confirmed`) | 0.7 |
| `SNR >= 5.0` OR `autocorr_confirmed` | 0.5 |
| `SNR >= 3.0` | 0.3 |

Key change: 0.7 now requires **both** decent SNR **and** either enough seam cycles or autocorrelation confirmation. Bare `SNR >= 5.0` without cycle validation drops to 0.5 — below the ballistics "high" threshold. This directly targets the 2637 RPM shots that were getting 0.7 on thin evidence.

### 3. Spin: Modulation depth confidence floor (processor.py)

After the existing modulation depth check (line ~494), add a confidence cap: if `modulation_depth < 0.01` (1%), limit the maximum confidence to 0.5 regardless of SNR. Real spin modulation is 1-5%; below 1% we're likely seeing noise with a coincidental spectral peak.

Implementation: set a flag (e.g., `weak_modulation = modulation_depth < 0.01`) and apply `confidence = min(confidence, 0.5)` before returning.

### 4. Spin: Shared confidence constant (launch_monitor.py)

Extract `SPIN_CONFIDENCE_HIGH = 0.7` into `launch_monitor.py` and import it in:
- `processor.py` (for quality label assignment)
- `ballistics.py` (pending PR #61, currently duplicates the threshold)

### 5. Angles: Hard bounds in extract_launch_angle() (radc.py)

Before appending to `results` (after line 422), reject angles outside physical limits:

- Vertical: reject if `corrected_angle < 0.0` or `corrected_angle > 45.0`
- Horizontal: reject if `abs(corrected_angle) > 15.0`

Requires threading `orientation` ("vertical" or "horizontal") from `KLD7Tracker` through `_extract_ball_radc()` into `extract_launch_angle()`. The tracker already knows its orientation.

### 6. Angles: Horizontal plausibility check (server.py)

Add a guard at lines 997-1002 for horizontal angles, matching the pattern used for vertical:

```python
if kld7_angle_h and kld7_angle_h.horizontal_deg is not None:
    if abs(kld7_angle_h.horizontal_deg) <= 15.0:
        shot.launch_angle_horizontal = kld7_angle_h.horizontal_deg
        ...
    else:
        logger.warning(...)
```

Simpler than the vertical guard — no club-based estimate needed since horizontal aim offset doesn't vary by club.

## Tests

### Spin validation tests
- `detect_spin()` returns `no_spin_detected` when peak frequency exceeds `SPIN_MAX_SEAM_HZ`
- `SNR=6.0, seam_cycles=2` now scores 0.5 (was 0.7)
- `SNR=6.0, seam_cycles=4, autocorr_confirmed=True` scores 0.7
- Modulation depth < 1% caps confidence at 0.5
- `SPIN_CONFIDENCE_HIGH` constant is used consistently across modules

### Angle validation tests
- `extract_launch_angle()` rejects vertical angles outside [0, 45]
- `extract_launch_angle()` rejects horizontal angles outside [-15, +15]
- Borderline-valid angles (44.9 vertical, 14.9 horizontal) pass through
- Server-level horizontal plausibility rejection works

All tests are unit tests on detection functions — no hardware or I/Q fixtures needed. Mock FFT output / peak values to exercise the validation gates.

## Files Modified

| File | Changes |
|---|---|
| `src/openflight/rolling_buffer/processor.py` | Hard RPM cap, confidence rescoring, modulation depth floor |
| `src/openflight/launch_monitor.py` | Extract `SPIN_CONFIDENCE_HIGH` constant |
| `src/openflight/kld7/radc.py` | Hard angle bounds, accept `orientation` parameter |
| `src/openflight/kld7/tracker.py` | Pass `orientation` through to `extract_launch_angle()` |
| `src/openflight/server.py` | Horizontal angle plausibility check |
| `tests/test_rolling_buffer.py` (or new file) | Spin validation tests |
| `tests/test_kld7_radc.py` (or new file) | Angle validation tests |

## Out of Scope

- Trigger latency investigation (17-28s latencies — separate debugging session)
- Cross-shot spin tracking / repeated-bin detection
- Per-club adaptive angle bounds
- Changes to the ballistics PR (#61) beyond importing the shared constant

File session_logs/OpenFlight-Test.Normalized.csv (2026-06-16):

sep=
Date | TMD No | TMD Filename | Player | Club | Ball | Club Speed | Attack Angle | Club Path | Low Point | Swing Plane | Swing Direction | Dyn. Loft | Face Angle | Face To Path | Ball Speed | Smash Factor | Launch Angle | Launch Direction | Spin Rate | Spin Rate Type | Spin Axis | Max Height - Dist. | Max Height - Height | Max Height - Side | Last data Point - Length | Last data Point - Side | Last data Point - Height | Last data Point - Time | Carry Flat - Length | Carry Flat - Side | Carry Flat - Land. Angle | Carry Flat - Ball Speed | Carry Flat - Time | Est. Total Flat - Length | Est. Total Flat - Side | Dynamic Lie | Impact Offset | Impact Height | Curve | Spin Axis (Sim) | Curve (Sim) | Carry (Sim) | Total (Sim) | Carry Side (Sim) | Total side (Sim) | Landing Angle (Sim) | Spin Loft | Swing Radius | Low Point Height | Low Point Side | D Plane Tilt | Ball Speed Diff | Smash Index | Spin Rate Diff | Spin Index | Gyro Angle | Use In Stat | Tags | Condition
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

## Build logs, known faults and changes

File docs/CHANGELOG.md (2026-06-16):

# Changelog

All notable changes to this project will be documented in this file.

The format is based on [Keep a Changelog](https://keepachangelog.com/en/1.1.0/),
and this project adheres to [Semantic Versioning](https://semver.org/spec/v2.0.0.html).

## [Unreleased]

### Changed
- Spin detection: drop the autocorrelation override branch. The autocorr
  peak inside the envelope search region often lands at minimum lag
  (~12000 RPM / upper rail) by spectral coincidence, which previously
  flipped legitimate mid-range FFT seam picks to the upper rail and got
  them rejected as bandpass-shoulder noise. The autocorr fallback still
  *confirms* the FFT pick when the two agree within 10%; disagreements
  are now logged for diagnostics but never replace the FFT result.
- Spin detection: lower `SPIN_SNR_MIN` from 3.0 → 2.5 so marginal but
  real seam tones are reported at low confidence instead of dropped.

### Added
- `scripts/launch-kiosk-local.sh` — Pi-local kiosk launcher with display auto-detection (Wayland/X11), `--camera` (mock radar + real camera), `--live`, `--stop` flags, and PID tracking
- DTL (down-the-line) swing camera recording module with ring buffer and shot-triggered clip saving
- `--dtl-camera` flag to enable DTL recording, with `--dtl-pre`, `--dtl-post`, `--dtl-resolution`, `--dtl-fps` options
- WebSocket events for DTL camera status (`dtl_camera_status`, `dtl_clip_saved`)
- Session logging for DTL clips (`dtl_clip` entry type)
- Mock DTL recorder for testing without hardware
- `scripts/analysis/replay_club_speed.py`: offline replay of a proposed
  MEDIAN club-speed picker against any session log. Builds the same
  candidate set the production picker uses, applies a 30 % magnitude
  floor, and reports the median speed for each `rolling_buffer_capture`
  alongside the originally logged (magnitude-pick) value, with smash
  factors as a physical sanity check. The script is exploratory and
  does not change production behaviour — it lets us inspect what a
  median-based picker would have produced before committing to a code
  change.
- `scripts/analysis/plot_spin_debug.py`: 4-panel diagnostic for a single
  `rolling_buffer_capture` (speed timeline, raw I/Q, bandpass envelope,
  envelope FFT spectrum) to inspect what the spin algorithm saw and why
  it accepted or rejected a shot.
- K-LD7 shot-correlation analysis workflow and theory writeup
  - `scripts/analyze_kld7.py --pair-shots` for offline club-to-ball pairing on `.pkl` captures
  - `docs/kld7-ball-detection-theory.md` with capture findings and detection rationale
- K-LD7 session-review workflow for full JSONL logs
  - `scripts/review_kld7_session.py` for per-shot profile review on `session_logs/session_*.jsonl`
  - `docs/kld7-session-review.md` documenting the empirical review method and outputs
- Persistent rolling buffer mode workaround for OPS243-A HOST_INT pin bug (per OmniPreSense)
  - `persist_rolling_buffer_mode()` method saves settings to flash memory
  - `test_rolling_buffer_persist.py` script for one-time radar setup and verification
  - Rolling buffer + sound trigger is now the default operating mode
- Grafana Alloy integration for shipping session logs to Grafana Cloud Loki
  - Setup script (`scripts/setup_alloy.sh`) and config (`config/alloy.alloy`)
  - Auto-starts with `start-kiosk.sh` when credentials are configured
  - Observability documentation with LogQL query examples
- Launch angle estimation from club type and ball speed (fallback when camera unavailable)
- Tunable Hough circle detection with all 5 parameters as CLI args (`--hough-param1`, `--hough-param2`, `--hough-min-radius`, `--hough-max-radius`, `--hough-min-dist`)
- Interactive `--tune` mode in `test_launch_angle.py` with live OpenCV trackbar sliders
- Mock mode now simulates realistic spin and launch angle data (TrackMan-based per-club averages)
- Sound trigger wiring guide with MOSFET circuit design (`docs/sound-trigger-wiring.md`)
- Camera integration with real-time ball detection in UI
- Ball detection indicator in header (shows detection status)
- Camera tab with live MJPEG stream and detection overlay
- Hough circle transform as default ball detector (replaces YOLO dependency)
- ByteTrack object tracking for persistent ball identification
- Club speed detection and smash factor calculation
- Rolling buffer mode for experimental spin rate detection
- Session logging to JSONL files (`~/openflight_sessions/`)
- I/Q streaming mode with FFT and 2D CFAR noise rejection
- `--mode rolling-buffer` flag for spin detection
- `--session-location` and `--log-dir` flags for session logging
- Roboflow API integration as optional detection backend
- YOLO performance tuning documentation for Raspberry Pi
- ONNX model export support for faster inference
- Threaded camera capture for improved FPS
- Rolling buffer spin detection documentation

### Changed
- K-LD7 launch-angle processing now uses OPS243 impact timestamps for live correlation
- K-LD7 ball-burst selection now prefers coherent far-target paths instead of averaging all far PDAT detections
- Live K-LD7 vertical launch angles now fall back to the existing club-and-speed estimate when the radar result is an obvious false positive
- Spin detection improved: Hann windowing, zero-padding to 256 points, band-limited search
- All shot metrics (spin, launch angle, club speed, carry) always shown in UI
- Shot logging unified — all metrics in single `shot_detected` entry
- Shot `mode` and `readings_data` are now proper dataclass fields (no more monkey-patching)
- Session logging enabled in mock mode for testing Alloy integration
- Default ball detection uses Hough circles instead of YOLO (no ML model required)
- Camera enabled by default in kiosk mode (use `--no-camera` to disable)
- Dropped Python 3.9 support (requires >=3.10)
- Updated Raspberry Pi setup guide with camera UI and observability instructions

## [0.2.0] - 2024-12-01

### Added
- Web UI with React frontend and Flask-SocketIO backend
- Real-time shot display with ball speed, carry distance, smash factor
- Session statistics view with per-club filtering
- Shot history with pagination
- Debug panel for radar tuning and raw readings
- Mock mode for development without hardware
- Kiosk mode script for Raspberry Pi deployment
- Systemd service for auto-start on boot
- Camera module for launch angle detection (experimental)
- Camera-based ball tracking for launch angle
- Club type selection (Driver through PW)

### Changed
- Migrated from CDM324/HB100 radar to OPS243-A
- Improved carry distance estimation model

## [0.1.0] - 2024-10-01

### Added
- Initial OPS243-A radar driver
- Basic launch monitor with shot detection
- CLI interface for monitoring shots
- Python API for integration
- Carry distance estimation based on ball speed

[Unreleased]: https://github.com/jewbetcha/openflight/compare/v0.2.0...HEAD
[0.2.0]: https://github.com/jewbetcha/openflight/compare/v0.1.0...v0.2.0
[0.1.0]: https://github.com/jewbetcha/openflight/releases/tag/v0.1.0

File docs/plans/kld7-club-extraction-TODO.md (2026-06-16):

# TODO: K-LD7 RADC Club Head Extraction

**Status:** Not started
**Priority:** High — needed for club path and angle of attack

## What We Need

Two measurements from the K-LD7 RADC data that we currently don't extract:

### 1. Club Path (horizontal K-LD7)
The horizontal angle of the club head at impact. Combined with the ball's aim direction (which we already measure), this gives the club path relative to target — a key metric for understanding shot shape (draw/fade/push/pull).

### 2. Angle of Attack (vertical K-LD7)
The vertical angle of the club head at impact. This tells you whether the club is ascending or descending at impact — critical for driver optimization (hitting up) vs iron play (hitting down).

## Approach

Same pipeline as ball extraction — the OPS243 already returns `club_speed_mph` on each shot. Use it exactly like we use `ball_speed_mph`:

1. OPS club speed → compute aliased velocity bin via `ball_bin_range_from_speed(club_speed_mph)`
2. Search RADC frames for energy at that bin (same `find_impact_frames` + CFAR)
3. Phase interferometry at the club's velocity bin gives the angle

The main difference is timing — the club appears **before** the ball in the RADC buffer (club swing → impact → ball launch). The existing `extract_launch_angle` function may already find it if we pass `club_speed_mph` instead of `ball_speed_mph`. It might be as simple as calling the same function twice with different speeds.

## Key Differences from Ball Extraction

| | Ball | Club |
|--|---|---|
| Speed | From OPS243 directly | Estimated from OPS or smash factor |
| Timing | After impact (ball in flight) | Before impact (downswing) |
| Distance | 3-5m (far range) | 1-2m (close range) |
| RCS | Small (golf ball) | Large (club head) |
| Duration in beam | 1-2 frames | 1-2 frames |
| Velocity aliasing | Yes (>62 mph) | Sometimes (>62 mph club speed) |

## Files to Modify

- `src/openflight/kld7/radc.py` — add `extract_club_angle()` function
- `src/openflight/kld7/tracker.py` — add `_extract_club_radc()` method, wire into shot processing
- `src/openflight/server.py` — pass club angle to Shot object (`club_angle_deg` field already exists)
- `tests/test_kld7.py` — add tests with synthetic club head signals

## Data Available for Development

Session logs with RADC data from both vertical and horizontal radars are in `session_logs/`. The RADC frames in the ring buffer contain the club head signal — it just needs to be found and extracted.

Use the capture script to collect RADC data with known club types:
```bash
./scripts/capture_kld7_radc.py --port /dev/kld7_vertical --ops243-port /dev/ttyACM0 --duration 60 --club 7i
```
Then analyze offline with `scripts/analyze_kld7_radc.py`.

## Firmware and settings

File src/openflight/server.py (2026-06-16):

"""
WebSocket server for OpenFlight UI.

Provides real-time shot data to the web frontend via Flask-SocketIO.
"""

import json
import logging
import os
import random
import statistics
import sys
import threading
import time
from datetime import datetime
from pathlib import Path
from typing import List, Optional

from flask import Flask, Response, send_from_directory
from flask_cors import CORS
from flask_socketio import SocketIO

from .ballistics import resolve_launch, simulate
from .launch_monitor import ClubType, Shot
from .ops243 import Direction, SpeedReading, set_show_raw_readings
from .rolling_buffer.monitor import estimate_carry_with_spin, get_optimal_spin_for_ball_speed
from .session_logger import get_session_logger, init_session_logger, log_session_error

# Configure logging
logger = logging.getLogger(__name__)

# Camera imports (optional)
REPO_ROOT = Path(__file__).resolve().parents[2]
FRONTEND_DIST_DIR = REPO_ROOT / "ui" / "dist"
FRONTEND_SOURCE_DIR = REPO_ROOT / "ui"

try:
    import cv2

    from .camera_tracker import CameraTracker

    CV2_AVAILABLE = True
except ImportError:
    CV2_AVAILABLE = False
    CameraTracker = None

try:
    from picamera2 import Picamera2

    PICAMERA_AVAILABLE = True
except ImportError:
    PICAMERA_AVAILABLE = False

# DTL swing camera (optional)
try:
    from .dtl_camera import (
        DTLCameraRecorder,
        DTLCameraStatus,
        DTLConfig,
        MockDTLCameraRecorder,
        SavedClip,
    )
    DTL_AVAILABLE = True
except ImportError:
    DTL_AVAILABLE = False


app = Flask(__name__, static_folder=str(FRONTEND_DIST_DIR), static_url_path="")
CORS(app)
socketio = SocketIO(app, cors_allowed_origins="*", async_mode="threading")

# Global state
monitor = None
mock_mode: bool = False
debug_mode: bool = False
debug_log_file = None
debug_log_path: Optional[Path] = None

# K-LD7 angle radars (vertical = launch angle, horizontal = club path)
kld7_vertical = None
kld7_horizontal = None
experimental_kld7_radc_tuning: bool = False
experimental_kld7_raw_radc_logging: bool = False

# Ballistic model toggle. When True, shot carry comes from the physics
# simulator whenever a vertical launch angle is available. When False
# (default), all carry computations go through the legacy table estimator.
# The simulator is opt-in until coefficients are validated against TM.
ballistics_enabled: bool = False

_DEFAULT_KLD7_RADC_TUNING = {
    "radc_speed_tolerance_mph": 10.0,
    "radc_centroid_floor_frac": 0.5,
    "radc_spectrum_source": "f1a",
    "radc_ops_bin_outlier_tol": 25,
    "radc_ops_bin_outlier_penalty": 10.0,
    "radc_ops_anchored_peak_min_snr": 5.0,
    "radc_vertical_impact_energy_threshold": 3.0,
    "radc_horizontal_impact_energy_threshold": 1.85,
    "radc_horizontal_retry_impact_energy_threshold": 0.5,
    "radc_horizontal_angle_limit_deg": 15.0,
}
active_kld7_radc_tuning: dict = dict(_DEFAULT_KLD7_RADC_TUNING)

# Camera state
camera: Optional["Picamera2"] = None
camera_tracker: Optional["CameraTracker"] = None
camera_enabled: bool = False
camera_streaming: bool = False
camera_thread: Optional[threading.Thread] = None
camera_stop_event: Optional[threading.Event] = None
ball_detected: bool = False
ball_detection_confidence: float = 0.0
latest_frame: Optional[bytes] = None
frame_lock = threading.Lock()
shutdown_lock = threading.Lock()
shutdown_cleanup_started = False


def _run_shutdown_step(name: str, callback) -> None:
    """Run one shutdown step without preventing later hardware cleanup."""
    try:
        callback()
    except Exception:
        logger.warning("[SERVER] Shutdown cleanup failed during %s", name, exc_info=True)


def _cleanup_hardware_for_shutdown() -> None:
    """Stop hardware resources in an order that leaves serial devices reusable."""
    global shutdown_cleanup_started  # pylint: disable=global-statement

    with shutdown_lock:
        if shutdown_cleanup_started:
            logger.info("[SERVER] Shutdown cleanup already started")
            return
        shutdown_cleanup_started = True

    if kld7_vertical:
        _run_shutdown_step("K-LD7 vertical stop", kld7_vertical.stop)
    if kld7_horizontal:
        _run_shutdown_step("K-LD7 horizontal stop", kld7_horizontal.stop)

    _run_shutdown_step("camera thread stop", stop_camera_thread)
    if camera:
        _run_shutdown_step("camera stop", camera.stop)
        _run_shutdown_step("camera close", camera.close)

    _run_shutdown_step("launch monitor stop", stop_monitor)


def _shutdown_process_after_delay(delay_s: float = 0.5) -> None:
    """Give the HTTP/WebSocket response time to flush, then clean up and exit."""
    time.sleep(delay_s)
    _cleanup_hardware_for_shutdown()
    logger.info("[SERVER] Goodbye")
    os._exit(0)


# Baseline launch angles by club (TrackMan data)
# Format: (avg_launch_deg, avg_ball_speed_mph, deg_per_mph_deviation)
_CLUB_LAUNCH_MODEL = {
    ClubType.DRIVER: (11.0, 143, 0.15),
    ClubType.WOOD_3: (12.5, 135, 0.18),
    ClubType.WOOD_5: (14.0, 128, 0.20),
    ClubType.WOOD_7: (15.5, 122, 0.20),
    ClubType.HYBRID_3: (13.5, 123, 0.22),
    ClubType.HYBRID_5: (15.0, 118, 0.22),
    ClubType.HYBRID_7: (16.5, 112, 0.25),
    ClubType.HYBRID_9: (18.0, 106, 0.25),
    ClubType.IRON_2: (13.0, 120, 0.25),
    ClubType.IRON_3: (14.5, 118, 0.25),
    ClubType.IRON_4: (16.0, 114, 0.28),
    ClubType.IRON_5: (17.5, 110, 0.28),
    ClubType.IRON_6: (19.0, 105, 0.30),
    ClubType.IRON_7: (20.5, 100, 0.30),
    ClubType.IRON_8: (23.0, 94, 0.30),
    ClubType.IRON_9: (25.5, 88, 0.30),
    ClubType.PW: (28.0, 82, 0.30),
    ClubType.GW: (30.0, 76, 0.30),
    ClubType.SW: (32.0, 73, 0.30),
    ClubType.LW: (35.0, 70, 0.30),
    ClubType.UNKNOWN: (18.0, 120, 0.25),
}

# Optimal smash factor by club type (ball_speed / club_speed)
_OPTIMAL_SMASH = {
    ClubType.DRIVER: 1.48,
    ClubType.WOOD_3: 1.44,
    ClubType.WOOD_5: 1.42,
    ClubType.WOOD_7: 1.42,
    ClubType.HYBRID_3: 1.39,
    ClubType.HYBRID_5: 1.38,
    ClubType.HYBRID_7: 1.37,
    ClubType.HYBRID_9: 1.36,
    ClubType.IRON_2: 1.37,
    ClubType.IRON_3: 1.36,
    ClubType.IRON_4: 1.35,
    ClubType.IRON_5: 1.35,
    ClubType.IRON_6: 1.34,
    ClubType.IRON_7: 1.34,
    ClubType.IRON_8: 1.33,
    ClubType.IRON_9: 1.33,
    ClubType.PW: 1.25,
    ClubType.GW: 1.23,
    ClubType.SW: 1.22,
    ClubType.LW: 1.20,
    ClubType.UNKNOWN: 1.35,
}

# Max smash factor adjustment in degrees (clamped to prevent floor-dependence)
_MAX_SMASH_ADJ_LOW = -3.0  # max degrees to subtract for thin/toe hits
_MAX_SMASH_ADJ_HIGH = 2.0  # max degrees to add for high-face hits

# Degrees of launch angle change per 0.01 smash factor unit
_SMASH_DEG_PER_HUNDREDTH_LOW = 0.4  # below optimal (thin hits penalized more)
_SMASH_DEG_PER_HUNDREDTH_HIGH = 0.2  # above optimal

# Spin rate adjustment: degrees per 500 rpm deviation from optimal
_SPIN_DEG_PER_500RPM = 0.3
# Max spin adjustment in degrees (clamped like smash)
_MAX_SPIN_ADJ = 2.0

# Radar launch sanity guard. These windows are intentionally wide:
# they are meant to catch obvious K-LD7 false positives, not to micromanage
# normal shot-to-shot variation or mishits.
_RADAR_SANITY_LOW_CONF_BONUS_DEG = 5.0


def _react_app_dir() -> Path:
    """Return the best available directory containing the React index file."""
    candidates = [
        Path(app.static_folder) if app.static_folder else FRONTEND_DIST_DIR,
        FRONTEND_DIST_DIR,
        FRONTEND_SOURCE_DIR,
    ]
    for candidate in candidates:
        if (candidate / "index.html").is_file():
            return candidate
    return candidates[0]


def estimate_launch_angle(
    club: ClubType,
    ball_speed_mph: float,
    club_speed_mph: Optional[float] = None,
    spin_rpm: Optional[float] = None,
) -> tuple:
    """
    Estimate launch angle from club type, ball speed, and optional smash/spin data.

    Uses TrackMan averages as baseline, then adjusts for:
    - Ball speed deviation from club average
    - Smash factor deviation from optimal (if club_speed provided)
    - Spin rate deviation from optimal (if spin_rpm provided)

    Returns (vertical_angle, confidence).
    """
    avg_launch, avg_speed, deg_per_mph = _CLUB_LAUNCH_MODEL.get(club, (18.0, 120, 0.25))

    # Slower than average → higher launch, faster → lower launch
    speed_delta = ball_speed_mph - avg_speed
    adjustment = -speed_delta * deg_per_mph

    confidence = 0.2

    # Smash factor adjustment: compare actual smash to optimal for this club
    if club_speed_mph is not None and club_speed_mph > 0:
        smash_factor = ball_speed_mph / club_speed_mph
        optimal_smash = _OPTIMAL_SMASH.get(club, 1.35)
        smash_delta = smash_factor - optimal_smash

        if smash_delta < 0:
            smash_adj = max(_MAX_SMASH_ADJ_LOW, smash_delta * 100 * _SMASH_DEG_PER_HUNDREDTH_LOW)
        else:
            smash_adj = min(_MAX_SMASH_ADJ_HIGH, smash_delta * 100 * _SMASH_DEG_PER_HUNDREDTH_HIGH)
        adjustment += smash_adj

        confidence = 0.35

    # Spin rate adjustment: compare actual spin to optimal for this club/speed
    if spin_rpm is not None and spin_rpm > 0:
        optimal_spin = get_optimal_spin_for_ball_speed(ball_speed_mph, club)
        spin_delta = spin_rpm - optimal_spin
        spin_adj = (spin_delta / 500.0) * _SPIN_DEG_PER_500RPM
        spin_adj = max(-_MAX_SPIN_ADJ, min(_MAX_SPIN_ADJ, spin_adj))
        adjustment += spin_adj

        if confidence >= 0.35:
            confidence = 0.5
        else:
            confidence = 0.35

    launch_angle = max(5.0, round(avg_launch + adjustment, 1))

    return (launch_angle, confidence)


def _radar_launch_base_delta_deg(club: ClubType) -> float:
    """Return a conservative club-family window for radar launch sanity checks."""
    if club in {ClubType.PW, ClubType.GW, ClubType.SW, ClubType.LW}:
        return 22.0
    if club in {ClubType.IRON_6, ClubType.IRON_7, ClubType.IRON_8, ClubType.IRON_9}:
        return 20.0
    return 18.0


def radar_launch_is_plausible(
    radar_angle_deg: Optional[float],
    club: ClubType,
    ball_speed_mph: float,
    club_speed_mph: Optional[float] = None,
    spin_rpm: Optional[float] = None,
) -> tuple[bool, dict]:
    """Check whether a radar launch angle is plausible for the shot profile.

    This is a wide guardrail meant to reject only obvious radar outliers. When
    the selected club is unknown or the angle is missing, we skip the guard.
    """
    if radar_angle_deg is None or club in {None, ClubType.UNKNOWN} or ball_speed_mph <= 0:
        return True, {
            "skipped": True,
            "expected_launch_deg": None,
            "allowed_delta_deg": None,
            "delta_deg": None,
        }

    expected_launch_deg, estimate_conf = estimate_launch_angle(
        club,
        ball_speed_mph,
        club_speed_mph=club_speed_mph,
        spin_rpm=spin_rpm,
    )
    allowed_delta_deg = (
        _radar_launch_base_delta_deg(club)
        + (1.0 - estimate_conf) * _RADAR_SANITY_LOW_CONF_BONUS_DEG
    )
    delta_deg = abs(radar_angle_deg - expected_launch_deg)
    if radar_angle_deg <= expected_launch_deg:
        plausible = 0.0 <= radar_angle_deg <= 45.0
    else:
        plausible = delta_deg <= allowed_delta_deg

    return plausible, {
        "skipped": False,
        "expected_launch_deg": round(expected_launch_deg, 1),
        "allowed_delta_deg": round(allowed_delta_deg, 1),
        "delta_deg": round(delta_deg, 1),
    }


def _vertical_soft_launch_lane_deg(club: ClubType) -> tuple[float, float]:
    """Return broad club-family lanes for low-confidence vertical radar candidates."""
    if club == ClubType.DRIVER:
        return (4.0, 22.0)
    if club in {ClubType.WOOD_3, ClubType.WOOD_5, ClubType.WOOD_7}:
        return (5.0, 24.0)
    if club in {ClubType.HYBRID_3, ClubType.HYBRID_5, ClubType.HYBRID_7, ClubType.HYBRID_9}:
        return (6.0, 26.0)
    if club in {ClubType.IRON_2, ClubType.IRON_3, ClubType.IRON_4, ClubType.IRON_5}:
        return (5.0, 25.0)
    if club in {ClubType.IRON_6, ClubType.IRON_7, ClubType.IRON_8, ClubType.IRON_9}:
        return (7.0, 28.0)
    if club in {ClubType.PW, ClubType.GW, ClubType.SW, ClubType.LW}:
        return (10.0, 45.0)
    return (5.0, 35.0)


def _select_vertical_radar_launch(kld7_angle, shot: Shot) -> tuple[bool, dict]:
    """Decide whether a vertical K-LD7 candidate should set the shot launch angle.

    High-confidence candidates keep the existing production behavior. Marginal
    candidates get a stricter second pass: they must agree with the launch
    estimator, sit inside a club-family lane, and avoid very long frame spans
    that often indicate clutter rather than the ball transit. Very low
    confidence candidates are still rejected, but near-threshold candidates
    that pass every other guard are allowed through so the UI can show them as
    low-confidence radar measurements instead of silently replacing them with
    the launch estimator.
    """
    details = {
        "accepted": False,
        "selection_reason": "no_candidate",
        "acceptance_path": None,
        "strict_min_confidence": _MIN_VERTICAL_RADAR_CONFIDENCE,
        "soft_min_confidence": _MIN_VERTICAL_SOFT_RADAR_CONFIDENCE,
        "low_confidence_min_confidence": _MIN_VERTICAL_LOW_CONFIDENCE_RADAR_CONFIDENCE,
        "soft_allowed_delta_deg": _VERTICAL_SOFT_ESTIMATE_DELTA_DEG,
        "soft_max_frame_count": _VERTICAL_SOFT_MAX_FRAME_COUNT,
    }
    if not kld7_angle or kld7_angle.vertical_deg is None:
        return False, details

    radar_angle_deg = kld7_angle.vertical_deg
    plausible, guard_details = radar_launch_is_plausible(
        radar_angle_deg=radar_angle_deg,
        club=shot.club,
        ball_speed_mph=shot.ball_speed_mph,
        club_speed_mph=shot.club_speed_mph,
        spin_rpm=shot.spin_rpm,
    )
    details.update(guard_details)
    if not plausible:
        details["selection_reason"] = "implausible_launch"
        return False, details

    if kld7_angle.confidence >= _MIN_VERTICAL_RADAR_CONFIDENCE:
        details["accepted"] = True
        details["selection_reason"] = "strict_accept"
        details["acceptance_path"] = "strict"
        return True, details

    if kld7_angle.confidence < _MIN_VERTICAL_LOW_CONFIDENCE_RADAR_CONFIDENCE:
        details["selection_reason"] = "low_confidence"
        return False, details

    if guard_details.get("skipped"):
        details["selection_reason"] = "soft_guard_unavailable"
        return False, details

    lane_min, lane_max = _vertical_soft_launch_lane_deg(shot.club)
    details["soft_lane_min_deg"] = lane_min
    details["soft_lane_max_deg"] = lane_max
    if radar_angle_deg < lane_min or radar_angle_deg > lane_max:
        details["selection_reason"] = "outside_soft_lane"
        return False, details

    delta_deg = guard_details.get("delta_deg")
    if delta_deg is None or delta_deg > _VERTICAL_SOFT_ESTIMATE_DELTA_DEG:
        details["selection_reason"] = "estimator_delta_too_large"
        return False, details

    if kld7_angle.num_frames <= 0:
        details["selection_reason"] = "no_candidate_frames"
        return False, details

    if (
        kld7_angle.num_frames > _VERTICAL_SOFT_MAX_FRAME_COUNT
        and delta_deg > _VERTICAL_SOFT_TIGHT_DELTA_FOR_LONG_FRAME_DEG
    ):
        details["selection_reason"] = "suspicious_frame_span"
        return False, details

    details["accepted"] = True
    if kld7_angle.confidence >= _MIN_VERTICAL_SOFT_RADAR_CONFIDENCE:
        details["selection_reason"] = "soft_accept"
        details["acceptance_path"] = "soft"
    else:
        details["selection_reason"] = "low_confidence_accept"
        details["acceptance_path"] = "low_confidence"
    return True, details


def _select_horizontal_radar_launch(kld7_angle, horizontal_limit: float) -> tuple[bool, dict]:
    """Decide whether a horizontal K-LD7 candidate should set the shot angle."""
    soft_limit = min(_HORIZONTAL_SOFT_ANGLE_LIMIT_DEG, max(horizontal_limit, 0.0))
    details = {
        "accepted": False,
        "selection_reason": "no_candidate",
        "acceptance_path": None,
        "horizontal_limit_deg": horizontal_limit,
        "strict_min_confidence": _MIN_HORIZONTAL_RADAR_CONFIDENCE,
        "soft_min_confidence": _MIN_HORIZONTAL_SOFT_RADAR_CONFIDENCE,
        "soft_angle_limit_deg": soft_limit,
        "soft_max_frame_count": _HORIZONTAL_SOFT_MAX_FRAME_COUNT,
        "near_limit_min_confidence": _HORIZONTAL_NEAR_LIMIT_MIN_CONFIDENCE,
        "near_limit_max_frame_count": _HORIZONTAL_NEAR_LIMIT_MAX_FRAMES,
    }
    if not kld7_angle or kld7_angle.horizontal_deg is None:
        return False, details

    abs_angle = abs(kld7_angle.horizontal_deg)
    if abs_angle > horizontal_limit:
        details["selection_reason"] = "outside_horizontal_limit"
        return False, details

    near_limit_angle = horizontal_limit * _HORIZONTAL_NEAR_LIMIT_FRACTION
    if (
        abs_angle >= near_limit_angle
        and kld7_angle.num_frames <= _HORIZONTAL_NEAR_LIMIT_MAX_FRAMES
        and kld7_angle.confidence < _HORIZONTAL_NEAR_LIMIT_MIN_CONFIDENCE
    ):
        details["selection_reason"] = "weak_near_limit"
        details["near_limit_angle_deg"] = round(near_limit_angle, 1)
        return False, details

    if kld7_angle.confidence >= _MIN_HORIZONTAL_RADAR_CONFIDENCE:
        details["accepted"] = True
        details["selection_reason"] = "strict_accept"
        details["acceptance_path"] = "strict"
        return True, details

    if kld7_angle.confidence < _MIN_HORIZONTAL_SOFT_RADAR_CONFIDENCE:
        details["selection_reason"] = "low_confidence"
        return False, details

    if abs_angle > soft_limit:
        details["selection_reason"] = "outside_soft_lane"
        return False, details

    if kld7_angle.num_frames <= 0:
        details["selection_reason"] = "no_candidate_frames"
        return False, details

    if kld7_angle.num_frames > _HORIZONTAL_SOFT_MAX_FRAME_COUNT:
        details["selection_reason"] = "suspicious_frame_span"
        return False, details

    details["accepted"] = True
    details["selection_reason"] = "soft_accept"
    details["acceptance_path"] = "soft"
    return True, details


def _ensure_user_facing_launch_angles(shot: Shot) -> None:
    """Guarantee emitted shots have launch angles without overwriting measurements."""
    estimated: tuple[float, float] | None = None

    if shot.launch_angle_vertical is None:
        estimated = estimate_launch_angle(
            shot.club,
            shot.ball_speed_mph,
            club_speed_mph=shot.club_speed_mph,
            spin_rpm=shot.spin_rpm,
        )
        shot.launch_angle_vertical = estimated[0]
        shot.launch_angle_confidence = estimated[1]
        shot.launch_angle_vertical_confidence = estimated[1]
        shot.launch_angle_vertical_source = "estimated"
        shot.angle_source = "estimated"
        logger.info(
            "[SERVER] Angle source: estimated (%.1f°, conf=%.0f%%)",
            estimated[0],
            estimated[1] * 100,
        )

    if shot.launch_angle_horizontal is None:
        shot.launch_angle_horizontal = 0.0
        if shot.launch_angle_confidence is None:
            if estimated is None:
                estimated = estimate_launch_angle(
                    shot.club,
                    shot.ball_speed_mph,
                    club_speed_mph=shot.club_speed_mph,
                    spin_rpm=shot.spin_rpm,
                )
            shot.launch_angle_confidence = estimated[1]
        if shot.launch_angle_horizontal_confidence is None:
            if estimated is None:
                estimated = estimate_launch_angle(
                    shot.club,
                    shot.ball_speed_mph,
                    club_speed_mph=shot.club_speed_mph,
                    spin_rpm=shot.spin_rpm,
                )
            shot.launch_angle_horizontal_confidence = estimated[1]
        shot.launch_angle_horizontal_source = "estimated"
        if shot.angle_source is None:
            shot.angle_source = "estimated"
        logger.info("[SERVER] Horizontal angle source: neutral estimate (0.0°)")


# K-LD7 produces ~34 RADC frames/sec at 3 Mbaud. With buffer_seconds=6
# the steady-state buffer is ~204 frames. If the snapshot at shot time
# is dramatically less than that, the radar's stream rate dropped.
# Surface as WARN so cabling/USB issues are visible without a replay.
_KLD7_FRAME_HZ = 34.0
_KLD7_BUFFER_SECONDS = 6.0
_KLD7_BUFFER_UNDERFILL_FRAC = 0.5
_KLD7_POST_SHOT_CAPTURE_DELAY_S = 0.18
_MIN_VERTICAL_RADAR_CONFIDENCE = 0.80
_MIN_VERTICAL_SOFT_RADAR_CONFIDENCE = 0.68
_MIN_VERTICAL_LOW_CONFIDENCE_RADAR_CONFIDENCE = 0.65
_VERTICAL_SOFT_ESTIMATE_DELTA_DEG = 4.5
_VERTICAL_SOFT_MAX_FRAME_COUNT = 40
_VERTICAL_SOFT_TIGHT_DELTA_FOR_LONG_FRAME_DEG = 2.0
_MIN_HORIZONTAL_RADAR_CONFIDENCE = 0.40
_MIN_HORIZONTAL_SOFT_RADAR_CONFIDENCE = 0.30
_HORIZONTAL_SOFT_ANGLE_LIMIT_DEG = 5.0
_HORIZONTAL_SOFT_MAX_FRAME_COUNT = 40
_HORIZONTAL_NEAR_LIMIT_FRACTION = 0.80
_HORIZONTAL_NEAR_LIMIT_MAX_FRAMES = 2
_HORIZONTAL_NEAR_LIMIT_MIN_CONFIDENCE = 0.80


def _maybe_wait_for_kld7_post_shot_frames(shot_timestamp: float) -> None:
    """Let the K-LD7 stream collect post-impact RADC frames for extraction.

    TrackMan test logs showed immediate snapshots ending at or just before
    the OPS impact timestamp, leaving the configured post-shot extraction
    window empty. Wait only until the bounded target time; if processing is
    already past that point, this adds no latency.
    """
    target_time = shot_timestamp + _KLD7_POST_SHOT_CAPTURE_DELAY_S
    delay_s = target_time - time.time()
    if delay_s <= 0:
        return
    logger.info(
        "[SERVER] Waiting %.0fms for post-impact K-LD7 RADC frames",
        delay_s * 1000.0,
    )
    time.sleep(delay_s)
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

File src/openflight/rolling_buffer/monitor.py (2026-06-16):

"""
Rolling Buffer Monitor - Alternative to LaunchMonitor for rolling buffer mode.

Provides the same interface as LaunchMonitor but uses rolling buffer capture
and post-processing for higher resolution speed data and spin detection.
"""

import logging
import statistics
import threading
import time
from datetime import datetime
from typing import Callable, List, Optional

from ..launch_monitor import ClubType, Shot, estimate_carry_distance
from ..ops243 import OPS243Radar, SpeedReading
from ..session_logger import get_session_logger, log_session_error
from .processor import RollingBufferProcessor
from .trigger import create_trigger
from .types import ProcessedCapture

logger = logging.getLogger("openflight.rolling_buffer.monitor")


def get_optimal_spin_for_ball_speed(
    ball_speed_mph: float, club: ClubType = ClubType.DRIVER
) -> float:
    """
    Get optimal spin rate for a given ball speed.

    Based on TrackMan/PING research data:
    - Higher ball speeds require LESS spin for optimal carry
    - Lower ball speeds need MORE spin to maintain lift

    Reference data points (driver):
    - 120 mph ball speed → ~2900 rpm optimal
    - 140 mph ball speed → ~2700 rpm optimal
    - 160 mph ball speed → ~2550 rpm optimal (Tour average zone)
    - 180 mph ball speed → ~2050 rpm optimal

    Args:
        ball_speed_mph: Ball speed in mph
        club: Club type (affects optimal spin)

    Returns:
        Optimal spin rate in RPM
    """
    # Driver optimal spin (baseline) - interpolated from TrackMan/PING data
    # Table: (min_speed, base_rpm_at_upper_bound, rpm_per_mph_below_upper, upper_bound)
    _spin_table = [
        (180, 2050, 0, 999),
        (170, 2050, 25, 180),
        (160, 2300, 25, 170),
        (140, 2550, 7.5, 160),
        (120, 2700, 10, 140),
        (100, 2900, 10, 120),
    ]

    optimal = 3200  # Default for speeds below 100 mph
    for min_speed, base_rpm, rpm_per_mph, upper in _spin_table:
        if ball_speed_mph >= min_speed:
            optimal = base_rpm + (upper - ball_speed_mph) * rpm_per_mph
            break

    # Adjust for club type - irons need more spin
    club_spin_multipliers = {
        ClubType.DRIVER: 1.0,
        ClubType.WOOD_3: 1.15,
        ClubType.WOOD_5: 1.25,
        ClubType.WOOD_7: 1.32,
        ClubType.HYBRID_3: 1.45,
        ClubType.HYBRID_5: 1.55,
        ClubType.HYBRID_7: 1.65,
        ClubType.HYBRID_9: 1.75,
        ClubType.IRON_2: 1.5,
        ClubType.IRON_3: 1.6,
        ClubType.IRON_4: 1.8,
        ClubType.IRON_5: 2.0,
        ClubType.IRON_6: 2.2,
        ClubType.IRON_7: 2.5,
        ClubType.IRON_8: 2.8,
        ClubType.IRON_9: 3.2,
        ClubType.PW: 3.6,
        ClubType.GW: 4.1,
        ClubType.SW: 4.3,
        ClubType.LW: 4.6,
        ClubType.UNKNOWN: 1.0,
    }

    multiplier = club_spin_multipliers.get(club, 1.0)
    return optimal * multiplier


def estimate_carry_with_spin(
    ball_speed_mph: float,
    spin_rpm: float,
    club: ClubType = ClubType.DRIVER,
    club_speed_mph: Optional[float] = None,
) -> float:
    """
    Estimate carry distance using ball speed, spin rate, and optional club speed.

    Based on TrackMan/PING research data and physics:
    - Ball speed is primary factor (~85% of distance variance)
    - Spin rate affects trajectory via Magnus effect (lift)
    - Optimal spin varies inversely with ball speed
    - Smash factor validates contact quality

    Reference data points (driver, optimal conditions):
    - 120 mph ball speed → ~198 yards carry
    - 140 mph ball speed → ~231 yards carry
    - 160 mph ball speed → ~271 yards carry (Tour average: 167 mph → 275 yds)
    - 180 mph ball speed → ~310 yards carry

    Spin effects:
    - Too LOW: Ball "falls out of sky" - significant distance loss
    - Optimal: Maximum carry for given ball speed
    - Too HIGH: Ball "balloons" - moderate distance loss

    Args:
        ball_speed_mph: Ball speed in mph
        spin_rpm: Spin rate in RPM
        club: Club type for distance calculation
        club_speed_mph: Optional club head speed for smash factor validation

    Returns:
        Estimated carry distance in yards
    """
    # Get base carry from existing lookup table (TrackMan-derived)
    base_carry = estimate_carry_distance(ball_speed_mph, club)

    # Calculate optimal spin for this ball speed and club
    optimal_spin = get_optimal_spin_for_ball_speed(ball_speed_mph, club)

    # Calculate spin deviation
    spin_delta = spin_rpm - optimal_spin
    spin_delta_abs = abs(spin_delta)

    # Apply asymmetric spin adjustment
    # Low spin hurts MORE than high spin (ball falls out of sky vs balloons)
    if spin_delta < 0:
        # LOW SPIN: More severe penalty
        # Research shows ~1.2 yards lost per 100 rpm below optimal
        # Cap at 18% max penalty for extremely low spin
        penalty_per_100rpm = 0.012  # 1.2% per 100 rpm
        spin_factor = 1.0 - (spin_delta_abs / 100) * penalty_per_100rpm
        spin_factor = max(0.82, spin_factor)
    else:
        # HIGH SPIN: Less severe penalty (ball balloons but still carries)
        # Research shows ~0.8 yards lost per 100 rpm above optimal
        # Cap at 12% max penalty for extremely high spin
        penalty_per_100rpm = 0.008  # 0.8% per 100 rpm
        spin_factor = 1.0 - (spin_delta_abs / 100) * penalty_per_100rpm
        spin_factor = max(0.88, spin_factor)

    # Slight bonus for being very close to optimal (within 200 rpm)
    if spin_delta_abs < 200:
        spin_factor = min(1.02, spin_factor + 0.01)

    # Smash factor quality adjustment (if club speed available)
    smash_factor_adj = 1.0
    if club_speed_mph and club_speed_mph > 0:
        smash = ball_speed_mph / club_speed_mph

        # Optimal smash factors by club type
        optimal_smash = {
            ClubType.DRIVER: 1.48,
            ClubType.WOOD_3: 1.44,
            ClubType.WOOD_5: 1.42,
            ClubType.WOOD_7: 1.41,
            ClubType.HYBRID_3: 1.39,
            ClubType.HYBRID_5: 1.37,
            ClubType.HYBRID_7: 1.35,
            ClubType.HYBRID_9: 1.33,
            ClubType.IRON_2: 1.36,
            ClubType.IRON_3: 1.35,
            ClubType.IRON_4: 1.33,
            ClubType.IRON_5: 1.31,
            ClubType.IRON_6: 1.29,
            ClubType.IRON_7: 1.27,
            ClubType.IRON_8: 1.25,
            ClubType.IRON_9: 1.23,
            ClubType.PW: 1.21,
            ClubType.GW: 1.19,
            ClubType.SW: 1.18,
            ClubType.LW: 1.17,
            ClubType.UNKNOWN: 1.35,
        }

        target_smash = optimal_smash.get(club, 1.35)
        smash_delta = target_smash - smash
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

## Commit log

2026-02-22 Add DTL (down-the-line) swing camera recording module
    Adds a new dtl_camera module that records swing video clips triggered by
    shot detection. Uses picamera2's CircularOutput for an H.264 ring buffer
    (2s pre-impact) and records 3s post-impact on each shot. Integrates with
    the existing shot callback, session logger, and WebSocket status system.
    - DTLCameraRecorder: ring buffer + background clip save thread
    - MockDTLCameraRecorder: for testing/dev without Pi HQ Camera hardware
    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
2026-02-22 Fix DTL camera: CircularOutput API, save pattern, clip callback, IMX708 docs
    - CircularOutput buffersize is frame count, not bytes (was OOM)
    - _save_clip uses fileoutput/start/stop instead of outputframe loop
    - Add clip_callback to both recorder classes for real metadata delivery
    - Move session logging + WebSocket emit to clip_callback (non-stale)
    - Update docstrings from IMX477 to IMX708 (Camera Module v3 Wide)
    - Add 6 new tests: buffer calc, clip callback, exception swallowing
    [recorder.py, server.py, test_dtl_camera.py]
2026-02-23 Add new STL files for launch monitor box components and update changelog
    [ANGLE STOP.STL, LCD ANGLE BRACKET.STL, LCD PLATE.STL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]
2026-02-25 Add Pi kiosk launcher script docs and update hardware info
    - Document launch-kiosk-local.sh in CLAUDE.md, changelog, and Pi setup guide
    - Add "Camera Not Detected" troubleshooting with CSI port mapping (CAM0 for camera, other port for display)
    - Update parts list: HQ Camera + Arducam lens -> Camera Module 3 Wide (IMX708)
    - Fix camera module description: YOLO -> Hough circle detection (default)
2026-02-25 Add sensor fusion roadmap and shaft IMU parts list
    - Engineering backlog: OPS243-C FMCW range tracking (P2), dual-radar + camera
    sensor fusion (P3), shaft IMU for club data (P3)
    - Parts list: shaft IMU section with Adafruit and Amazon sourcing options,
    wiring diagram, updated to 6-axis MPU-6050 (9-axis unnecessary)
    - Updated execution order to 9 items
2026-06-16 docs: add wiring diagram for OPS243-A + SEN-14262 build
    SVG schematic for the radar-only build (OPS243-A radar, SEN-14262 sound
    trigger, Pi 5, 7%s touchscreen): GATE -> HOST_INT (J3 pin 3), common
    ground, 3.3V power, USB/DSI links, and the R17 47k solder note.
2026-06-16 docs: clarify what the R17 resistor is and where it goes
    Expand the sound-trigger guide: R17 is an empty footprint (not an
    existing part), sits in parallel with R3 to cut preamp gain, why 3.3V
    operation needs it, non-polarized, plus a clap-test check and a link to
    SparkFun board photos.
